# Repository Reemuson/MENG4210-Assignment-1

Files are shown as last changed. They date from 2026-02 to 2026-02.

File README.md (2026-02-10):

<p align="center" width="100%">
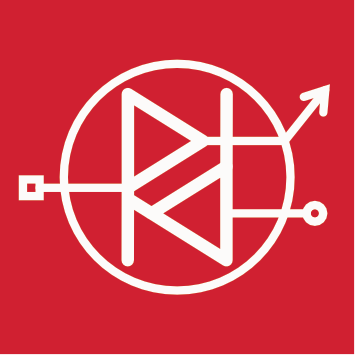
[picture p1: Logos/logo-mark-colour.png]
  
</p>

<h1 align="center">INPUT PROTECTION</h1>

<p align="center" width="100%">
  <a href="https://github.com/Reemuson/MENG4210-Assignment-1/actions/workflows/ci.yaml">
    
  </a>
</p>

<p align="center" width="100%">
    
</p>

***

<p align="center">
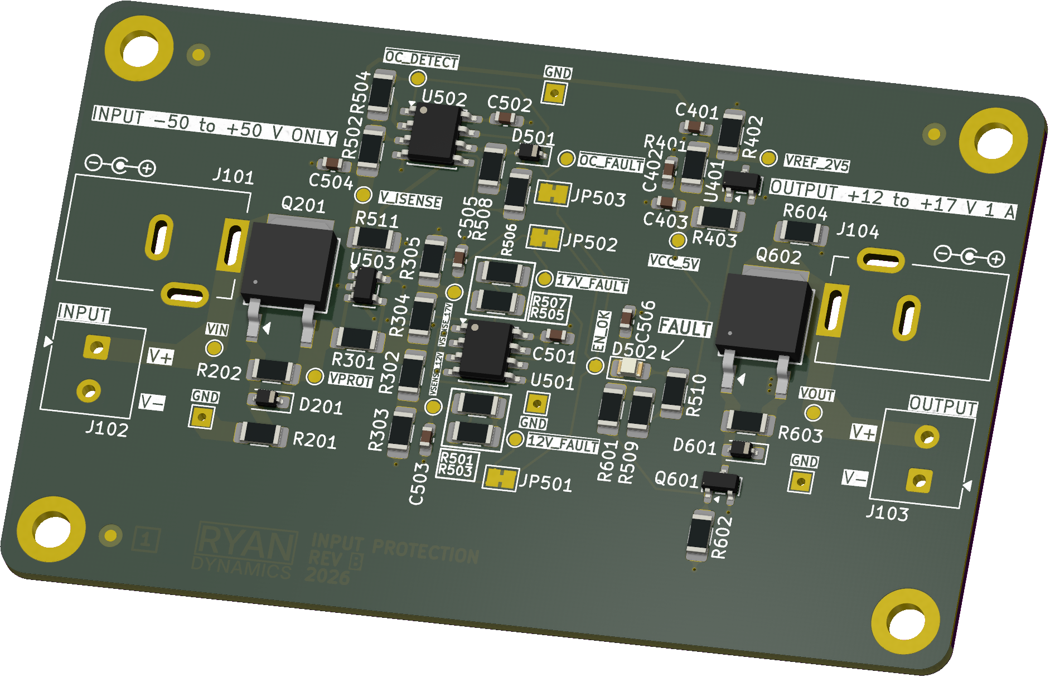
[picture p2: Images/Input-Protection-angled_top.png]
3D Top Angled
  
&nbsp; &nbsp; &nbsp; &nbsp;
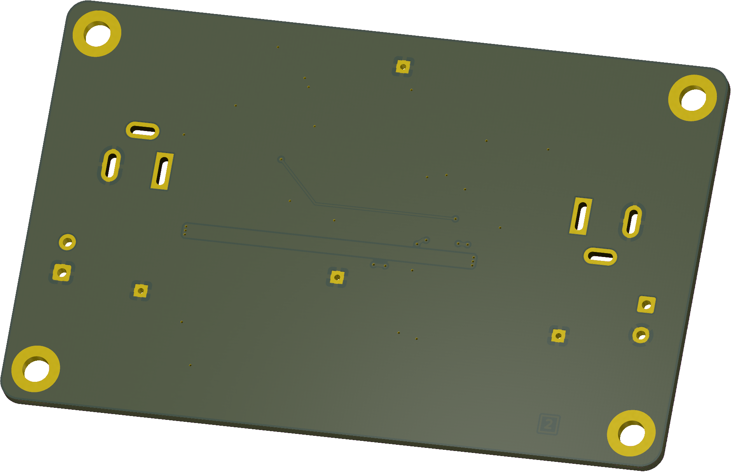
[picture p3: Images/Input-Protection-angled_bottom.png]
3D Bottom Angled
  
</p>

***

## SPECIFICATIONS

| Parameter | Value | 
| --- | --- |
| Dimensions | 80.0 × 50.0 mm |

***

## DIRECTORY STRUCTURE

    .
    ├─ Computations       # Misc calculations
    ├─ HTML               # HTML files for generated webpage
    ├─ Images             # Pictures and renders
    │
    ├─ kibot_resources    # External resources for KiBot
    │  ├─ colors          # Color theme for KiCad
    │  ├─ fonts           # Fonts used in the project
    │  ├─ scripts         # External scripts used with KiBot
    │  └─ templates       # Templates for KiBot generated reports
    │
    ├─ kibot_yaml         # KiBot YAML config files
    ├─ KiRI               # KiRI (PCB diff viewer) files
    │
    ├─ lib                # KiCad footprint and symbol libraries
    │  ├─ 3d_models       # Component 3D models
    │  ├─ lib_fp          # Footprint libraries
    │  └─ lib_sym         # Symbol libraries
    │
    ├─ Logos              # Logos
    │
    ├─ Manufacturing      # Assembly and fabrication documents
    │  ├─ Assembly        # Assembly documents (BoM, pos, notes)
    │  │
    │  └─ Fabrication     # Fabrication documents (ZIP, notes)
    │     ├─ Drill Tables # CSV drill tables
    │     └─ Gerbers      # Gerbers
    │
    ├─ Report             # Reports for ERC/DRC
    ├─ Schematic          # PDF of schematic
    ├─ Templates          # Title block templates
    ├─ Testing
    │  └─ Testpoints      # Testpoints tables      
    │
    └─ Variants           # Outputs for assembly variants

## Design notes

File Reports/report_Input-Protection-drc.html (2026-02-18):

Logo

(https://github.com/INTI-CMNB/KiBot/) | DRC report for Input-Protection
| PCB: Input-Protection Revision: 1.1.0 Date: 2026-02-18T01:36:54+0000 KiCad Version: 9.0.7 | Errors: 0 Warnings: 42 Total: 42

Violations

Type | Description | Details
lib_footprint_mismatch | Footprint 'R_1206_3216Metric_Pad1.30x1.75mm_HandSolder' does not match copy in library 'Resistor_SMD'. | @(155.065645 mm, 85.65 mm): Footprint R503
lib_footprint_mismatch | Footprint 'C_0603_1608Metric_Pad1.08x0.95mm_HandSolder' does not match copy in library 'Capacitor_SMD'. | @(160.528145 mm, 76.55 mm): Footprint C501
lib_footprint_mismatch | Footprint 'R_1206_3216Metric_Pad1.30x1.75mm_HandSolder' does not match copy in library 'Resistor_SMD'. | @(171.815646 mm, 57.599999 mm): Footprint R402
lib_footprint_mismatch | Footprint 'R_1206_3216Metric_Pad1.30x1.75mm_HandSolder' does not match copy in library 'Resistor_SMD'. | @(155.065645 mm, 64.65 mm): Footprint R506
lib_footprint_mismatch | Footprint 'R_1206_3216Metric_Pad1.30x1.75mm_HandSolder' does not match copy in library 'Resistor_SMD'. | @(149.065645 mm, 71.15 mm): Footprint R305
lib_footprint_mismatch | Footprint 'SOIC-8_3.9x4.9mm_P1.27mm' does not match copy in library 'Package_SO'. | @(155.065645 mm, 78.65 mm): Footprint U501
lib_footprint_mismatch | Footprint 'R_1206_3216Metric_Pad1.30x1.75mm_HandSolder' does not match copy in library 'Resistor_SMD'. | @(166.065645 mm, 82.200001 mm): Footprint R601
lib_footprint_mismatch | Footprint 'R_1206_3216Metric_Pad1.30x1.75mm_HandSolder' does not match copy in library 'Resistor_SMD'. | @(143.865646 mm, 69.9 mm): Footprint R511
lib_footprint_mismatch | Footprint 'R_1206_3216Metric_Pad1.30x1.75mm_HandSolder' does not match copy in library 'Resistor_SMD'. | @(152.565645 mm, 62.700001 mm): Footprint R508
lib_footprint_mismatch | Footprint 'C_0603_1608Metric_Pad1.08x0.95mm_HandSolder' does not match copy in library 'Capacitor_SMD'. | @(166.065645 mm, 74.537499 mm): Footprint C506
lib_footprint_mismatch | Footprint 'C_0603_1608Metric_Pad1.08x0.95mm_HandSolder' does not match copy in library 'Capacitor_SMD'. | @(153.028146 mm, 58.4 mm): Footprint C502
lib_footprint_mismatch | Footprint 'R_1206_3216Metric_Pad1.30x1.75mm_HandSolder' does not match copy in library 'Resistor_SMD'. | @(179.115646 mm, 65.4 mm): Footprint R604
lib_footprint_mismatch | Footprint 'C_0603_1608Metric_Pad1.08x0.95mm_HandSolder' does not match copy in library 'Capacitor_SMD'. | @(167.315646 mm, 61.4 mm): Footprint C402
lib_footprint_mismatch | Footprint 'C_0603_1608Metric_Pad1.08x0.95mm_HandSolder' does not match copy in library 'Capacitor_SMD'. | @(139.453144 mm, 63.9 mm): Footprint C504
lib_footprint_mismatch | Footprint 'R_1206_3216Metric_Pad1.30x1.75mm_HandSolder' does not match copy in library 'Resistor_SMD'. | @(177.565645 mm, 82.15 mm): Footprint R603
lib_footprint_mismatch | Footprint 'R_1206_3216Metric_Pad1.30x1.75mm_HandSolder' does not match copy in library 'Resistor_SMD'. | @(149.065645 mm, 81.15 mm): Footprint R302
lib_footprint_mismatch | Footprint 'R_1206_3216Metric_Pad1.30x1.75mm_HandSolder' does not match copy in library 'Resistor_SMD'. | @(155.065645 mm, 74.15 mm): Footprint R505
lib_footprint_mismatch | Footprint 'TerminalBlock_Phoenix_MKDS-1-2-3.81_1x02_P3.81mm_Horizontal' does not match copy in library 'TerminalBlock_Phoenix'. | @(122.565645 mm, 81.65 mm): Footprint J102
lib_footprint_mismatch | Footprint 'R_1206_3216Metric_Pad1.30x1.75mm_HandSolder' does not match copy in library 'Resistor_SMD'. | @(142.315645 mm, 57.4 mm): Footprint R504
lib_footprint_mismatch | Footprint 'C_0603_1608Metric_Pad1.08x0.95mm_HandSolder' does not match copy in library 'Capacitor_SMD'. | @(168.815646 mm, 57.4 mm): Footprint C401
lib_footprint_mismatch | Footprint 'R_1206_3216Metric_Pad1.30x1.75mm_HandSolder' does not match copy in library 'Resistor_SMD'. | @(149.065645 mm, 76.15 mm): Footprint R304
lib_footprint_mismatch | Footprint 'R_1206_3216Metric_Pad1.30x1.75mm_HandSolder' does not match copy in library 'Resistor_SMD'. | @(144.065645 mm, 78.65 mm): Footprint R301
lib_footprint_mismatch | Footprint 'R_1206_3216Metric_Pad1.30x1.75mm_HandSolder' does not match copy in library 'Resistor_SMD'. | @(137.565645 mm, 82.15 mm): Footprint R202
lib_footprint_mismatch | Footprint 'TerminalBlock_Phoenix_MKDS-1-2-3.81_1x02_P3.81mm_Horizontal' does not match copy in library 'TerminalBlock_Phoenix'. | @(192.565645 mm, 85.46 mm): Footprint J103
lib_footprint_mismatch | Footprint 'R_1206_3216Metric_Pad1.30x1.75mm_HandSolder' does not match copy in library 'Resistor_SMD'. | @(155.065645 mm, 71.65 mm): Footprint R507
lib_footprint_mismatch | Footprint 'C_0603_1608Metric_Pad1.08x0.95mm_HandSolder' does not match copy in library 'Capacitor_SMD'. | @(167.678148 mm, 64.15 mm): Footprint C403
lib_footprint_mismatch | Footprint 'LED_0805_2012Metric_Pad1.15x1.40mm_HandSolder' does not match copy in library 'LED_SMD'. | @(167.065645 mm, 78.65 mm): Footprint D502
lib_footprint_mismatch | Footprint 'R_1206_3216Metric_Pad1.30x1.75mm_HandSolder' does not match copy in library 'Resistor_SMD'. | @(172.015646 mm, 64.9625 mm): Footprint R403
lib_footprint_mismatch | Footprint 'R_1206_3216Metric_Pad1.30x1.75mm_HandSolder' does not match copy in library 'Resistor_SMD'. | @(155.065645 mm, 83.15 mm): Footprint R501
lib_footprint_mismatch | Footprint 'SOT-23' does not match copy in library 'Package_TO_SOT_SMD'. | @(176.315645 mm, 87.65 mm): Footprint Q601
lib_footprint_mismatch | Footprint 'R_1206_3216Metric_Pad1.30x1.75mm_HandSolder' does not match copy in library 'Resistor_SMD'. | @(168.565645 mm, 82.200001 mm): Footprint R509
lib_footprint_mismatch | Footprint 'SOIC-8_3.9x4.9mm_P1.27mm' does not match copy in library 'Package_SO'. | @(147.540645 mm, 60.515 mm): Footprint U502
lib_footprint_mismatch | Footprint 'SOT-23' does not match copy in library 'Package_TO_SOT_SMD'. | @(173.515646 mm, 61.7125 mm): Footprint U401
lib_footprint_mismatch | Footprint 'SOT-23-5' does not match copy in library 'Package_TO_SOT_SMD'. | @(144.065645 mm, 74.15 mm): Footprint U503
lib_footprint_mismatch | Footprint 'C_0603_1608Metric_Pad1.08x0.95mm_HandSolder' does not match copy in library 'Capacitor_SMD'. | @(151.315645 mm, 86.512501 mm): Footprint C503
lib_footprint_mismatch | Footprint 'R_1206_3216Metric_Pad1.30x1.75mm_HandSolder' does not match copy in library 'Resistor_SMD'. | @(171.065645 mm, 80.250002 mm): Footprint R510
lib_footprint_mismatch | Footprint 'R_1206_3216Metric_Pad1.30x1.75mm_HandSolder' does not match copy in library 'Resistor_SMD'. | @(137.515644 mm, 87.65 mm): Footprint R201
lib_footprint_mismatch | Footprint 'R_1206_3216Metric_Pad1.30x1.75mm_HandSolder' does not match copy in library 'Resistor_SMD'. | @(175.315645 mm, 92.200001 mm): Footprint R602
lib_footprint_mismatch | Footprint 'C_0603_1608Metric_Pad1.08x0.95mm_HandSolder' does not match copy in library 'Capacitor_SMD'. | @(151.315645 mm, 70.9 mm): Footprint C505
lib_footprint_mismatch | Footprint 'R_1206_3216Metric_Pad1.30x1.75mm_HandSolder' does not match copy in library 'Resistor_SMD'. | @(169.315645 mm, 60.700001 mm): Footprint R401
lib_footprint_mismatch | Footprint 'R_1206_3216Metric_Pad1.30x1.75mm_HandSolder' does not match copy in library 'Resistor_SMD'. | @(142.315645 mm, 62.300001 mm): Footprint R502
lib_footprint_mismatch | Footprint 'R_1206_3216Metric_Pad1.30x1.75mm_HandSolder' does not match copy in library 'Resistor_SMD'. | @(149.065645 mm, 86.15 mm): Footprint R303

Generated by KiBot (https://github.com/INTI-CMNB/KiBot/) v1.8.6

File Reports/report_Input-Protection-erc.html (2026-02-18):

Logo

(https://github.com/INTI-CMNB/KiBot/) | ERC report for Input-Protection
| Schematic: Input-Protection Revision: 1.1.0 Date: 2026-02-18T01:36:53+0000 KiCad Version: 9.0.7 | Errors: 0 Warnings: 33 Total: 33

Sheet / (Input-Protection.kicad_sch)

Type | Description | Details
footprint_link_issues | The current configuration does not include the footprint library 'RD-Testpoints'. | @(1.3843 mm, 0.7366 mm): Symbol TP102 [TestPoint]
footprint_link_issues | The current configuration does not include the footprint library 'RD-Testpoints'. | @(1.27 mm, 0.9398 mm): Symbol TP101 [TestPoint]
footprint_link_issues | The current configuration does not include the footprint library 'RD-Testpoints'. | @(1.6637 mm, 0.7366 mm): Symbol TP103 [TestPoint]
footprint_link_issues | The current configuration does not include the footprint library 'RD-Testpoints'. | @(1.778 mm, 0.9398 mm): Symbol TP104 [TestPoint]
footprint_link_issues | The current configuration does not include the footprint library 'RD-Testpoints'. | @(1.3843 mm, 0.9398 mm): Symbol TP401 [TestPoint]
footprint_link_issues | The current configuration does not include the footprint library 'RD-Testpoints'. | @(1.8288 mm, 0.8001 mm): Symbol TP402 [TestPoint]
footprint_link_issues | The current configuration does not include the footprint library 'RD-Testpoints'. | @(1.651 mm, 0.5969 mm): Symbol TP201 [TestPoint]
footprint_link_issues | The current configuration does not include the footprint library 'RD-Testpoints'. | @(1.2954 mm, 0.9652 mm): Symbol TP301 [TestPoint]
footprint_link_issues | The current configuration does not include the footprint library 'RD-Testpoints'. | @(1.4351 mm, 0.7493 mm): Symbol TP302 [TestPoint]
footprint_link_issues | The current configuration does not include the footprint library 'RD-Testpoints'. | @(1.7272 mm, 0.7493 mm): Symbol TP303 [TestPoint]
footprint_link_issues | The current configuration does not include the footprint library 'RD-Symbols-Silkscreen'. | @(1.397 mm, 0.7747 mm): Symbol ID901 [BOARD_STACKUP_MARKER]
lib_symbol_issues | The current configuration does not include the symbol library 'Ryan-Dynamics' | @(1.397 mm, 0.7747 mm): Symbol ID901 [BOARD_STACKUP_MARKER]
lib_symbol_mismatch | Symbol 'BC846' doesn't match copy in library 'Transistor_BJT' | @(1.4986 mm, 1.0541 mm): Symbol Q601 [BC846]
footprint_link_issues | The current configuration does not include the footprint library 'RD-Testpoints'. | @(1.0922 mm, 1.6891 mm): Symbol TP507 [TestPoint]
footprint_link_issues | The current configuration does not include the footprint library 'RD-Testpoints'. | @(1.7907 mm, 1.0033 mm): Symbol TP501 [TestPoint]
footprint_link_issues | The current configuration does not include the footprint library 'RD-Testpoints'. | @(1.7907 mm, 1.6002 mm): Symbol TP502 [TestPoint]
footprint_link_issues | The current configuration does not include the footprint library 'RD-Testpoints'. | @(2.4638 mm, 1.0033 mm): Symbol TP503 [TestPoint]
footprint_link_issues | The current configuration does not include the footprint library 'RD-Testpoints'. | @(2.4892 mm, 1.6002 mm): Symbol TP504 [TestPoint]
endpoint_off_grid | Symbol pin or wire end off connection grid | @(2.6416 mm, 1.3081 mm): Vertical Wire, length 0.1842 mm
endpoint_off_grid | Symbol pin or wire end off connection grid | @(2.6416 mm, 1.49225 mm): Symbol JP501 Pin 2 [B, Passive, Line]
endpoint_off_grid | Symbol pin or wire end off connection grid | @(2.6416 mm, 1.56845 mm): Vertical Wire, length 0.0571 mm
endpoint_off_grid | Symbol pin or wire end off connection grid | @(2.7305 mm, 1.49225 mm): Symbol JP502 Pin 2 [B, Passive, Line]
endpoint_off_grid | Symbol pin or wire end off connection grid | @(2.7305 mm, 1.3081 mm): Vertical Wire, length 0.1842 mm
endpoint_off_grid | Symbol pin or wire end off connection grid | @(2.7305 mm, 1.6256 mm): Vertical Wire, length 0.0571 mm
endpoint_off_grid | Symbol pin or wire end off connection grid | @(2.8194 mm, 1.3081 mm): Vertical Wire, length 0.1842 mm
endpoint_off_grid | Symbol pin or wire end off connection grid | @(2.8194 mm, 1.49225 mm): Symbol JP503 Pin 2 [B, Passive, Line]
footprint_link_issues | The current configuration does not include the footprint library 'RD-Testpoints'. | @(3.0353 mm, 1.0033 mm): Symbol TP505 [TestPoint]
endpoint_off_grid | Symbol pin or wire end off connection grid | @(2.8194 mm, 1.6256 mm): Vertical Wire, length 0.0571 mm
endpoint_off_grid | Symbol pin or wire end off connection grid | @(2.8956 mm, 1.51765 mm): Symbol R509 Pin 2 [Passive, Line]
endpoint_off_grid | Symbol pin or wire end off connection grid | @(2.8956 mm, 1.51765 mm): Vertical Wire, length 0.1080 mm
endpoint_off_grid | Symbol pin or wire end off connection grid | @(2.8956 mm, 1.59385 mm): Vertical Wire, length 0.0318 mm
footprint_link_issues | The current configuration does not include the footprint library 'RD-Testpoints'. | @(3.1115 mm, 1.6256 mm): Symbol TP506 [TestPoint]

Sheet /ARCHITECTURE/3. SENSING/ (Sensing.kicad_sch)

Type | Description | Details
multiple_net_names | Both ISENSE_P and VPROT are attached to the same items; ISENSE_P will be used in the netlist | @(1.0414 mm, 0.7239 mm): Hierarchical Label 'ISENSE_P' @(0.9271 mm, 0.5969 mm): Hierarchical Label 'VPROT'

Generated by KiBot (https://github.com/INTI-CMNB/KiBot/) v1.8.6

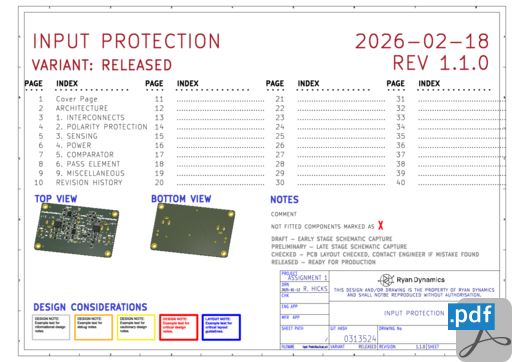
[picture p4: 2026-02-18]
HTML/images/cat_pdf_schematic_Input-Protection-schematic.png

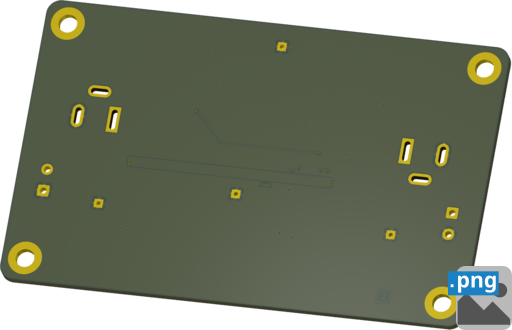
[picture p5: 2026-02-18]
HTML/images/cat_png_3d_viewer_angled_bottom_Input-Protection-angled_bottom.png

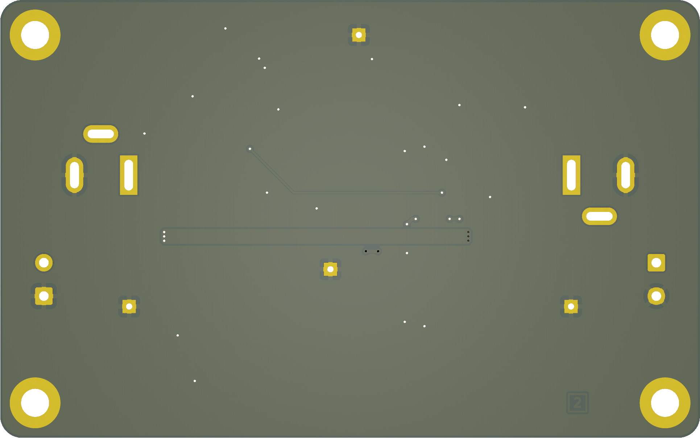
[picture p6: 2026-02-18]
Images/Input-Protection-bottom.png

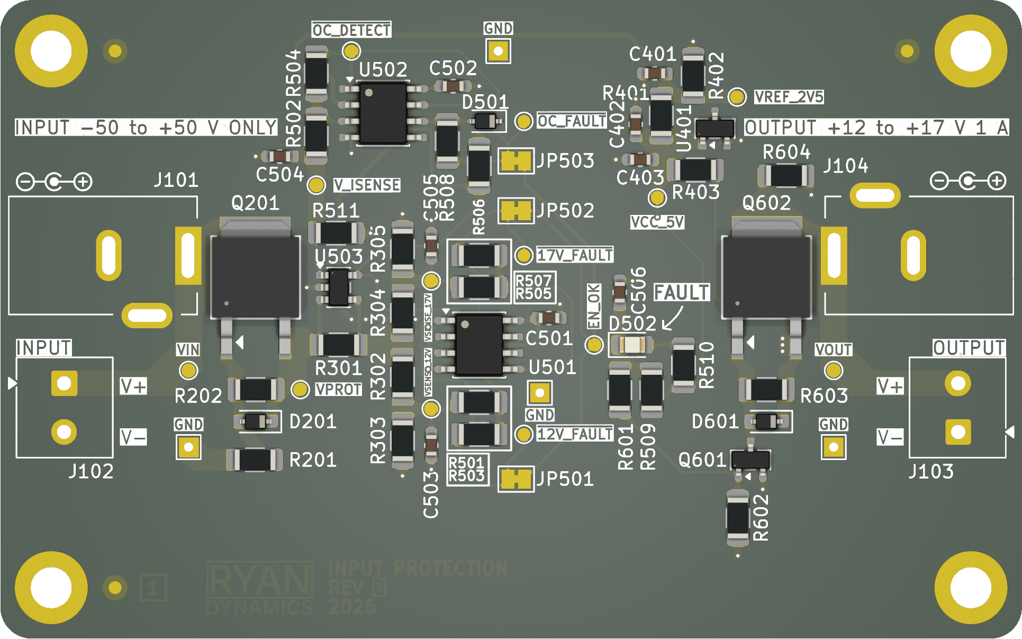
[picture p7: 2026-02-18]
Images/Input-Protection-top.png

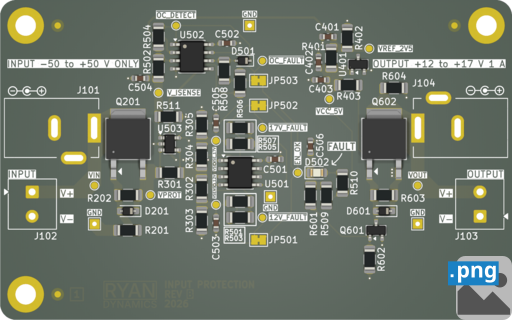
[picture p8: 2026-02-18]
HTML/images/cat_png_3d_viewer_top_Input-Protection-top.png

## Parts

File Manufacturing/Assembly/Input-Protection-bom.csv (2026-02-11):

Row | Quantity Per PCB | References | Value | Datasheet | Footprint | Description | Manufacturer | MPN | Supplier | Supplier Part Number | Notes
1 | 4 | C401 C503 C504 C505 | 10n | https://mm.digikey.com/Volume0/opasdata/d220001/medias/docus/931/C_Series_GeneralAppl_B11.pdf | C_0603_1608Metric_Pad1.08x0.95mm_HandSolder | CAP CER 0.01UF 50V X7R 0603 | TPK | C1608X7R1H103KT
2 | 3 | C403 C501 C502 | 100n | https://mm.digikey.com/Volume0/opasdata/d220001/medias/docus/931/C_Series_GeneralAppl_B11.pdf | C_0603_1608Metric_Pad1.08x0.95mm_HandSolder | CAP CER 0.1UF 16V X7R 0603 | TPK | C1608X7R1C104KT
3 | 2 | C402 C506 | 1u | https://mm.digikey.com/Volume0/opasdata/d220001/medias/docus/931/C_Series_GeneralAppl_B11.pdf | C_0603_1608Metric_Pad1.08x0.95mm_HandSolder | CAP CER 1UF 50V X7R 0603 | TPK | C1608X5R0J105KT
4 | 1 | D501 | 1N4148WS | https://diotec.com/request/datasheet/1n4148ws.pdf | D_SOD-323 | DIODE STANDARD 75V 150MA SOD323F | Diotec Semiconductor | 1N4148WS |  |  | Fast switching diode, low leakage, used for diode-AND logic gating of control signals
5 | 2 | D201 D601 | D3Z10BF-7 | https://www.diodes.com/assets/Datasheets/D3ZxVxBF.pdf | D_SOD-323_HandSoldering | DIODE ZENER 10V 400MW SOD323F | Diodes Incorporated | D3Z10BF-7 |  |  | VZ = 10 V, suitable for input over-voltage clamping
6 | 1 | D502 | LED | https://optoelectronics.liteon.com/upload/download/DS-22-99-0150/LTST-C170KRKT.pdf | LED_0805_2012Metric_Pad1.15x1.40mm_HandSolder | LED RED CLEAR SMD | Lite-On Inc. | LTST-C170KRKT |  |  | Any low power red 0805 LED
7 | 2 | J102 J103 | EBWA-02-B | https://app.adam-tech.com/products/download/data_sheet/204240/ebwa-xx-b-data-sheet.pdf | TerminalBlock_Phoenix_MKDS-1-2-3.81_1x02_P3.81mm_Horizontal | EURO BLOCK 2P | Adam Tech | EBWA-02-B
8 | 2 | J101 J104 | KLDX-0202-B | https://www.kycon.com/Catalog_PDF/KLDX_0202.pdf | BarrelJack_Kycon_KLDX-0202-xC_Horizontal | CONN PWR JACK 2.5X5.5MM SOLDER | Kycon Inc | KLDX-0202-B
9 | 1 | Q601 | BC846 | https://assets.nexperia.com/documents/data-sheet/BC846X-Q_SER.pdf | SOT-23 | TRANS NPN 65V 0.1A TO-236AB | Nexperia USA Inc. | BC846 |  |  | VCEO > 65 V for 50 V rail, IC small, used as gate pull-down switch
10 | 2 | Q201 Q602 | MCU18P10Y-TP | https://www.mccsemi.com/pdf/Products/MCU18P10Y(DPAK).pdf | DPAK_MCC | MOSFET P-CH 100V 18A DPAK | MCC (Micro Commercial Components) | MCU18P10Y-TP |  |  | VDS > 100 V, ID > 2 A, P-channel device suitable for high-side switching
11 | 1 | R301 | 100m | https://www.ohmite.com/assets/images/res-kdv.pdf | R_1206_3216Metric_Pad1.30x1.75mm_HandSolder | RES 0.1 OHM 1% 1/2W 1206 | Ohmite | KDV12FR100ET |  |  | Current sense shunt, sets OCP trip (~1 A). Ideally should be <100m
12 | 3 | R501 R502 R505 | 1k | https://www.analogtechnologies.com/document/New_Resistor_Kits.pdf | R_1206_3216Metric_Pad1.30x1.75mm_HandSolder | RES 1K OHM 1% 1/4W 1206 | Analog Technologies
13 | 2 | R403 R510 | 3.32k | https://www.analogtechnologies.com/document/New_Resistor_Kits.pdf | R_1206_3216Metric_Pad1.30x1.75mm_HandSolder | RES 3.32K OHM 1% 1/4W 1206 | Analog Technologies
14 | 5 | R303 R305 R508 R509 R601 | 10k | https://www.analogtechnologies.com/document/New_Resistor_Kits.pdf | R_1206_3216Metric_Pad1.30x1.75mm_HandSolder | RES 10K OHM 1% 1/4W 1206 | Analog Technologies
15 | 1 | R511 | 22.1k | https://www.analogtechnologies.com/document/New_Resistor_Kits.pdf | R_1206_3216Metric_Pad1.30x1.75mm_HandSolder | RES 22.1K OHM 1% 1/4W 1206 | Analog Technologies
16 | 1 | R302 | 39.2k | https://www.analogtechnologies.com/document/New_Resistor_Kits.pdf | R_1206_3216Metric_Pad1.30x1.75mm_HandSolder | RES 39.2K OHM 1% 1/4W 1206 | Analog Technologies
17 | 1 | R304 | 56.2k | https://www.analogtechnologies.com/document/New_Resistor_Kits.pdf | R_1206_3216Metric_Pad1.30x1.75mm_HandSolder | RES 56.2K OHM 1% 1/4W 1206 | Analog Technologies
18 | 7 | R201 R202 R401 R402 R506 R602 R603 | 100k | https://www.analogtechnologies.com/document/New_Resistor_Kits.pdf | R_1206_3216Metric_Pad1.30x1.75mm_HandSolder | RES 100K OHM 1% 1/4W 1206 | Analog Technologies
19 | 4 | R503 R504 R507 R604 | 1M | https://www.analogtechnologies.com/document/New_Resistor_Kits.pdf | R_1206_3216Metric_Pad1.30x1.75mm_HandSolder | RES 1M OHM 1% 1/4W 1206 | Analog Technologies
20 | 1 | U503 | INA169NA/3K | http://www.ti.com/lit/ds/symlink/ina169.pdf | SOT-23-5 | IC CURRENT MONITOR 0.5% SOT23-5 | Texas Instruments | INA169NA/3K |  |  | Transconductance of 1mA/V
21 | 2 | U501 U502 | LM393 | http://www.ti.com/lit/ds/symlink/lm393.pdf | SOIC-8_3.9x4.9mm_P1.27mm | IC COMPARATOR 2 GEN PUR 8SOIC | Texas Instruments | LM393ADT |  |  | Open-collector output required, >5V tolerant inputs.
22 | 1 | U401 | LM4040N-5.0 | http://www.ti.com/lit/ds/symlink/lm4040-n.pdf | SOT-23 | IC VREF SHUNT 0.5% SOT23-3 | Texas Instruments | LM4040CIM3-5.0/NOPB |  |  | VREF = 5.0 V, low temperature coefficient, suitable for precision threshold VREF

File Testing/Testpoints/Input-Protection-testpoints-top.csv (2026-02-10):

Ref. | Net | X [mm] | Y [mm]
TP101 | GND | 14.75 | 15.00
TP102 | VIN | 14.75 | 21.00
TP103 | VOUT | 65.25 | 21.00
TP104 | GND | 65.25 | 15.00
TP201 | VPROT | 23.50 | 19.50
TP301 | GND | 42.25 | 19.25
TP302 | VSENSE_12V | 33.75 | 18.00
TP303 | VSENSE_17V | 33.75 | 28.00
TP401 | VREF_2V5 | 57.70 | 42.40
TP402 | VCC_5V | 51.45 | 34.50
TP501 | ~{12V_FAULT} | 41.00 | 16.00
TP502 | ~{OC_DETECT} | 27.50 | 46.00
TP503 | ~{17V_FAULT} | 41.00 | 30.00
TP504 | ~{OC_FAULT} | 41.00 | 40.50
TP505 | V_ISENSE | 24.75 | 35.50
TP506 | EN_OK | 46.50 | 23.00
TP507 | GND | 39.00 | 46.00

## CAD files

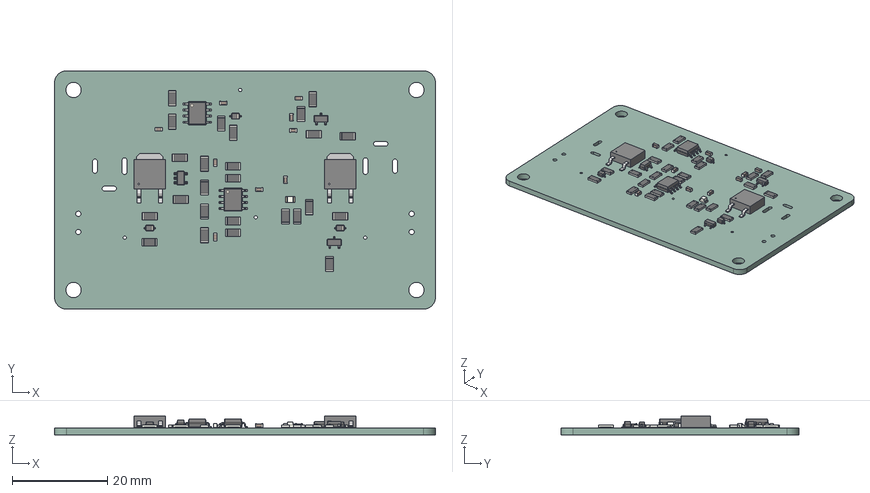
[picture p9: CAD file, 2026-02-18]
3D/Input-Protection.step
80.0 x 50.0 x 3.96 mm
D_SOD-323 x 3
R_1206_3216Metric x 25
C_0603_1608Metric x 9
DPAK_MCC x 2
SOIC-8_3.9x4.9mm_P1.27mm x 2
LED_0805_2012Metric
SOT-23 x 2
SOT-23-5
kibot_h5hh2qnl_PCB

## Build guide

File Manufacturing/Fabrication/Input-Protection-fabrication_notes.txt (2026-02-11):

FABRICATION NOTES (UNLESS OTHERWISE SPECIFIED)

1)	FABRICATE PER IPC-6012A CLASS 2.

2)	OUTLINE DEFINED IN SEPARATE GERBER FILE WITH
	"Edge_Cuts.GBR" SUFFIX.

3)	SEE SEPARATE DRILL FILES WITH ".DRL" SUFFIX 
	FOR HOLE LOCATIONS.

4)	SURFACE FINISH: ENIG

5)	SOLDERMASK ON BOTH SIDES OF THE BOARD SHALL 
	BE LPI, COLOR GREEN.

6)	SILK SCREEN LEGEND TO BE APPLIED PER LAYER 
	STACKUP USING WHITE NON-CONDUCTIVE EPOXY INK.

7)	VENDOR SHOULD FOLLOW ROHS COMPLIANT PROCESS 
	AND Pb FREE FOR MANUFACTURING

8)	PCB MATERIAL REQUIREMENTS:

	A.	FLAMMABILITY RATING MUST MEET OR EXCEED 
		UL94V-0 REQUIREMENTS.
	B.	Tg 170 C OR EQUIVALENT.
	C.	EQUIVALENT MATERIAL SHALL BE RoHS COMPLIANT, 
		HALOGEN FREE AND APPROVED BY RYAN DYNAMICS.

9)	DESIGN GEOMETRY MINIMUM FEATURE SIZES:

	BOARD SIZE			80.000 × 50.000 mm
	BOARD THICKNESS		1.590 mm
	TRACE WIDTH			0.200 mm
	TRACE TO TRACE		-0.000 mm
	MIN. HOLE (PTH)		0.250 mm
	MIN. HOLE (NPTH)	N/A mm
	ANNULAR RING		0.150 mm
	COPPER TO HOLE		0.254 mm
	COPPER TO EDGE		0.250 mm
	HOLE TO HOLE		0.254 mm

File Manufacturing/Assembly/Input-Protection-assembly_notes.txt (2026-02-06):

ASSEMBLY NOTES (UNLESS OTHERWISE SPECIFIED)

1)	DO NOT POPULATE PARTS ARE MARKED WITH A RED CROSS.

2)	DO NOT POPULATE PARTS ARE NOT PRESENT IN THE BOM.

3)	IF CONFLICTING INFORMATION IS FOUND BETWEEN THE ASSEMBLY
	FILE AND BOM, BOM SHOULD BE USED AS THE MAIN SOURCE.

4)	CONFORMAL COATING IS NOT REQUIRED.

5)	DOT IDENTIFIES PIN #1 LOCATION AND DEVICE ORIENTATION
	WHEN VIEWED FROM THE TOP.

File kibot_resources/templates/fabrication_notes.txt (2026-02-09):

FABRICATION NOTES (UNLESS OTHERWISE SPECIFIED)

1)	FABRICATE PER IPC-6012A CLASS 2.

2)	OUTLINE DEFINED IN SEPARATE GERBER FILE WITH
	"Edge_Cuts.GBR" SUFFIX.

3)	SEE SEPARATE DRILL FILES WITH ".DRL" SUFFIX 
	FOR HOLE LOCATIONS.

4)	SURFACE FINISH: ${pcb_finish_cap}

5)	SOLDERMASK ON BOTH SIDES OF THE BOARD SHALL 
	BE LPI, COLOR ${solder_mask_color_text_cap}.

6)	SILK SCREEN LEGEND TO BE APPLIED PER LAYER 
	STACKUP USING ${silk_screen_color_text_cap} NON-CONDUCTIVE EPOXY INK.

7)	VENDOR SHOULD FOLLOW ROHS COMPLIANT PROCESS 
	AND Pb FREE FOR MANUFACTURING

8)	PCB MATERIAL REQUIREMENTS:

	A.	FLAMMABILITY RATING MUST MEET OR EXCEED 
		UL94V-0 REQUIREMENTS.
	B.	Tg 170 C OR EQUIVALENT.
	C.	EQUIVALENT MATERIAL SHALL BE RoHS COMPLIANT, 
		HALOGEN FREE AND APPROVED BY ${COMPANY_cap}.

9)	DESIGN GEOMETRY MINIMUM FEATURE SIZES:

	BOARD SIZE			${bb_w_mm} × ${bb_h_mm} mm
	BOARD THICKNESS		${thickness_mm} mm
	TRACE WIDTH			${track_mm} mm
	TRACE TO TRACE		${clearance_mm} mm
	MIN. HOLE (PTH)		${drill_pth_real_mm} mm
	MIN. HOLE (NPTH)	${drill_npth_real_mm} mm
	ANNULAR RING		${oar_mm} mm
	COPPER TO HOLE		${c2h_mm} mm
	COPPER TO EDGE		${c2e_mm} mm
	HOLE TO HOLE		${h2h_mm} mm
#?stackup and impedance_controlled

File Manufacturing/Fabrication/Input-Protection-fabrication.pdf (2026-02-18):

# TOP FABRICATION (SCALE 1:1)

# INPUT PROTECTION FABRICATION DOCUMENT

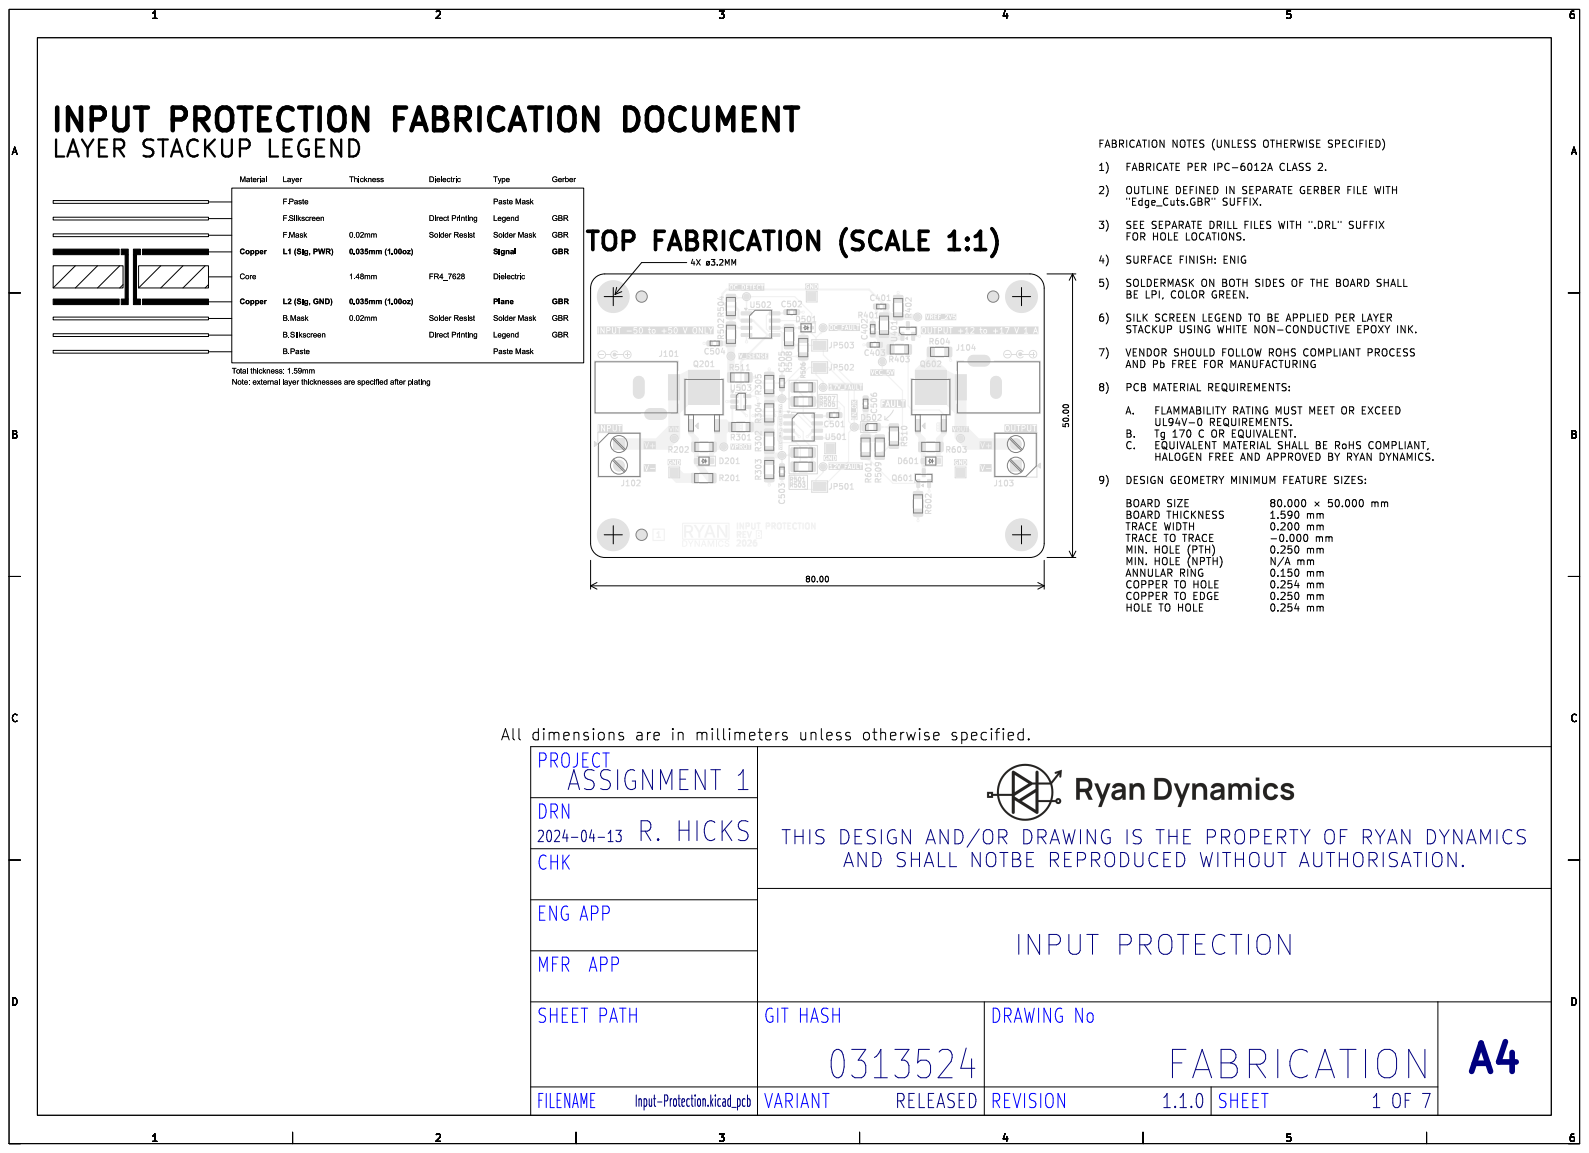
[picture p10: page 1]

FABRICATION NOTES (UNLESS OTHERWISE SPECIFIED)

1) FABRICATE PER IPC-6012A CLASS 2.

2) OUTLINE DEFINED IN SEPARATE GERBER FILE WITH
"Edge_Cuts.GBR" SUFFIX.

3) SEE SEPARATE DRILL FILES WITH ".DRL" SUFFIX
FOR HOLE LOCATIONS.

5) SOLDERMASK ON BOTH SIDES OF THE BOARD SHALL
BE LPI, COLOR GREEN.

6) SILK SCREEN LEGEND TO BE APPLIED PER LAYER
STACKUP USING WHITE NON-CONDUCTIVE EPOXY INK.

7) VENDOR SHOULD FOLLOW ROHS COMPLIANT PROCESS
AND Pb FREE FOR MANUFACTURING

A. FLAMMABILITY RATING MUST MEET OR EXCEED
UL94V-0 REQUIREMENTS.
B. Tg 170 C OR EQUIVALENT.
C. EQUIVALENT MATERIAL SHALL BE RoHS COMPLIANT,
HALOGEN FREE AND APPROVED BY RYAN DYNAMICS.

9) DESIGN GEOMETRY MINIMUM FEATURE SIZES:

BOARD SIZE 80.000 × 50.000 mm
BOARD THICKNESS 1.590 mm
TRACE WIDTH 0.200 mm
TRACE TO TRACE -0.000 mm
MIN. HOLE (PTH) 0.250 mm
MIN. HOLE (NPTH) N/A mm
ANNULAR RING 0.150 mm
COPPER TO HOLE 0.254 mm
COPPER TO EDGE 0.250 mm
HOLE TO HOLE 0.254 mm

All dimensions are in millimeters unless otherwise specified.
PROJECT
ASSIGNMENT 1
DRN
THIS DESIGN AND/OR DRAWING IS THE PROPERTY OF RYAN DYNAMICSAND SHALL NOTBE REPRODUCED WITHOUT AUTHORISATION.
CHK

BOTTOM | FABRICATION | (SCALE | 1:1)
INPUT | PROTECTION | FABRICATION DOCUMENT

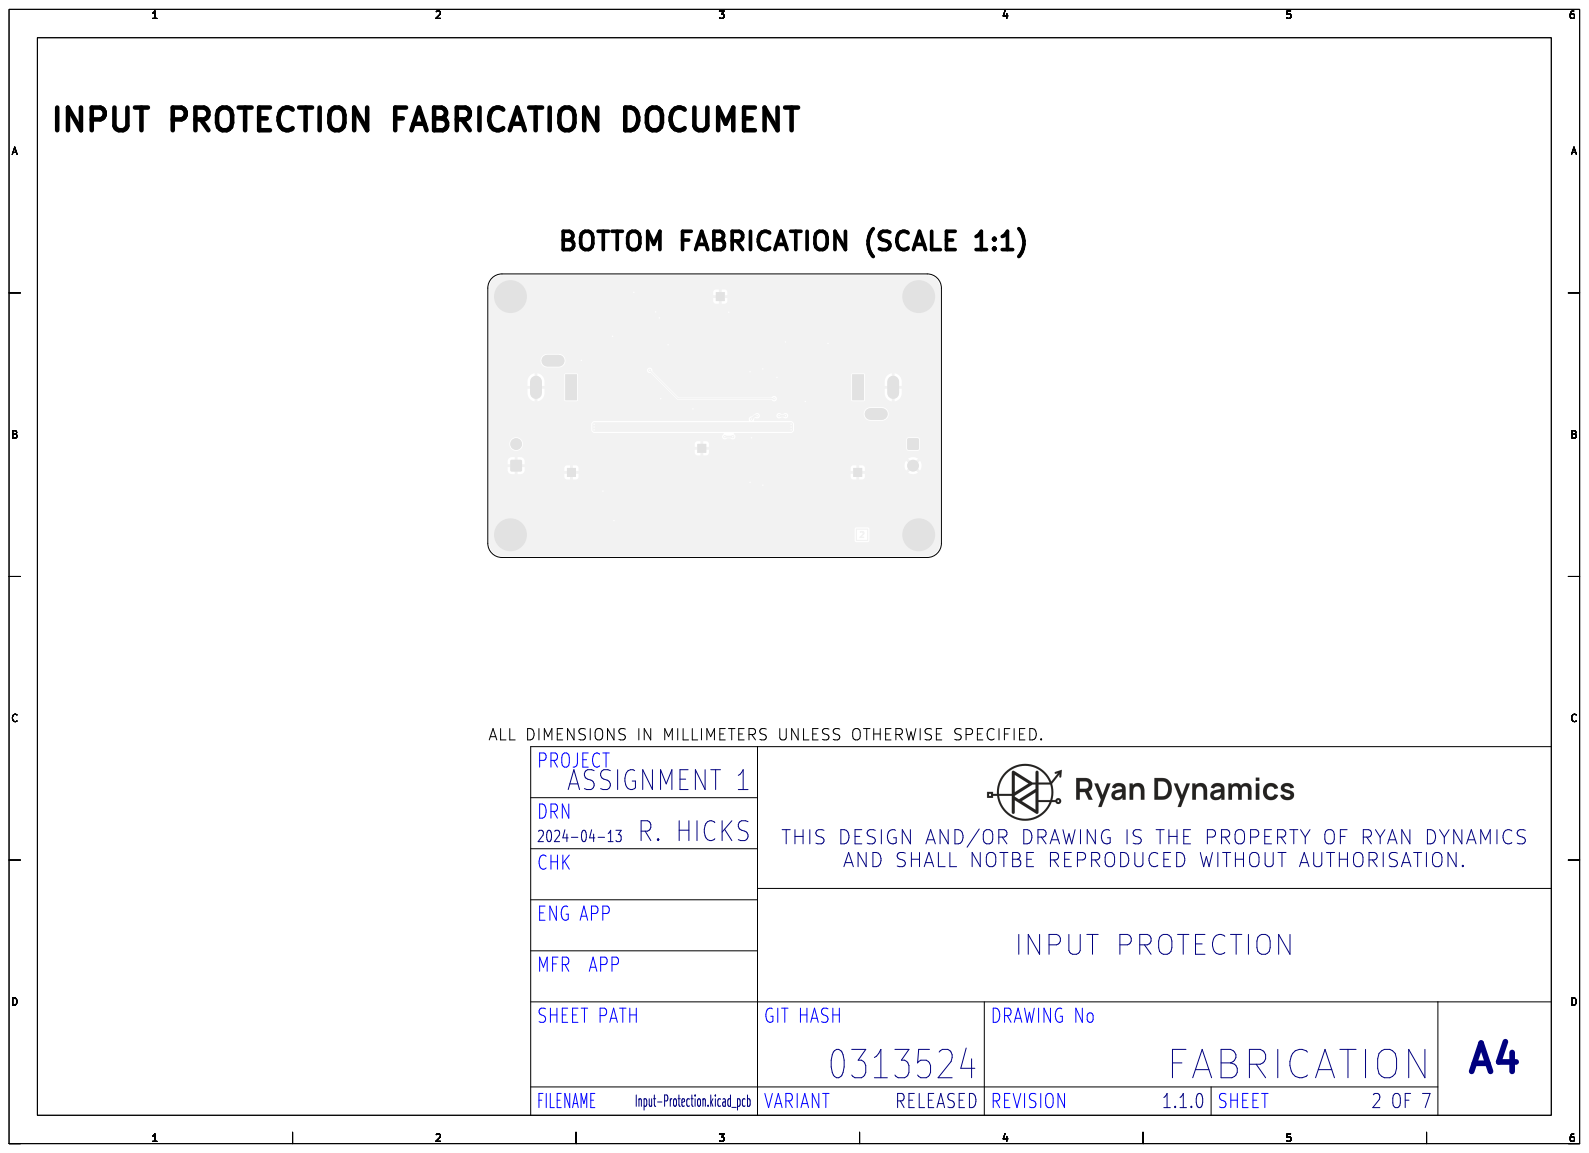
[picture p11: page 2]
DRAWING No; ASSIGNMENT 1; FABRICATION; PROJECT; INPUT; PROTECTION; ENG APP; 2024-04-13 CHK; GIT; HASH; SHEET; PATH; MFR; APP; DRN; R. HICKS; THIS DESIGN AND/OR; DRAWING IS THE PROPERTY OF RYAN DYNAMICSAND SHALL NOTBE REPRODUCED WITHOUT AUTHORISATION.; ALL; DIMENSIONS; MILLIMETERS; UNLESS OTHERWISE; SPECIFIED.

DRILL | DRAWING L1 - L2 (SCALE | 1:1)
INPUT | PROTECTION | FABRICATION DOCUMENT

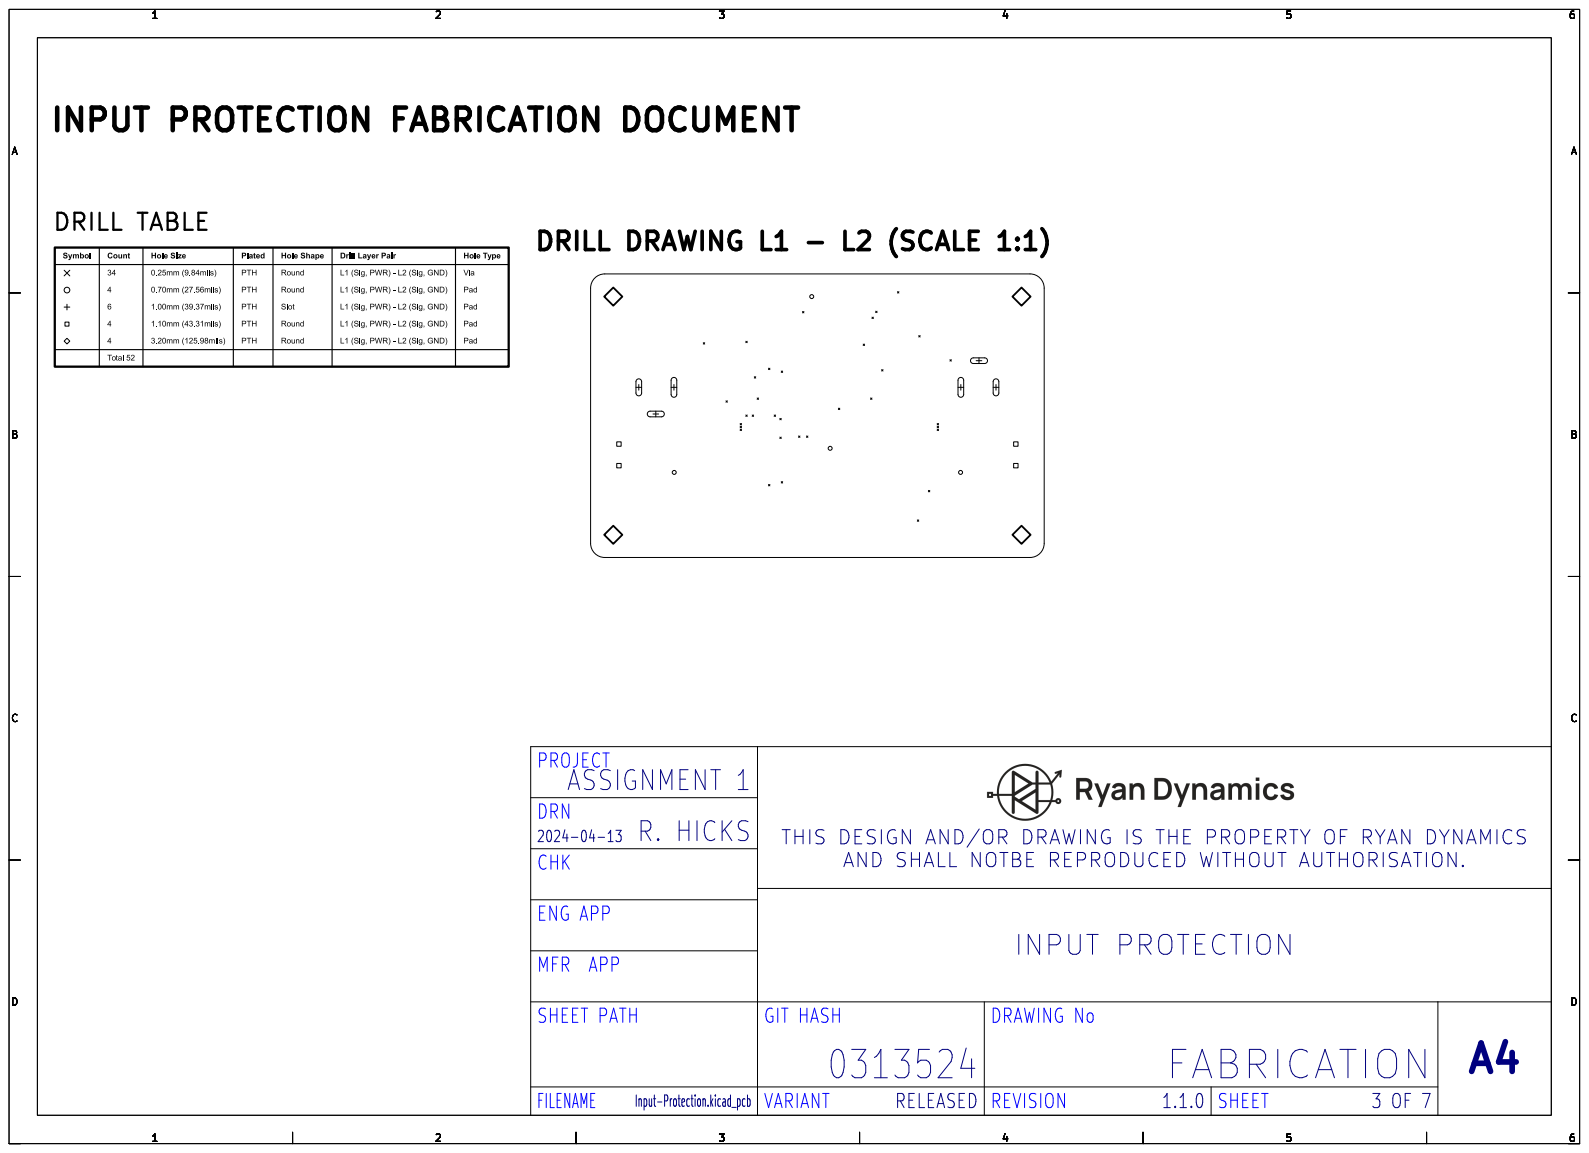
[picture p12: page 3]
DRAWING No; ASSIGNMENT 1; FABRICATION; PROJECT; INPUT; PROTECTION; ENG APP; 2024-04-13 CHK; GIT; HASH; SHEET; PATH; MFR; APP; DRN; R. HICKS; THIS DESIGN AND/OR; DRAWING IS THE PROPERTY OF RYAN DYNAMICSAND SHALL NOTBE REPRODUCED WITHOUT AUTHORISATION.; DRILL TABLE

# TOP TEST POINTS (SCALE 1:1)

# INPUT PROTECTION FABRICATION DOCUMENT

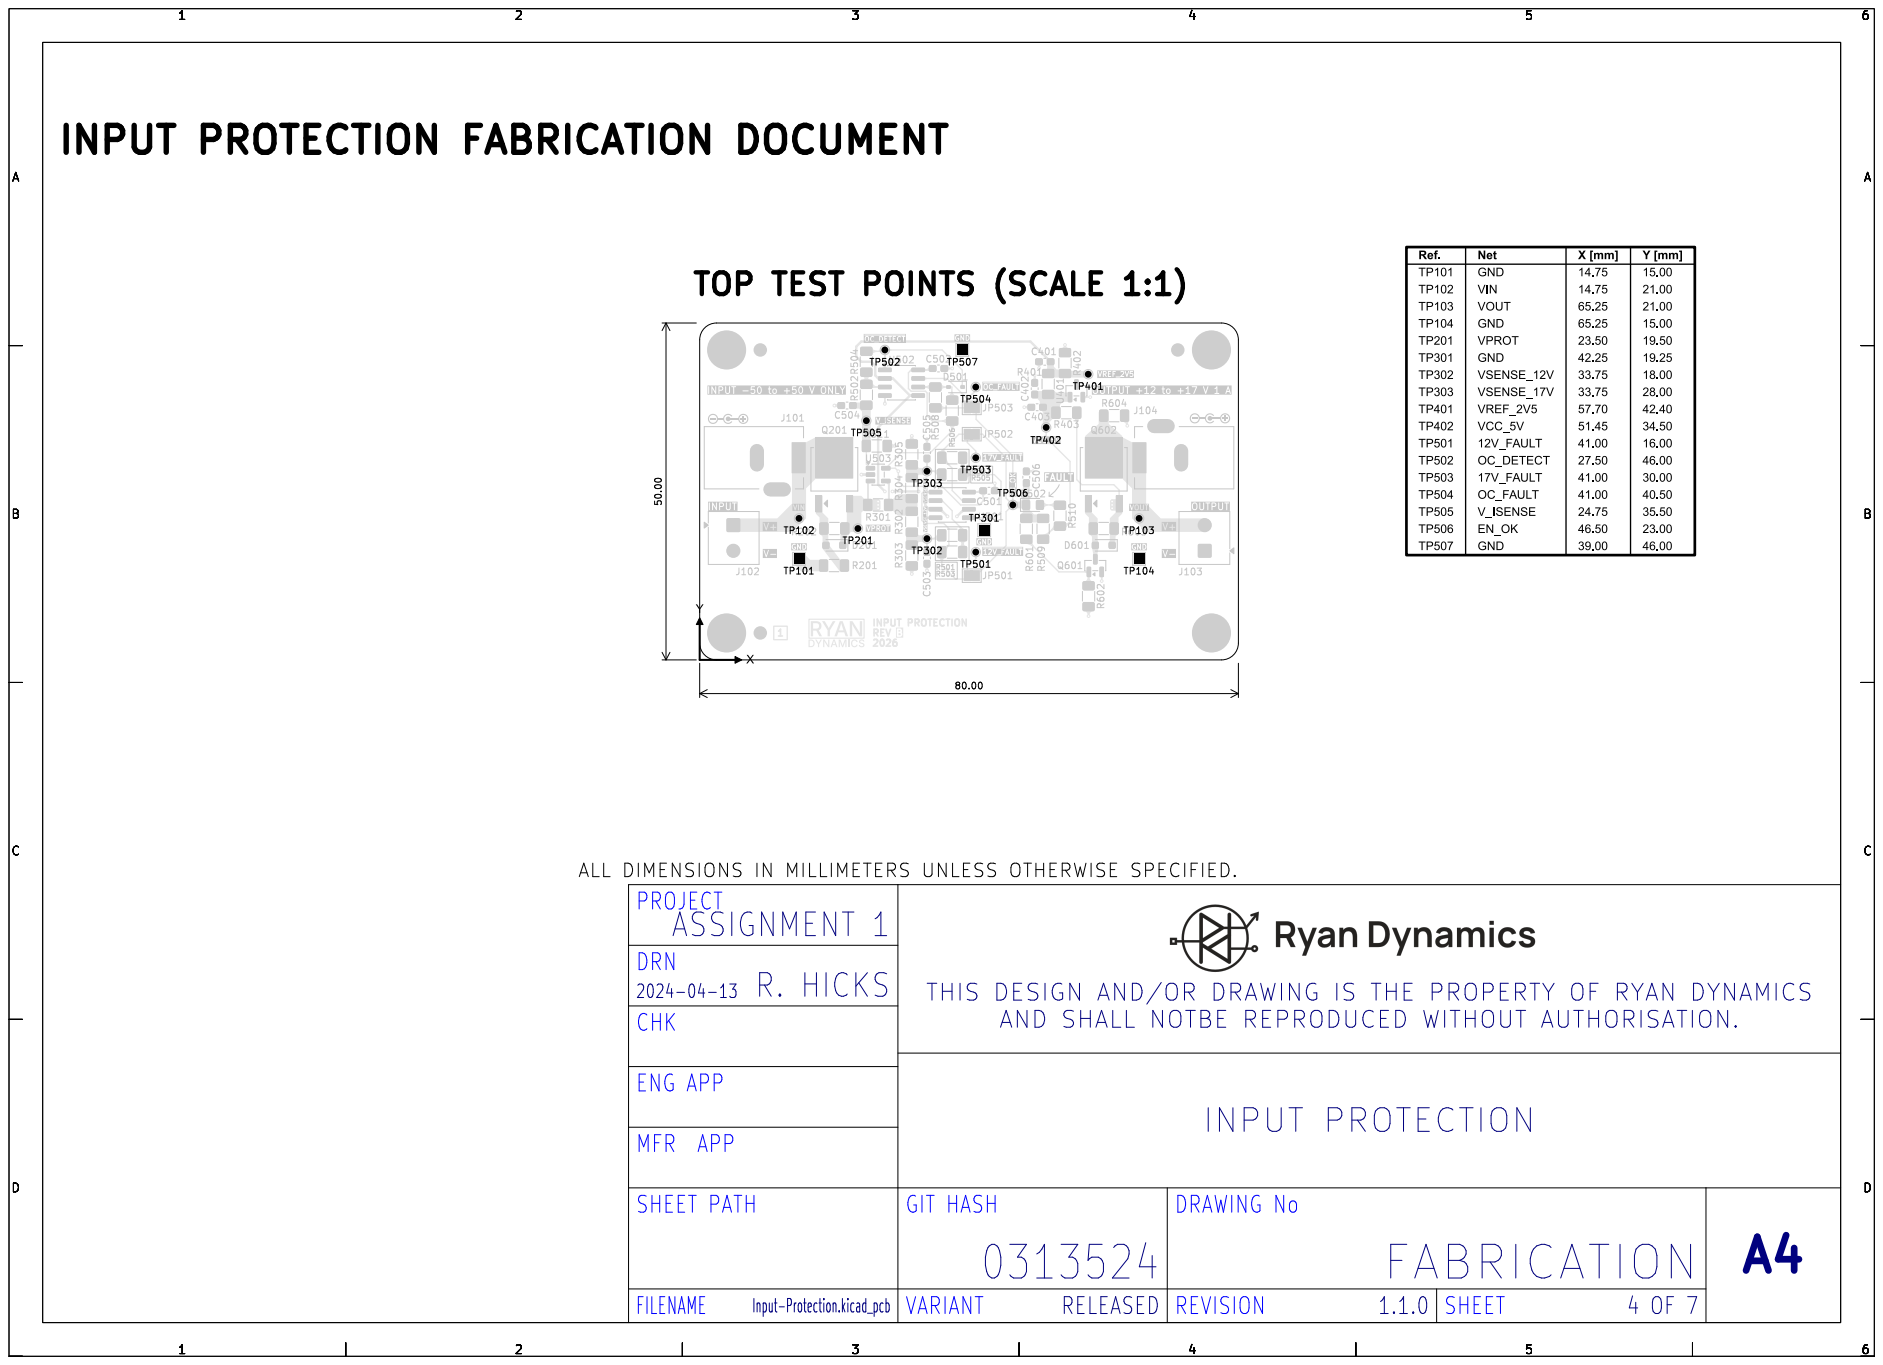
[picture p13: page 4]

PROJECT
ASSIGNMENT 1
DRN
THIS DESIGN AND/OR DRAWING IS THE PROPERTY OF RYAN DYNAMICSAND SHALL NOTBE REPRODUCED WITHOUT AUTHORISATION.
CHK

BOTTOM | TEST POINTS (SCALE | 1:1)
INPUT | PROTECTION | FABRICATION DOCUMENT

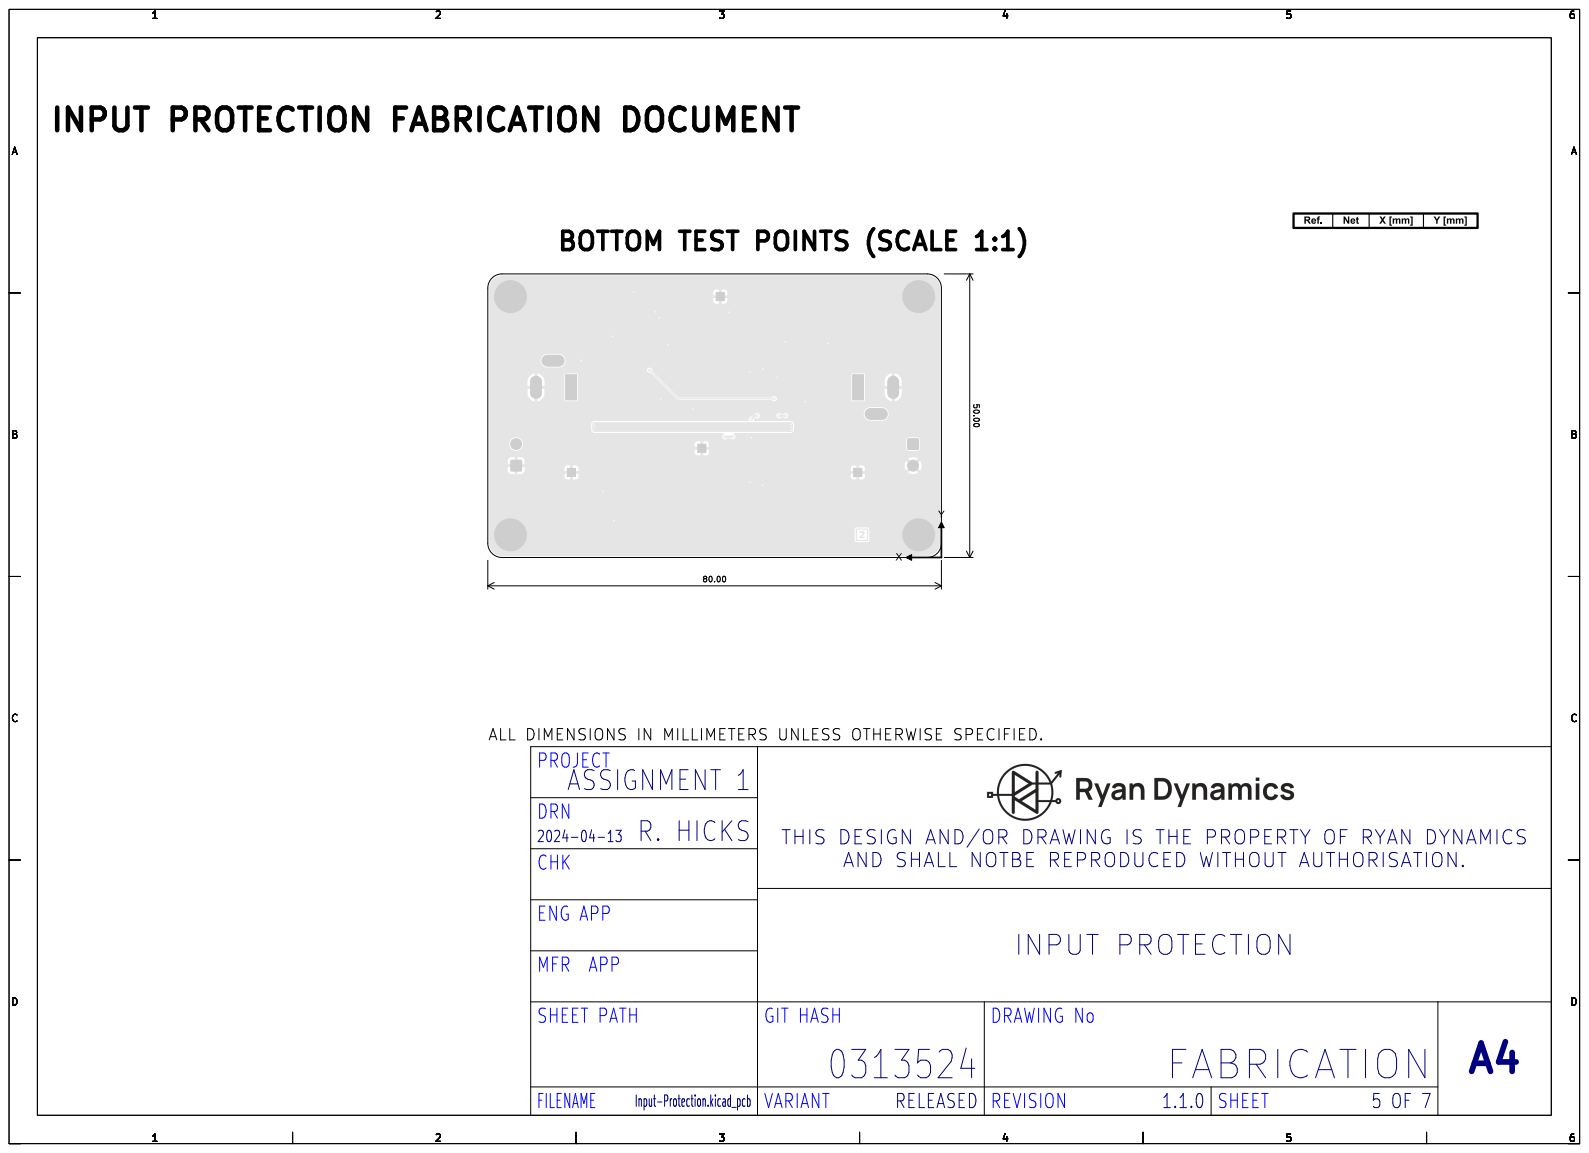
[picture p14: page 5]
DRAWING No; ASSIGNMENT 1; FABRICATION; PROJECT; INPUT; PROTECTION; ENG APP; 2024-04-13 CHK; GIT; HASH; SHEET; PATH; MFR; APP; DRN; R. HICKS; THIS DESIGN AND/OR; DRAWING IS THE PROPERTY OF RYAN DYNAMICSAND SHALL NOTBE REPRODUCED WITHOUT AUTHORISATION.; ALL; DIMENSIONS; MILLIMETERS; UNLESS OTHERWISE; SPECIFIED.

L1 (Sig, | PWR) (SCALE 1:1)
INPUT | PROTECTION | FABRICATION DOCUMENT

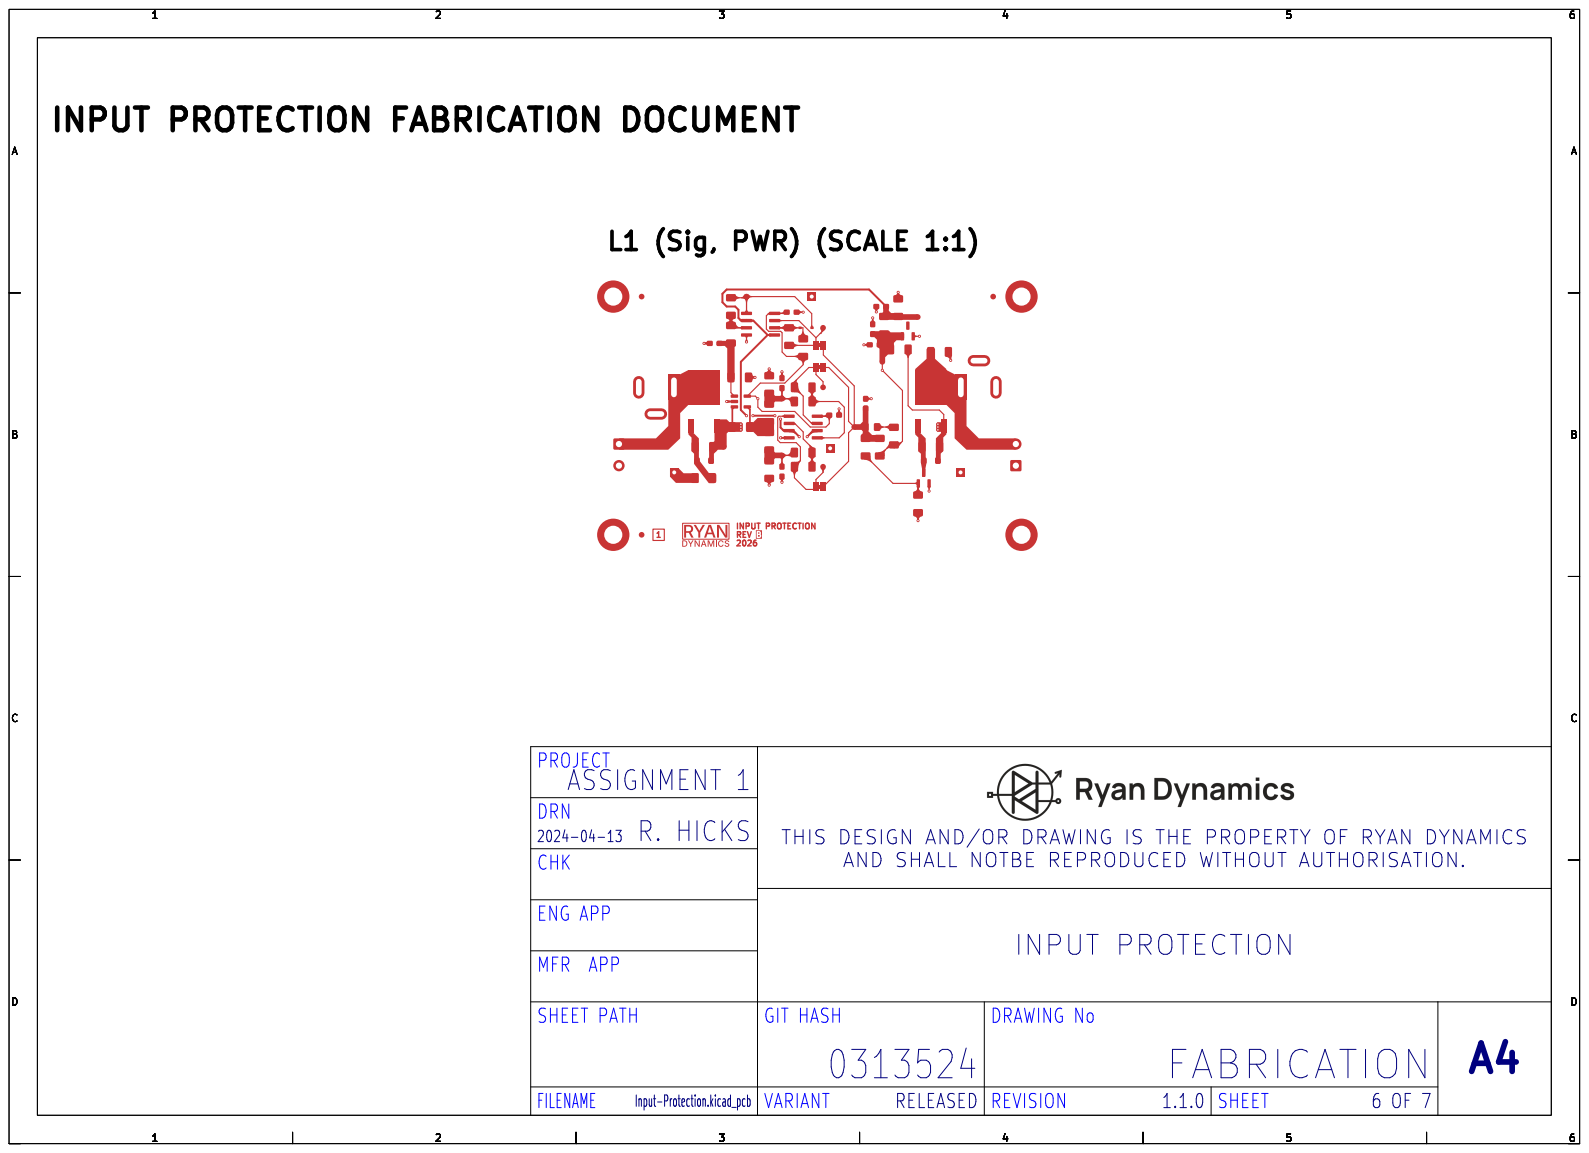
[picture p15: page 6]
DRAWING No; ASSIGNMENT 1; FABRICATION; PROJECT; INPUT; PROTECTION; ENG APP; 2024-04-13 CHK; GIT; HASH; SHEET; PATH; MFR; APP; DRN; R. HICKS; THIS DESIGN AND/OR; DRAWING IS THE PROPERTY OF RYAN DYNAMICSAND SHALL NOTBE REPRODUCED WITHOUT AUTHORISATION.; REV; INPUT PROTECTION

# L2 (Sig, GND) (SCALE 1:1)

INPUT | PROTECTION | FABRICATION DOCUMENT

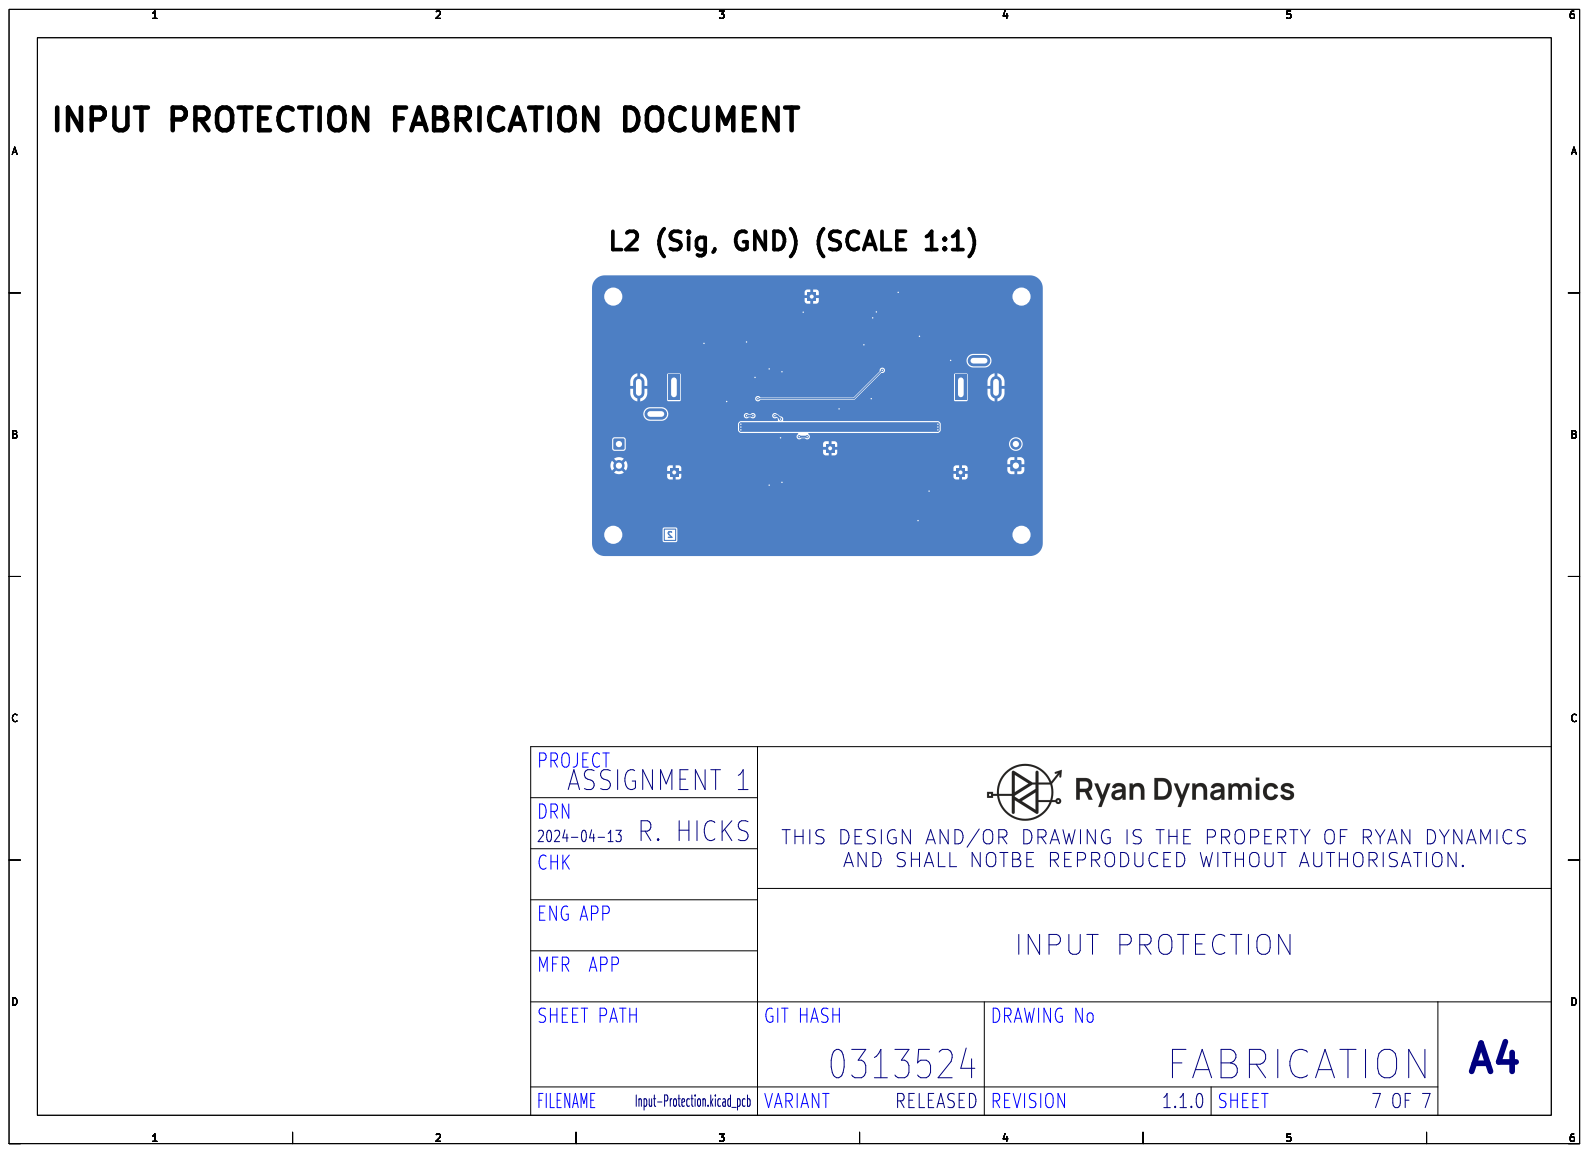
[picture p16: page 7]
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

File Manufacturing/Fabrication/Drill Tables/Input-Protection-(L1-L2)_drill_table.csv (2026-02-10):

Count | Hole Size | Plated | Hole Shape | Drill Layer Pair | Hole Type
34 | 0.25mm (9.84mils) | PTH | Round | L1 (Sig, PWR) - L2 (Sig, GND) | Via
4 | 0.70mm (27.56mils) | PTH | Round | L1 (Sig, PWR) - L2 (Sig, GND) | Pad
6 | 1.00mm (39.37mils) | PTH | Slot | L1 (Sig, PWR) - L2 (Sig, GND) | Pad
4 | 1.10mm (43.31mils) | PTH | Round | L1 (Sig, PWR) - L2 (Sig, GND) | Pad
4 | 3.20mm (125.98mils) | PTH | Round | L1 (Sig, PWR) - L2 (Sig, GND) | Pad
Total 52

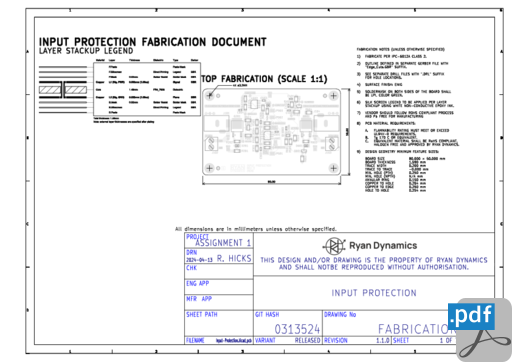
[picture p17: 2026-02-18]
HTML/images/cat_pdf_fabrication_Input-Protection-fabrication.png

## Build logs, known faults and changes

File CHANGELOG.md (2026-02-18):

# Changelog

## [Unreleased]

## [1.1.0] - 2026-02-18

### Fixed

-   Tidied up some routing issues

### Added

-   N/A

### Changed

-   Changed fiducials to be circular
-   Changed info block

### Removed

-   N/A

## [1.0.0] - 2026-02-11

### Fixed

-   N/A

### Added

-   Schematic capture and layout of a -50 to +50 V input +12 to +17 V output 1A protection PCBA

### Changed

-   N/A

### Removed

-   N/A

[Unreleased]: https://github.com/Reemuson/MENG4210-Assignment-1/compare/1.1.0...HEAD

[1.1.0]: https://github.com/Reemuson/MENG4210-Assignment-1/compare/1.0.0...1.1.0

[1.0.0]: https://github.com/Reemuson/MENG4210-Assignment-1/compare/a736dc43ef8961d2705dc433b7d367cf4c8fd0a9...1.0.0

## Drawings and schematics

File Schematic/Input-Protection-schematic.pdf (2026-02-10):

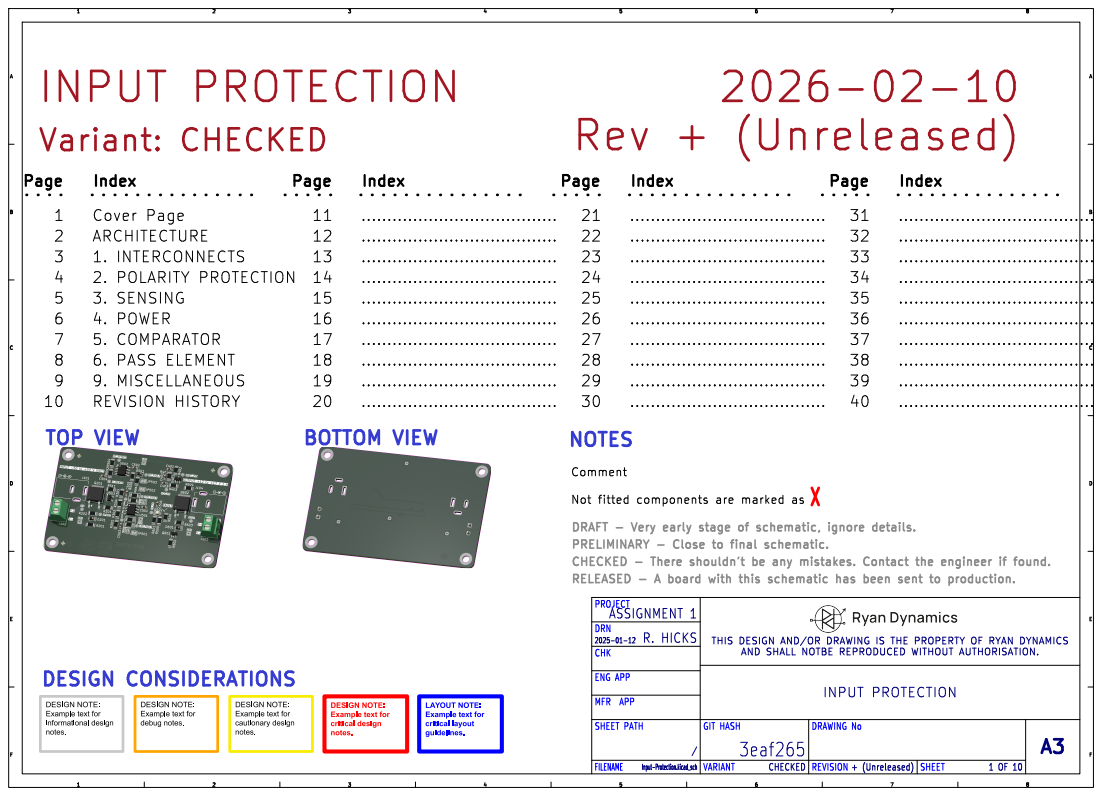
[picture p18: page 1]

CHECKED - There shouldn't be any mistakes. Contact the engineer if found.

THIS DESIGN AND/OR DRAWING IS THE PROPERTY OF RYAN DYNAMICS

AND SHALL NOTBE REPRODUCED WITHOUT AUTHORISATION.

File: Project Architecture.kicad_sch LAYOUT NOTE:
Example text for
critical layout
guidelines.

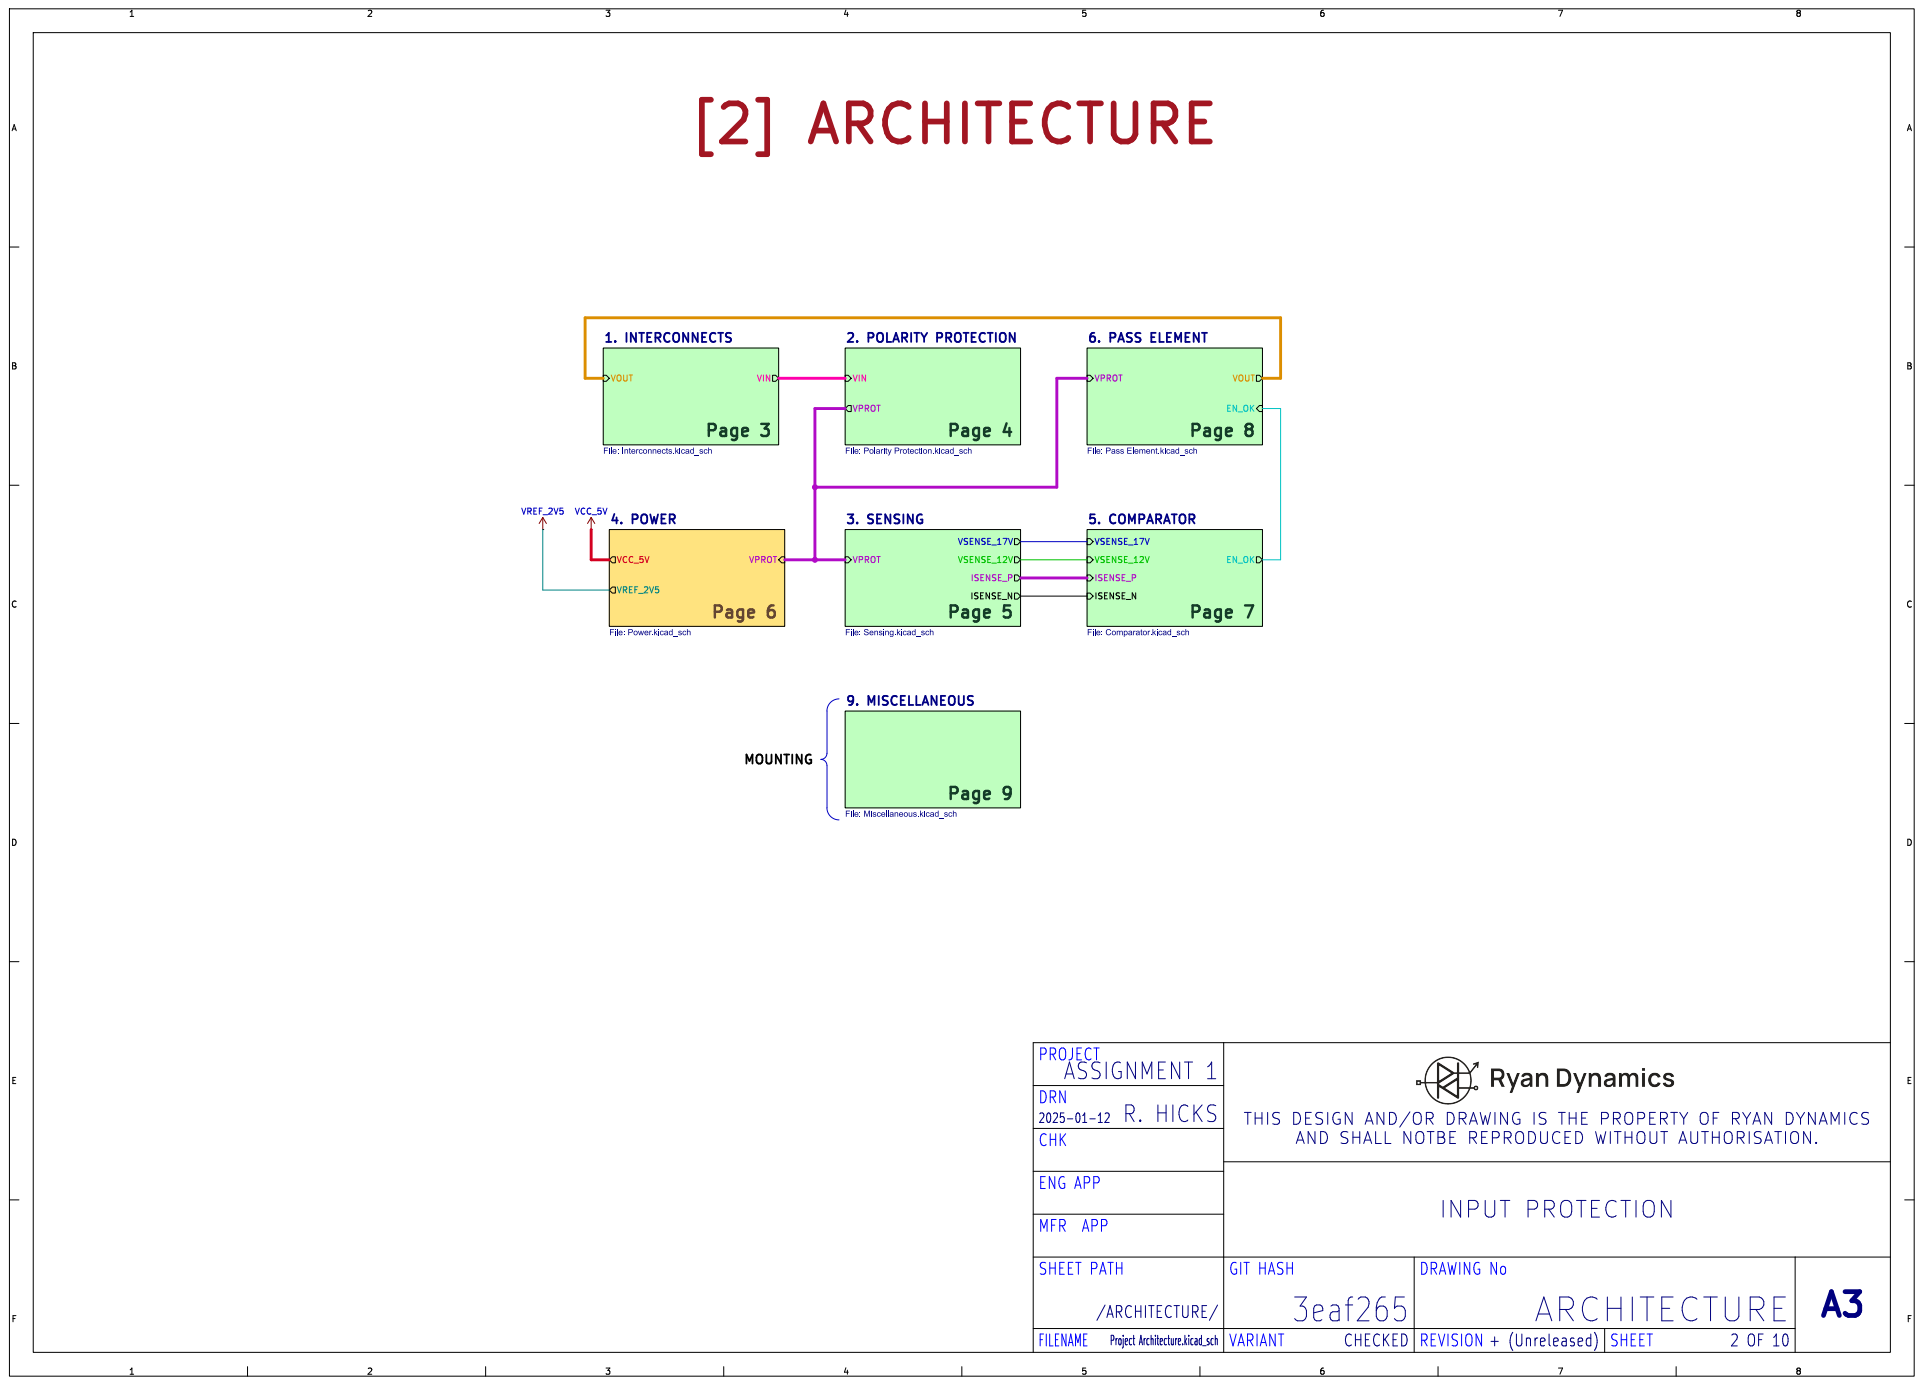
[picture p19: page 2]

THIS DESIGN AND/OR DRAWING IS THE PROPERTY OF RYAN DYNAMICS

AND SHALL NOTBE REPRODUCED WITHOUT AUTHORISATION.

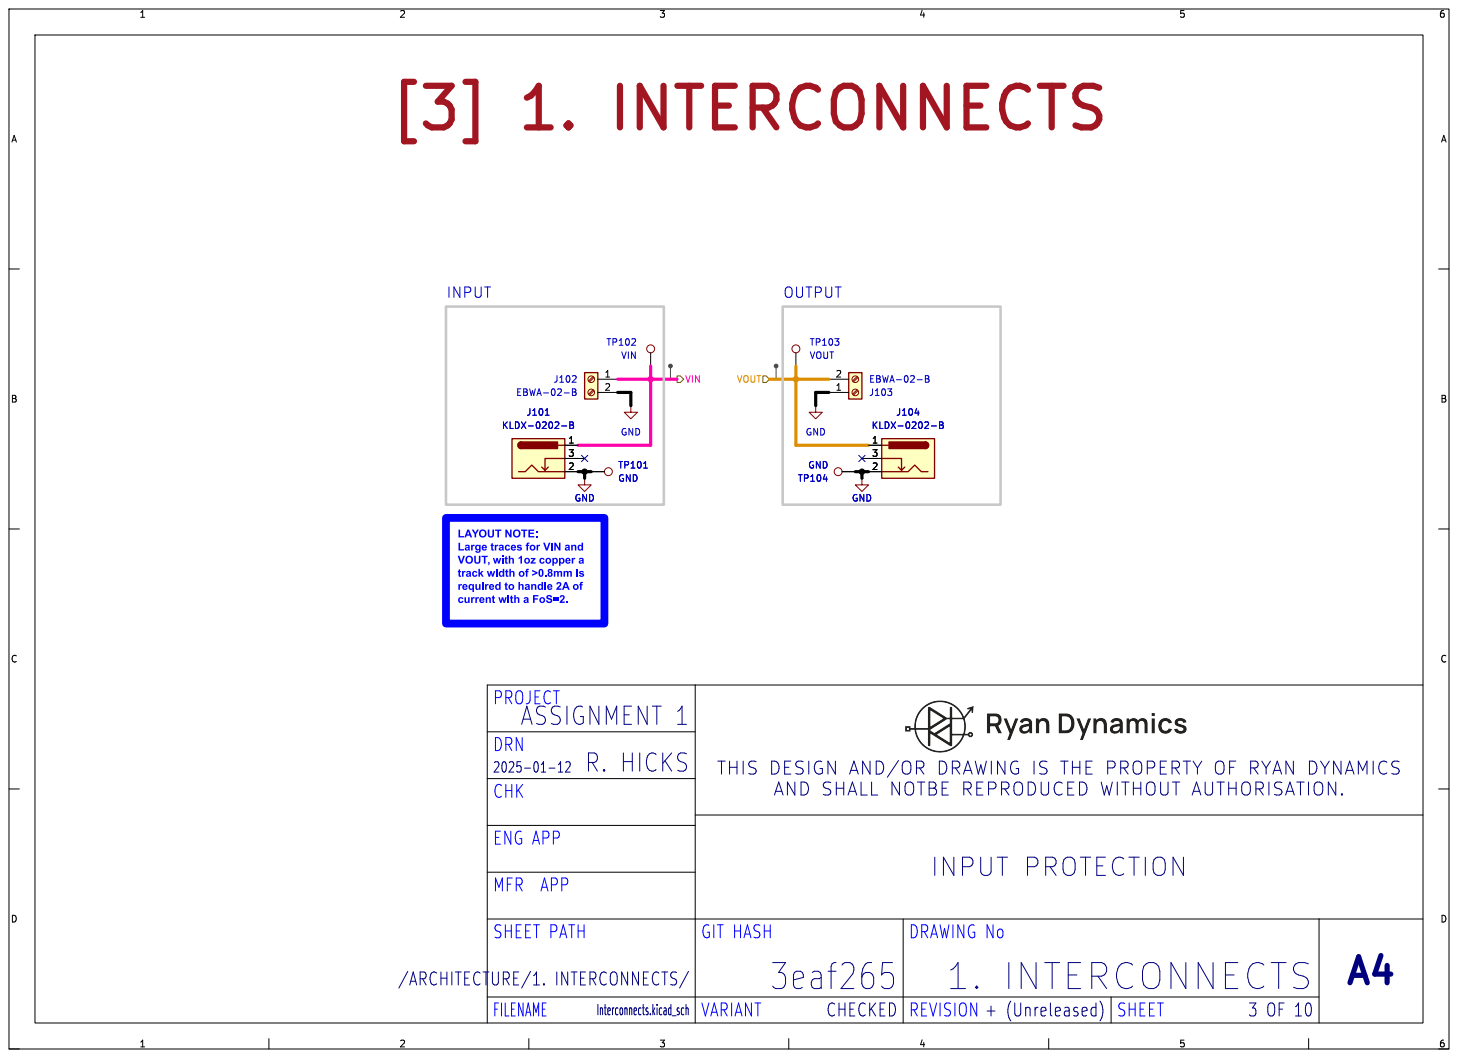
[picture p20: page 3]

LAYOUT NOTE: Large traces for VIN and VOUT, with 1oz copper a

track width of >0.8mm is
required to handle 2A of current with a FoS=2.

THIS DESIGN AND/OR DRAWING IS THE PROPERTY OF RYAN DYNAMICS

AND SHALL NOTBE REPRODUCED WITHOUT AUTHORISATION.

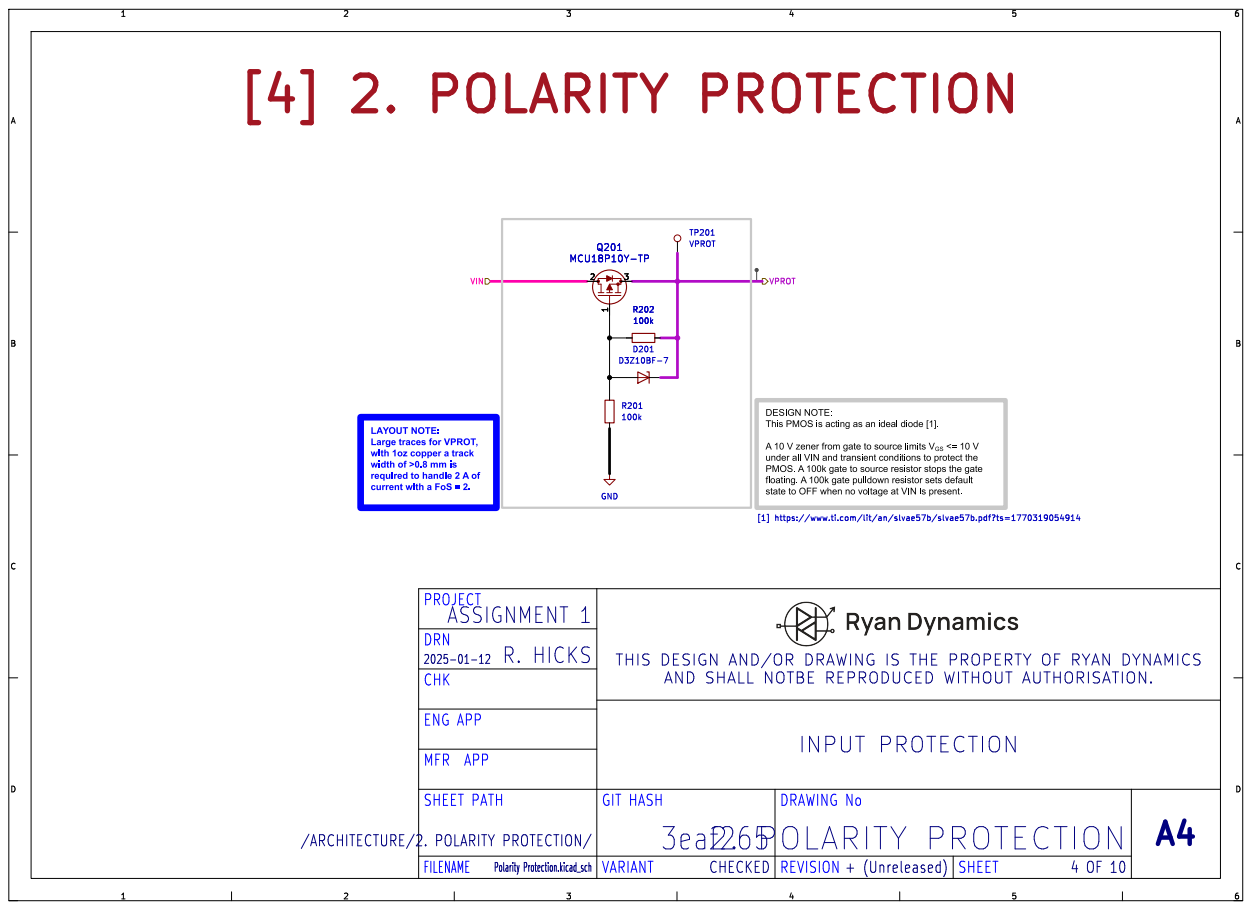
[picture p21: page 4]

[1] https://www.ti.com/lit/an/slvae57b/slvae57b.pdf?ts=1770319054914 R202

DESIGN NOTE: This PMOS is acting as an ideal diode [1]. A 10 V zener from gate to source limits V_{GS} <= 10 V

under all VIN and transient conditions to protect the PMOS. A 100k gate to source resistor stops the gate

floating. A 100k gate pulldown resistor sets default state to OFF when no voltage at VIN is present.

THIS DESIGN AND/OR DRAWING IS THE PROPERTY OF RYAN DYNAMICS

AND SHALL NOTBE REPRODUCED WITHOUT AUTHORISATION.

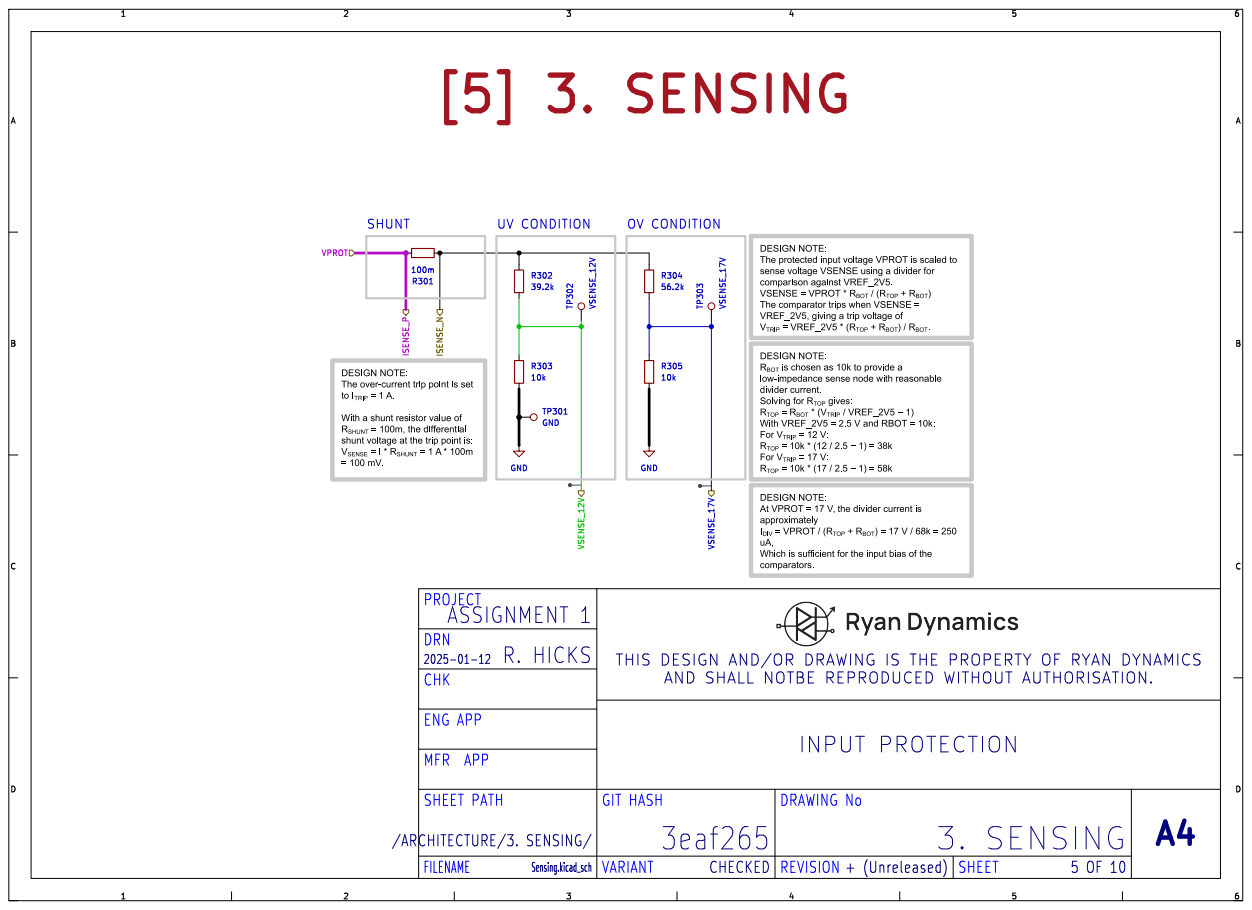
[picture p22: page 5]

DESIGN NOTE: The protected input voltage VPROT is scaled to

sense voltage VSENSE using a divider for comparison against VREF_2V5. VSENSE = VPROT * R_{BOT} / (R_{TOP} + R_{BOT}) The comparator trips when VSENSE = VREF_2V5, giving a trip voltage of V_{TRIP} = VREF_2V5 * (R_{TOP} + R_{BOT}) / R_{BOT}. DESIGN NOTE: R_{BOT} is chosen as 10k to provide a

low-impedance sense node with reasonable

to I_{TRIP} = 1 A. With a shunt resistor value of R_{SHUNT} = 100m, the differential shunt voltage at the trip point is: V_{SENSE} = I * R_{SHUNT} = 1 A * 100m

divider current. Solving for R_{TOP} gives:

R_{TOP} = R_{BOT} * (V_{TRIP} / VREF_2V5 þÿ" 1) With VREF_2V5 = 2.5 V and RBOT = 10k: For V_{TRIP} = 12 V: R_{TOP} = 10k * (12 / 2.5 þÿ" 1) = 38k For V_{TRIP} = 17 V: R_{TOP} = 10k * (17 / 2.5 þÿ" 1) = 58k DESIGN NOTE: At VPROT = 17 V, the divider current is approximately

I_{DIV} = VPROT / (R_{TOP} + R_{BOT}) = 17 V / 68k = 250
uA, Which is sufficient for the input bias of the

THIS DESIGN AND/OR DRAWING IS THE PROPERTY OF RYAN DYNAMICS

AND SHALL NOTBE REPRODUCED WITHOUT AUTHORISATION.

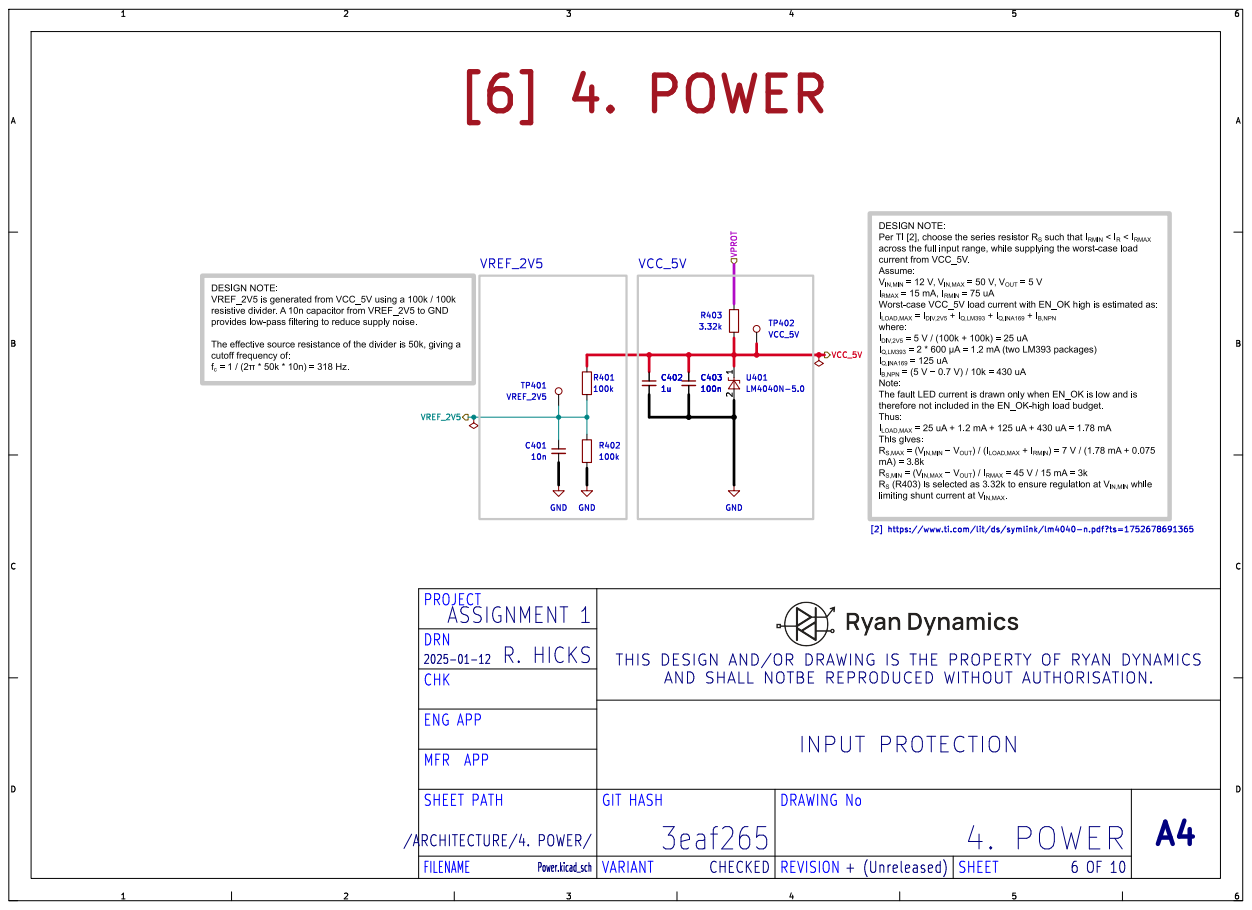
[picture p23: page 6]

DESIGN NOTE: Per TI [2], choose the series resistor R_{S} such that I_{RMIN} < I_{R} < I_{RMAX} across the full input range, while supplying the worst-case load

current from VCC_5V. Assume: V_{IN,MIN} = 12 V, V_{IN,MAX} = 50 V, V_{OUT} = 5 V

limiting shunt current at V_{IN,MAX}. DESIGN NOTE: VREF_2V5 is generated from VCC_5V using a 100k / 100k

I_{RMAX} = 15 mA, I_{RMIN} = 75 uA Worst-case VCC_5V load current with EN_OK high is estimated as:

resistive divider. A 10n capacitor from VREF_2V5 to GND
provides low-pass filtering to reduce supply noise. The effective source resistance of the divider is 50k, giving a

I_{LOAD,MAX} = I_{DIV,2V5} + I_{Q,LM393} + I_{Q,INA169} + I_{B,NPN} where:

I_{DIV,2V5} = 5 V / (100k + 100k) = 25 uA
I_{Q,LM393} = 2 * 600 þÿµA= 1.2 mA (two LM393 packages)
I_{Q,INA169} = 125 uA
I_{B,NPN} = (5 V þÿ" 0.7 V) / 10k = 430 uA Note: The fault LED current is drawn only when EN_OK is low and is

therefore not included in the EN_OK-high load budget. Thus:

I_{LOAD,MAX} = 25 uA + 1.2 mA + 125 uA + 430 uA = 1.78 mA
This gives:
R_{S,MAX} = (V_{IN,MIN} þÿ" V_{OUT}) / (I_{LOAD,MAX} + I_{RMIN}) = 7 V / (1.78 mA + 0.075 mA) = 3.8k R_{S,MIN} = (V_{IN,MAX} þÿ" V_{OUT}) / I_{RMAX} = 45 V / 15 mA = 3k R_{S} (R403) is selected as 3.32k to ensure regulation at V_{IN,MIN} while

[2] https://www.ti.com/lit/ds/symlink/lm4040-n.pdf?ts=1752678691365

THIS DESIGN AND/OR DRAWING IS THE PROPERTY OF RYAN DYNAMICS

AND SHALL NOTBE REPRODUCED WITHOUT AUTHORISATION.

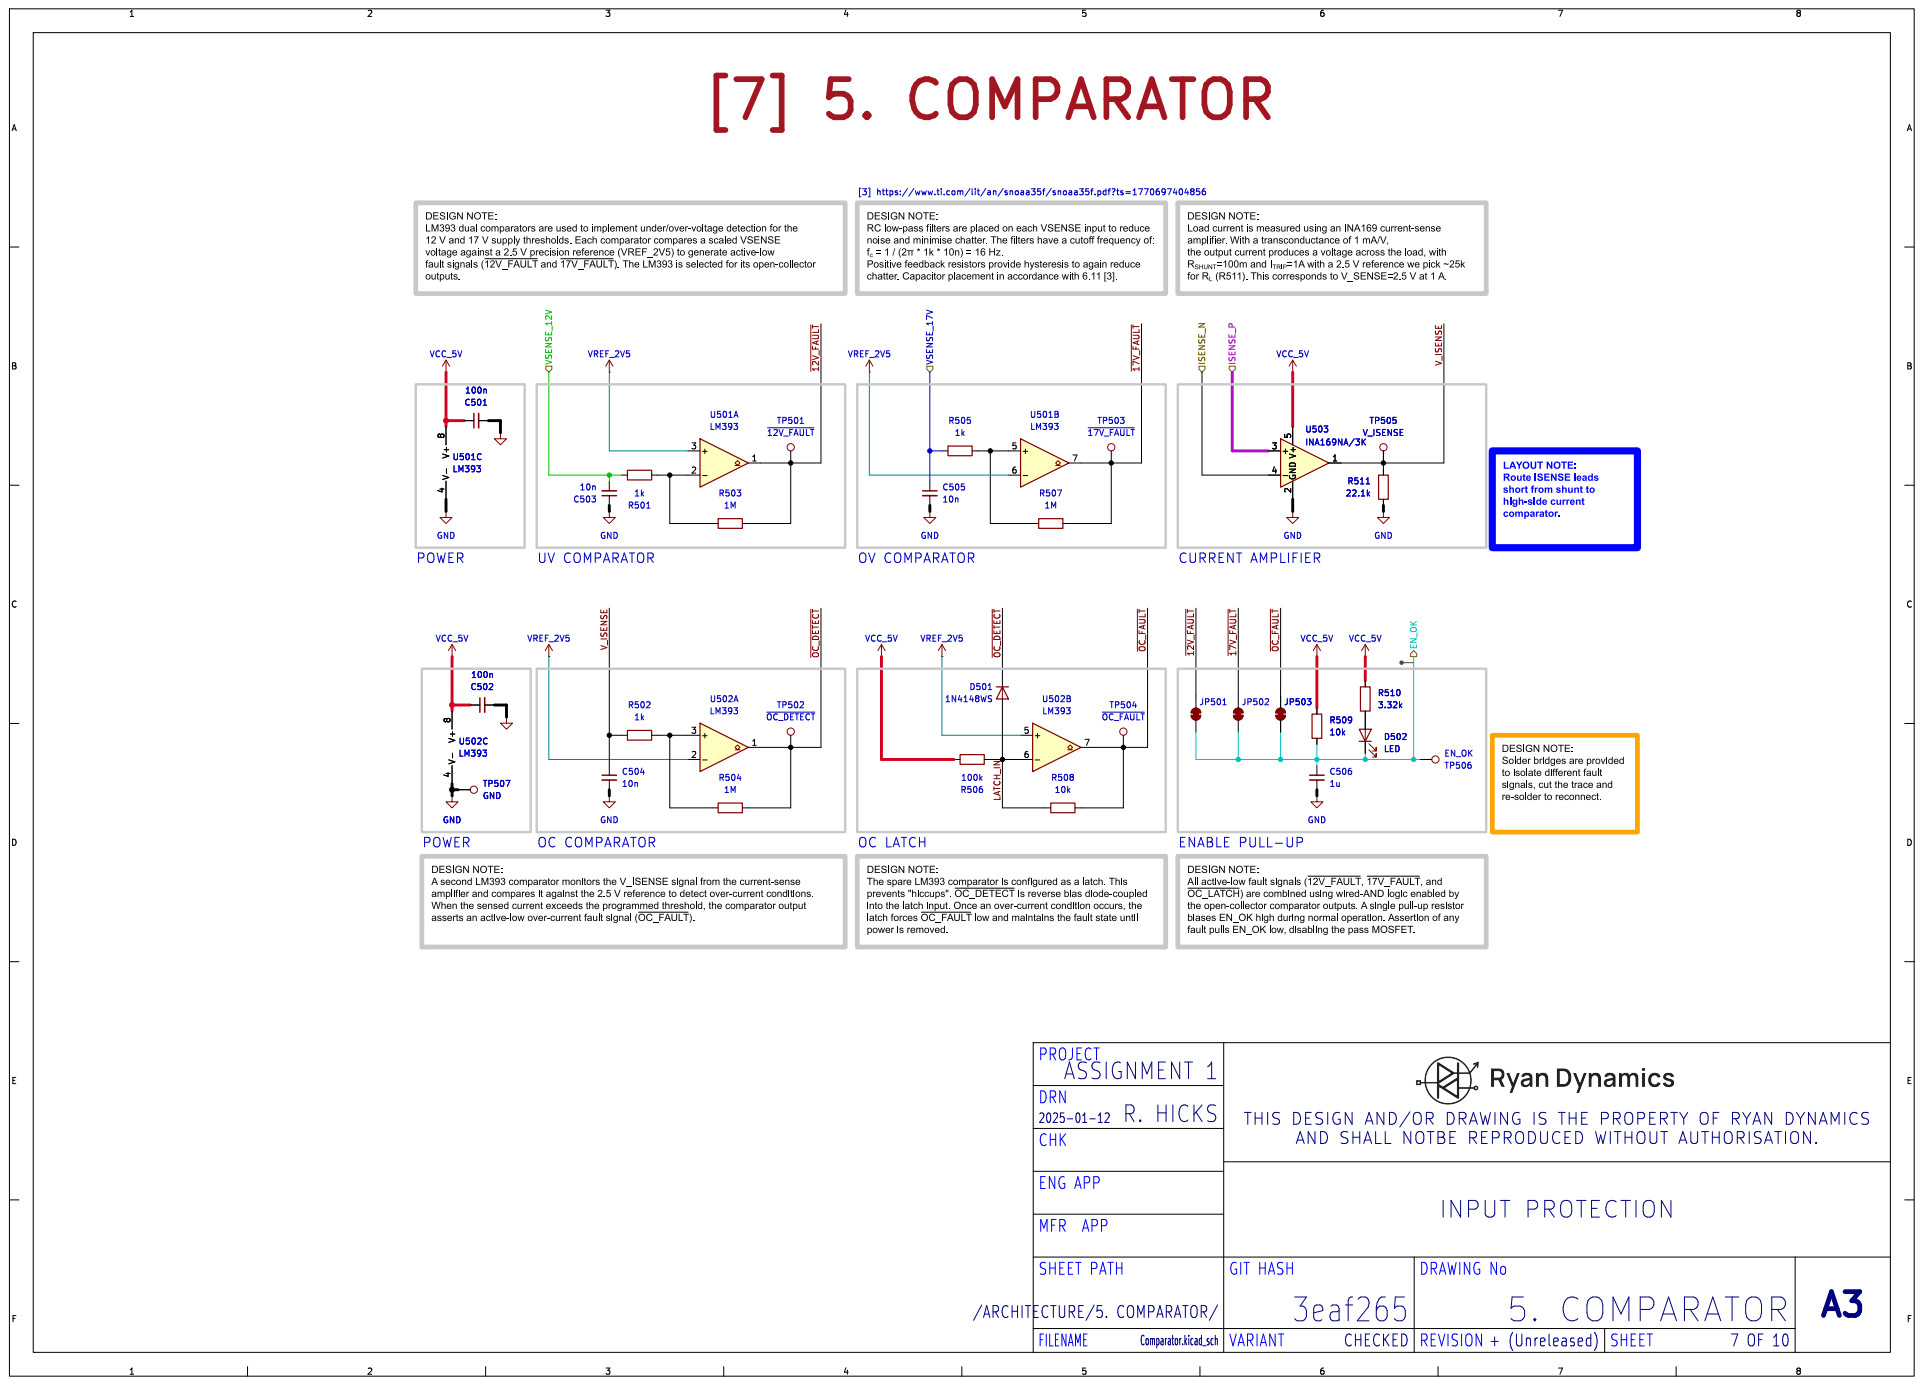
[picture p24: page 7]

fault pulls EN_OK low, disabling the pass MOSFET. [7] 5. COMPARATOR

[3] https://www.ti.com/lit/an/snoaa35f/snoaa35f.pdf?ts=1770697404856

chatter. Capacitor placement in accordance with 6.11 [3]. DESIGN NOTE: LM393 dual comparators are used to implement under/over-voltage detection for the

DESIGN NOTE: RC low-pass filters are placed on each VSENSE input to reduce
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

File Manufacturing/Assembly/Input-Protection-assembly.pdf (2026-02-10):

INPUT | PROTECTION | Assembly | DOCUMENT
Top View | Bottom | View

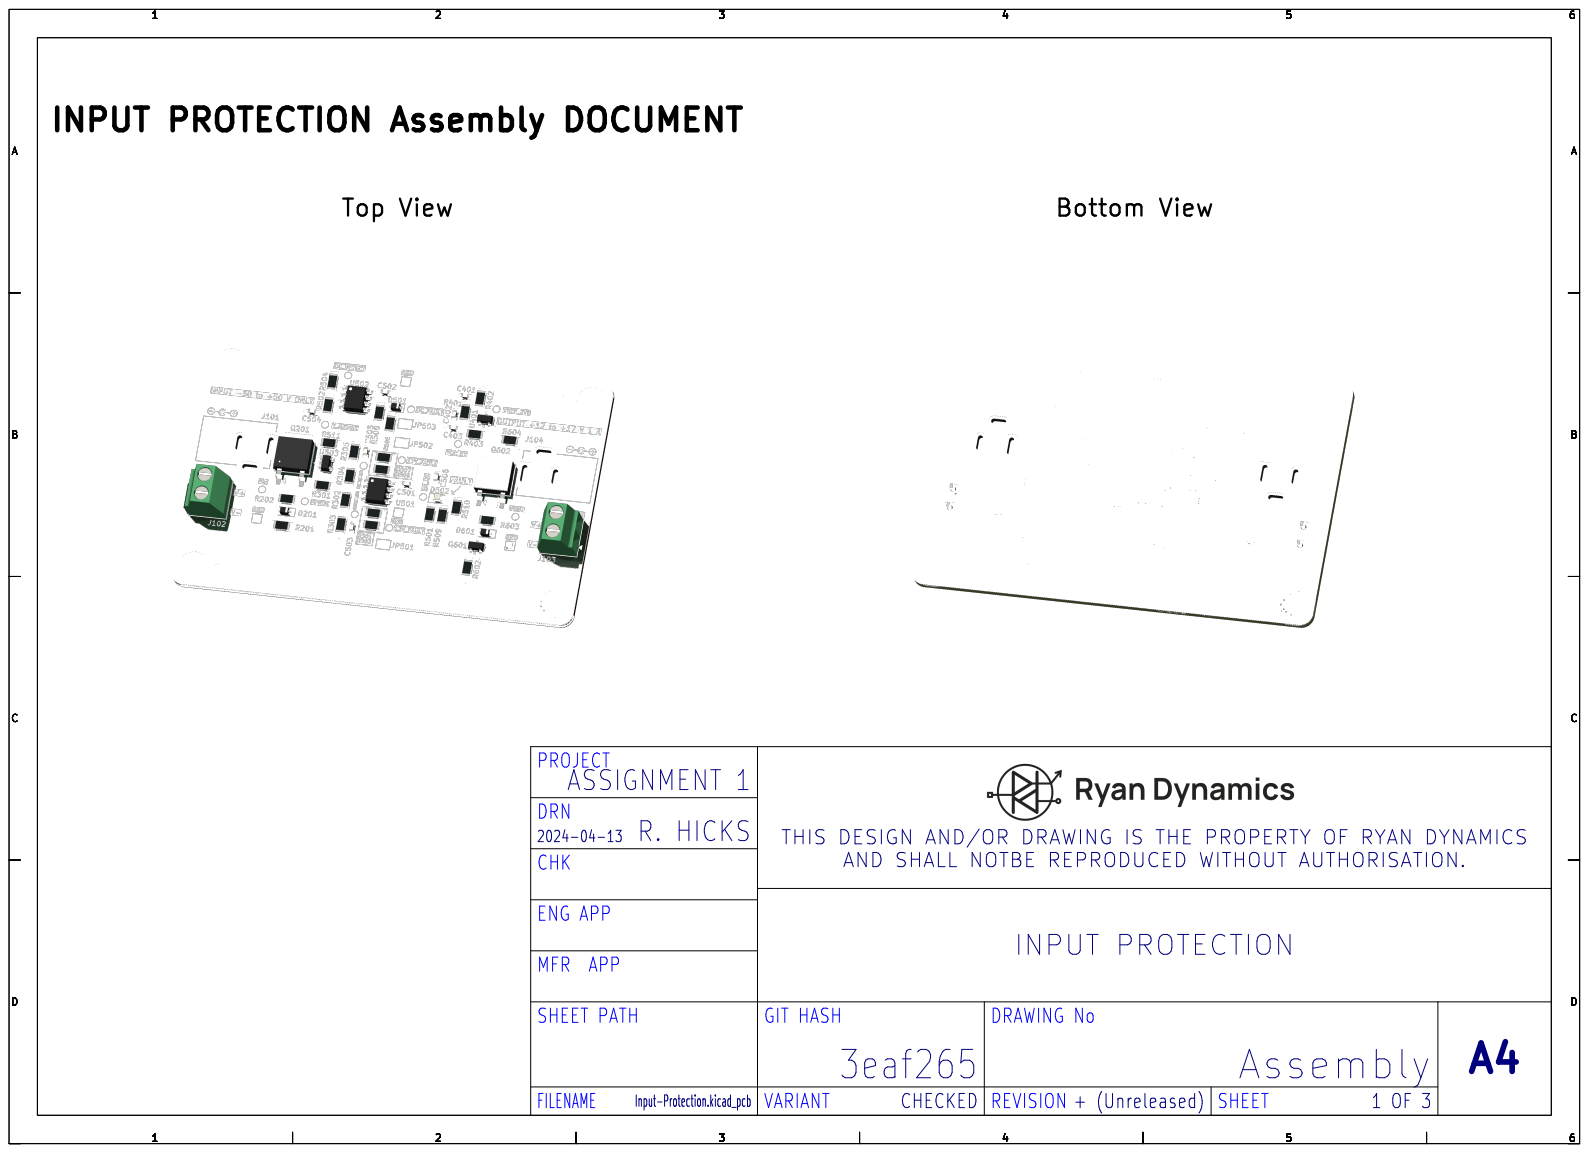
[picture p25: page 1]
DRAWING No; ASSIGNMENT 1; SHEET; Assembly; PROJECT; Input-Protection.kicad_pcb; INPUT; PROTECTION; FILENAME; ENG APP; CHECKED; + (Unreleased); 2024-04-13 CHK; GIT; HASH; VARIANT; PATH; MFR; APP; DRN; REVISION; R. HICKS; 3eaf265; THIS DESIGN AND/OR; DRAWING IS THE PROPERTY OF RYAN DYNAMICSAND SHALL NOTBE REPRODUCED WITHOUT AUTHORISATION.

# Top Assembly (Scale 1:1)

# INPUT PROTECTION Assembly DOCUMENT

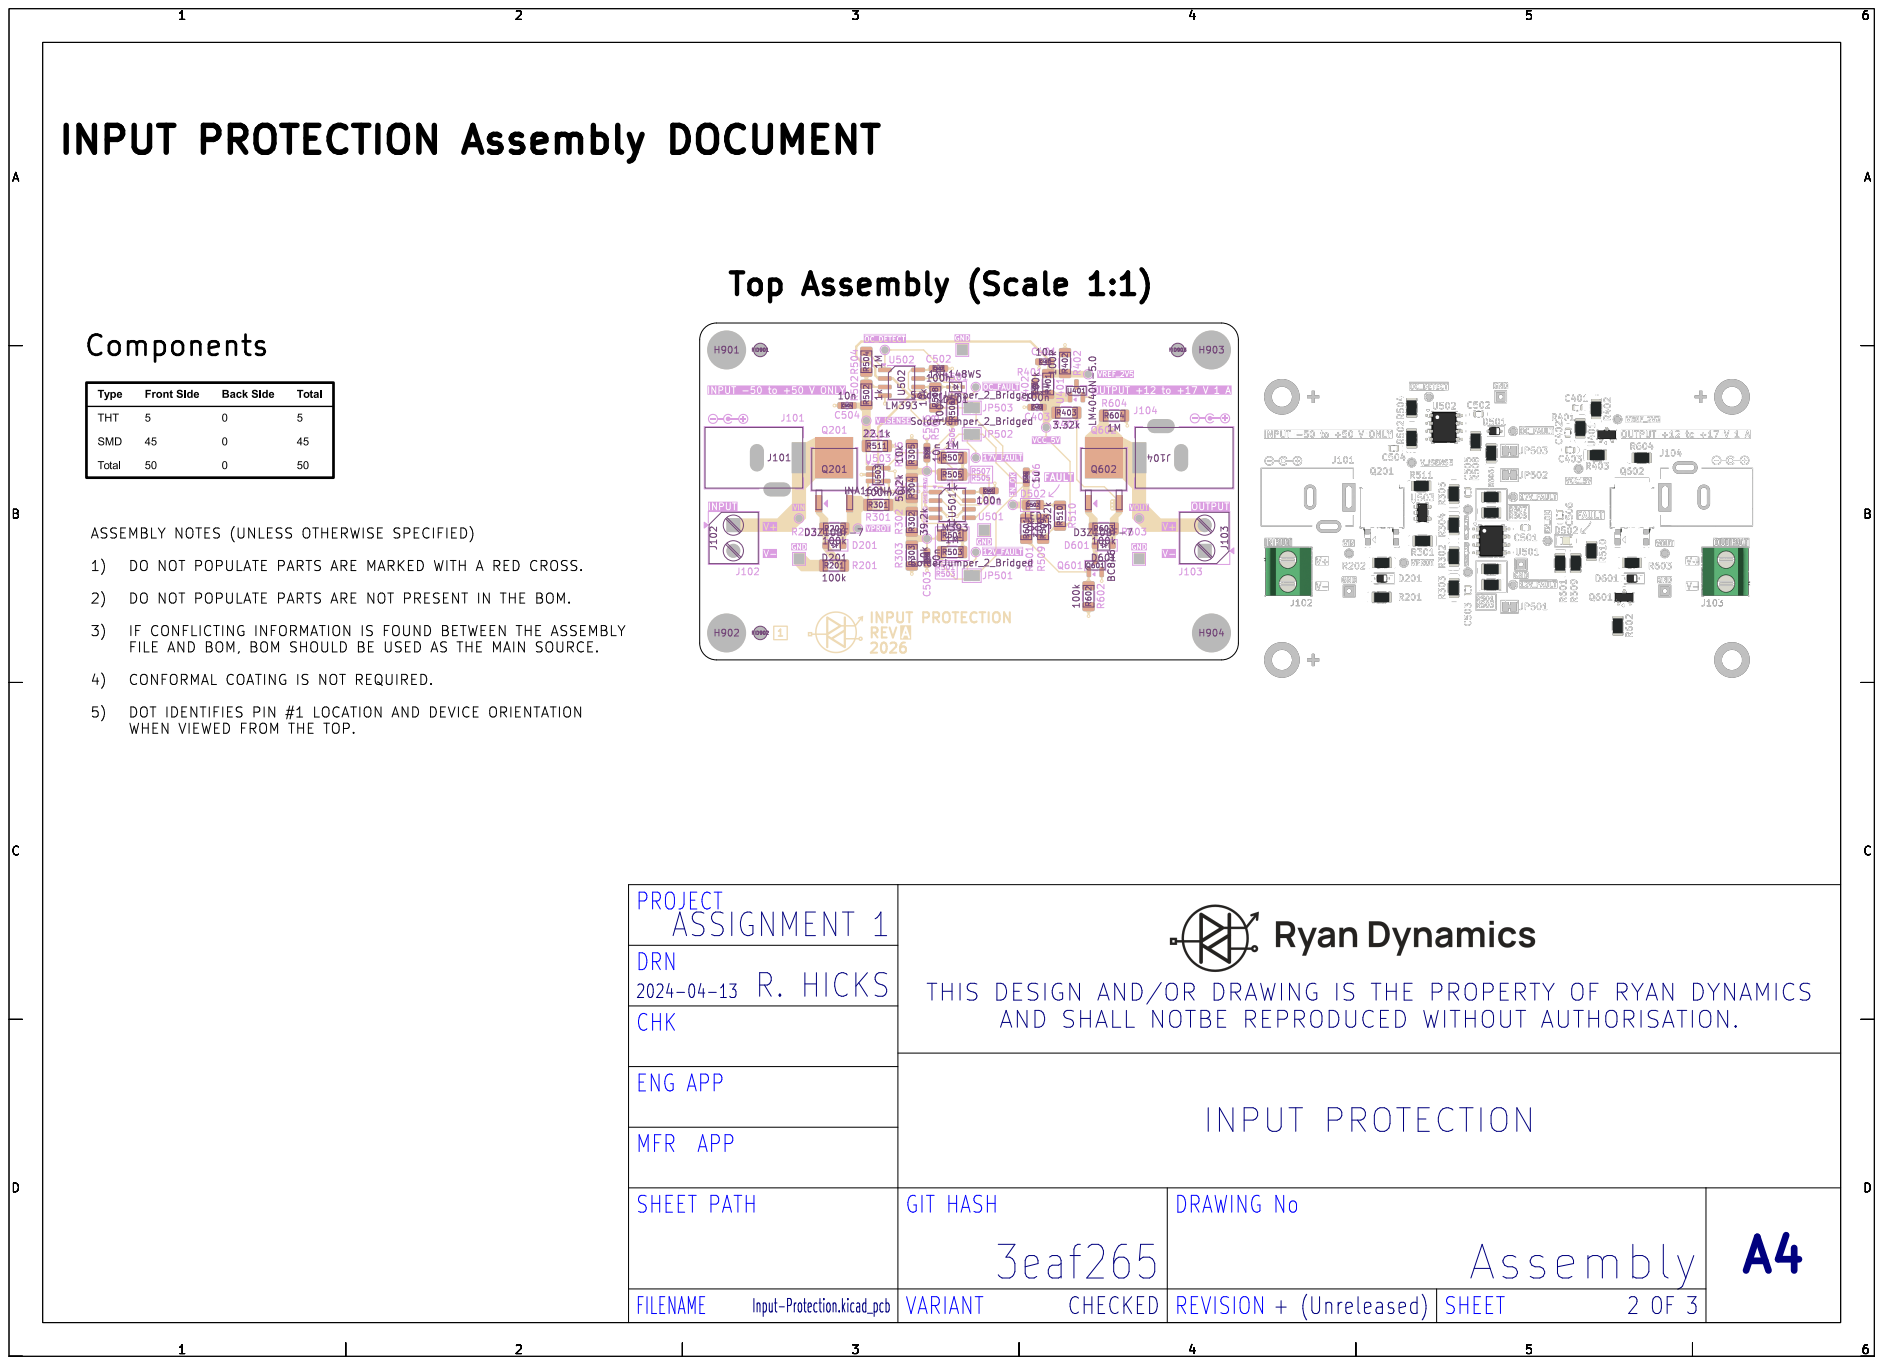
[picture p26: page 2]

ASSEMBLY NOTES (UNLESS OTHERWISE SPECIFIED)

1) DO NOT POPULATE PARTS ARE MARKED WITH A RED CROSS.

2) DO NOT POPULATE PARTS ARE NOT PRESENT IN THE BOM.

3) IF CONFLICTING INFORMATION IS FOUND BETWEEN THE ASSEMBLY
FILE AND BOM, BOM SHOULD BE USED AS THE MAIN SOURCE.

4) CONFORMAL COATING IS NOT REQUIRED.

5) DOT IDENTIFIES PIN #1 LOCATION AND DEVICE ORIENTATION
WHEN VIEWED FROM THE TOP.

PROJECT
ASSIGNMENT 1
DRN
THIS DESIGN AND/OR DRAWING IS THE PROPERTY OF RYAN DYNAMICSAND SHALL NOTBE REPRODUCED WITHOUT AUTHORISATION.
CHK

Bottom | Assembly (Scale 1:1)
INPUT | PROTECTION | Assembly | DOCUMENT

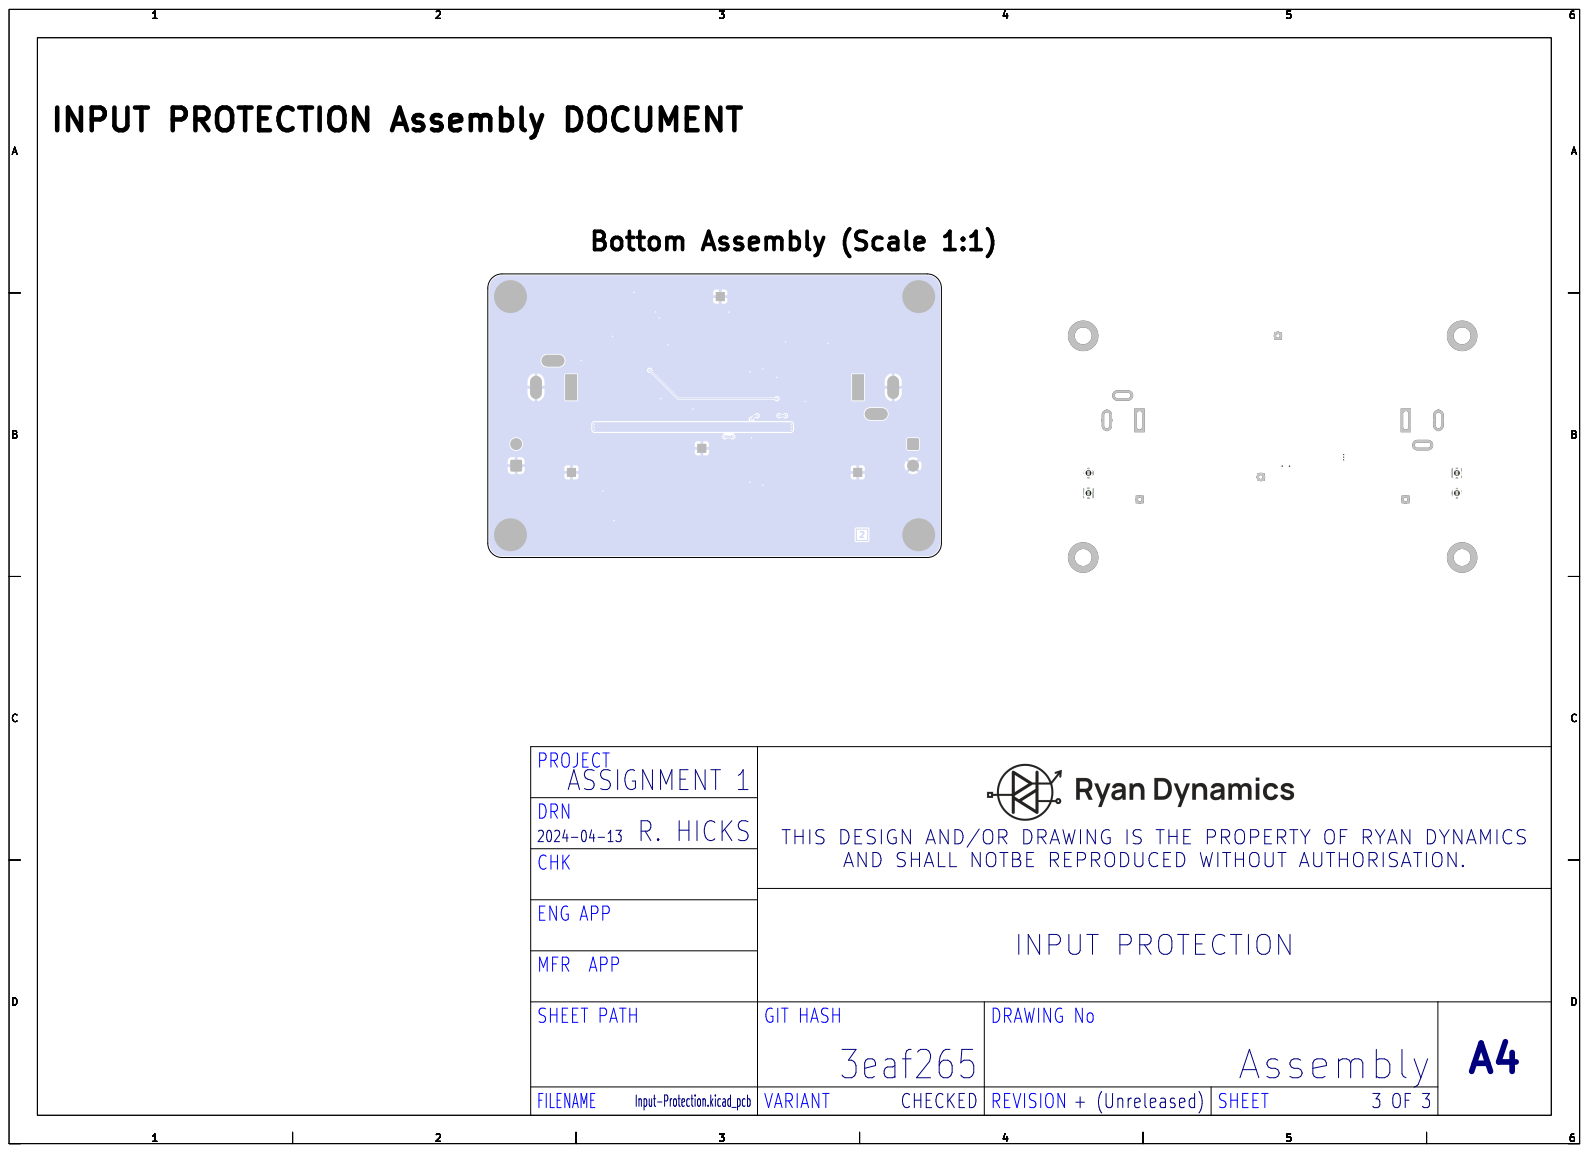
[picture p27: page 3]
DRAWING No; ASSIGNMENT 1; Assembly; PROJECT; INPUT; PROTECTION; ENG APP; 2024-04-13 CHK; GIT; HASH; SHEET; PATH; MFR; APP; DRN; R. HICKS; 3eaf265; THIS DESIGN AND/OR; DRAWING IS THE PROPERTY OF RYAN DYNAMICSAND SHALL NOTBE REPRODUCED WITHOUT AUTHORISATION.

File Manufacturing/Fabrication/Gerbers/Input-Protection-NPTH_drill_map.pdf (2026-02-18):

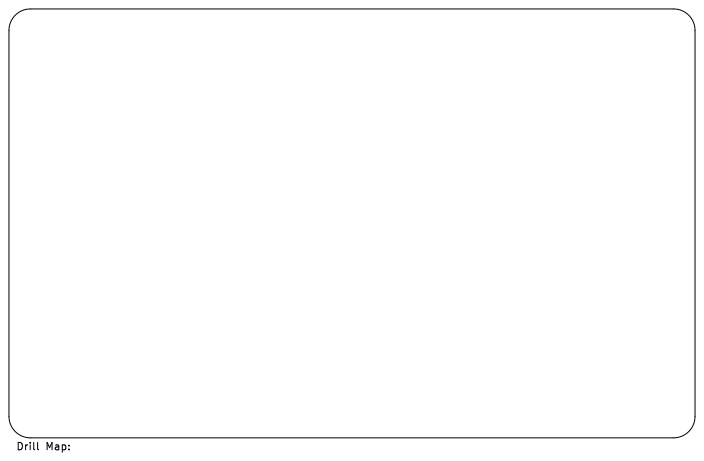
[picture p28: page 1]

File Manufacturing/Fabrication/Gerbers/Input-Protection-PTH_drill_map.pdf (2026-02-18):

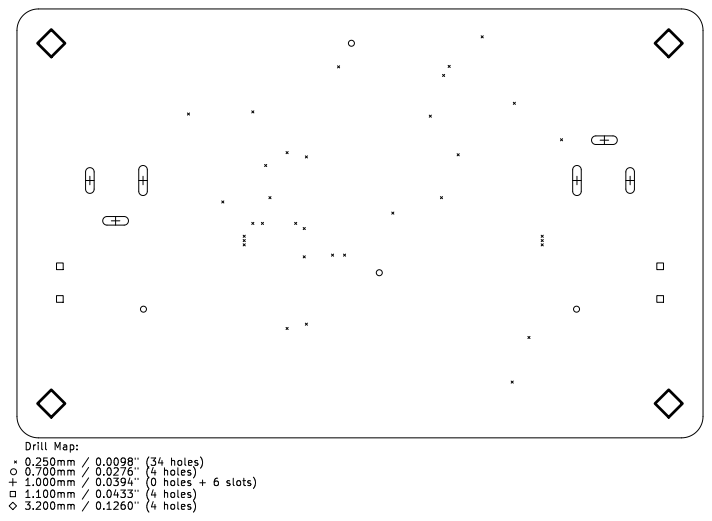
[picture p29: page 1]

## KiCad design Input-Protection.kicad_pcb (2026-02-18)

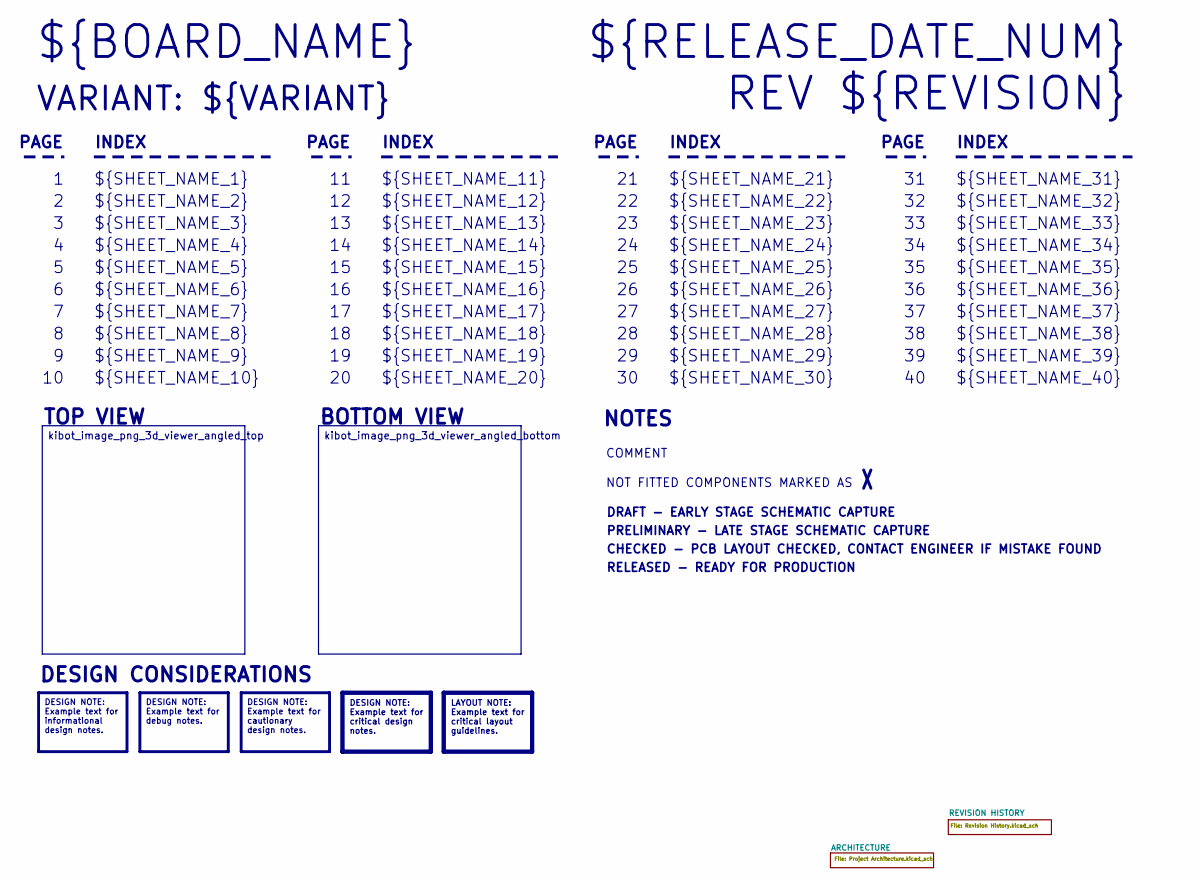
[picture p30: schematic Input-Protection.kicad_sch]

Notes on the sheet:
VARIANT: ${VARIANT}
${SHEET_NAME_24}
INDEX
PAGE
${SHEET_NAME_22}
DRAFT - EARLY STAGE SCHEMATIC CAPTURE
${SHEET_NAME_12}
${SHEET_NAME_8}
${SHEET_NAME_2}
${SHEET_NAME_5}
${SHEET_NAME_20}
${SHEET_NAME_23}
${RELEASE_DATE_NUM}
${SHEET_NAME_35}
${SHEET_NAME_11}
CHECKED - PCB LAYOUT CHECKED, CONTACT ENGINEER IF MISTAKE FOUND
${SHEET_NAME_6}
${SHEET_NAME_37}
NOT FITTED COMPONENTS MARKED AS
${SHEET_NAME_26}
${SHEET_NAME_36}
REV ${REVISION}
${SHEET_NAME_15}
BOTTOM VIEW
${SHEET_NAME_14}
${SHEET_NAME_21}
${SHEET_NAME_17}
${SHEET_NAME_18}
${SHEET_NAME_7}
${SHEET_NAME_31}
${BOARD_NAME}
NOTES
${SHEET_NAME_40}
${SHEET_NAME_39}
${SHEET_NAME_32}
${SHEET_NAME_1}
${SHEET_NAME_9}
${SHEET_NAME_38}
${SHEET_NAME_29}
RELEASED - READY FOR PRODUCTION

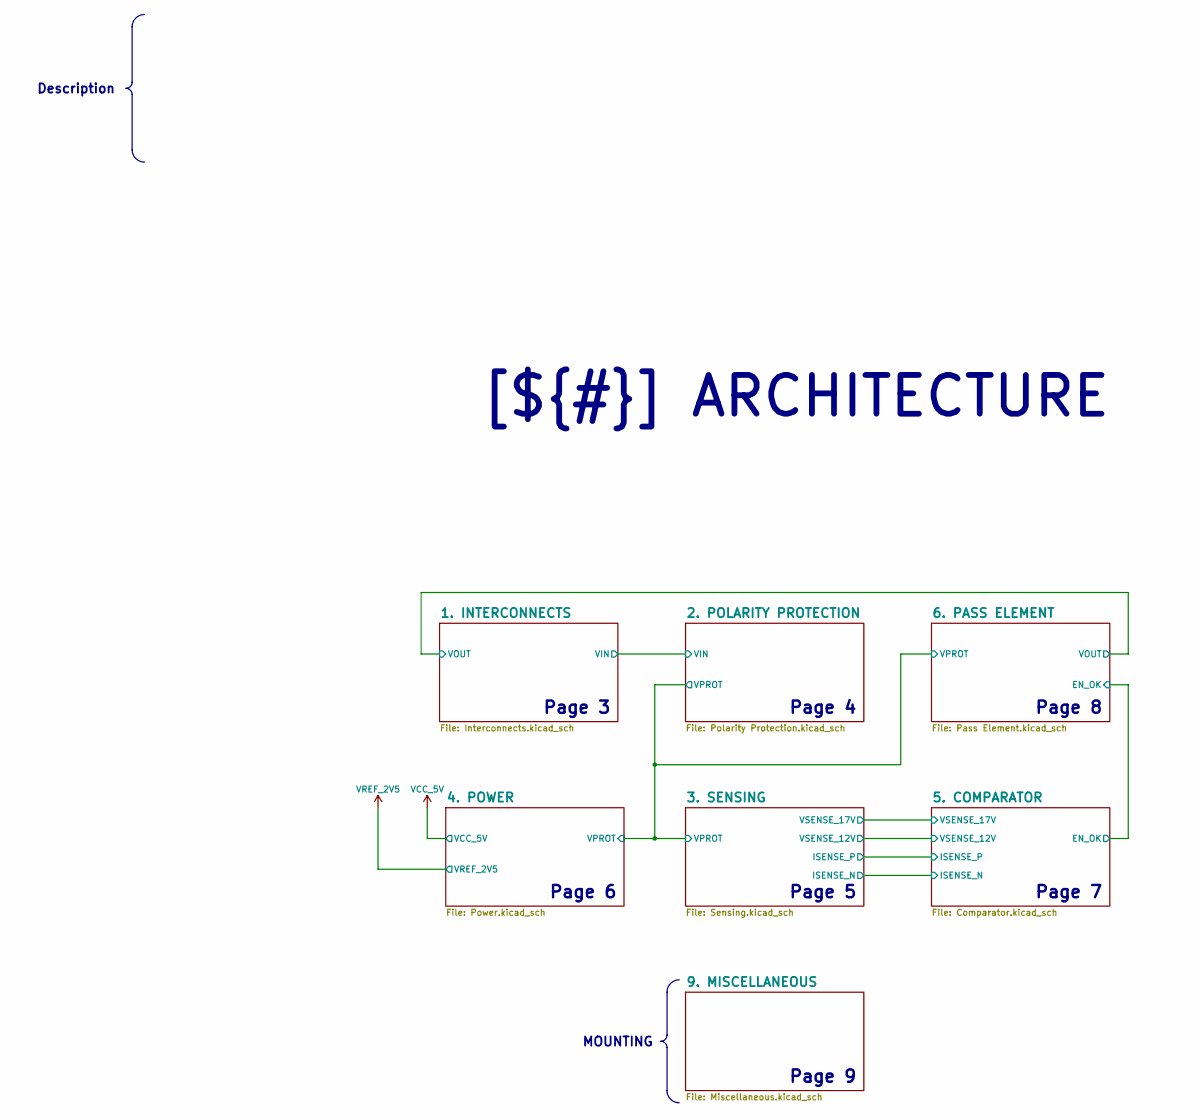
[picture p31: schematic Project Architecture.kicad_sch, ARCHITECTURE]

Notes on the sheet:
Page 7
Page 9
Page 3
Page 5
Page 8
Page 6
Page 4
Description
MOUNTING
[${#}] ${TITLE}

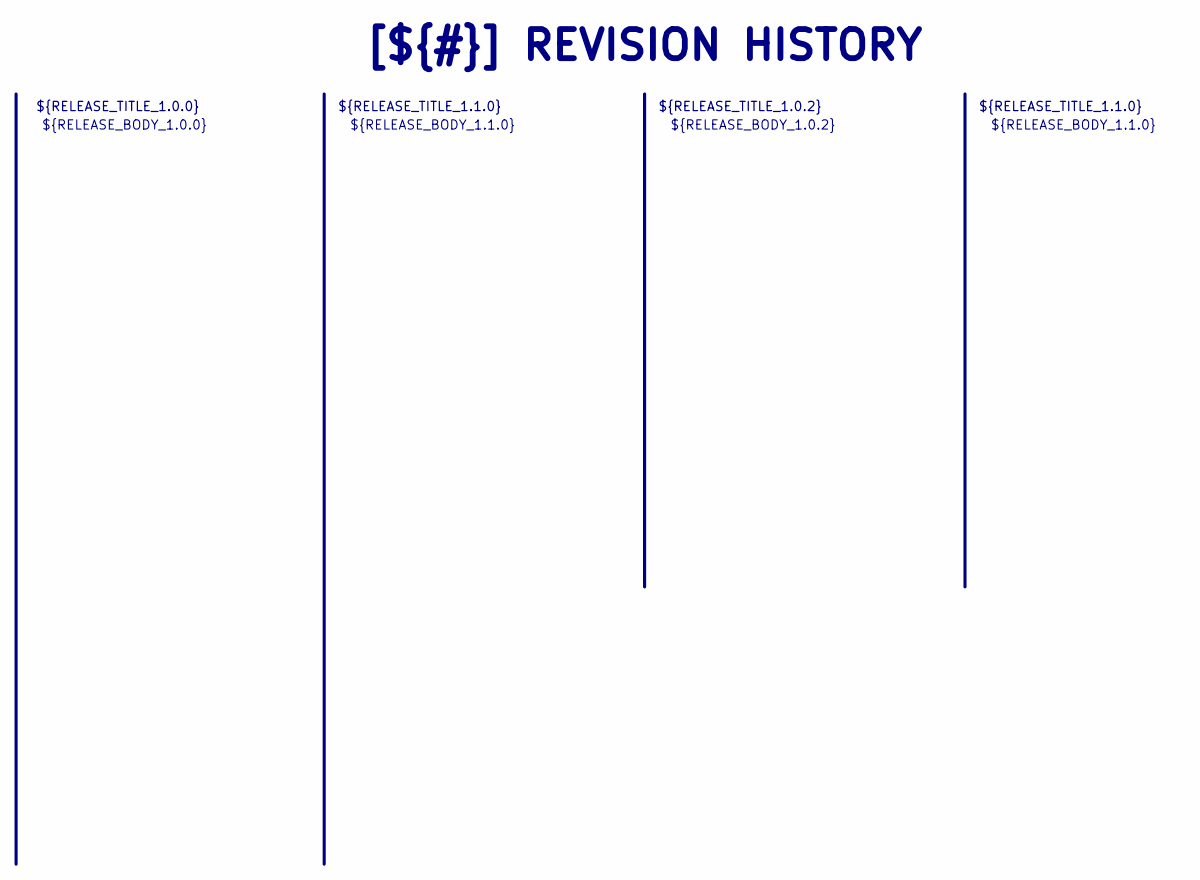
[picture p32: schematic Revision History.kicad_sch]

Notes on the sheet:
${RELEASE_BODY_1.1.0}
[${#}] ${TITLE}
${RELEASE_BODY_1.0.0}
${RELEASE_TITLE_1.0.2}
${RELEASE_BODY_1.0.2}
${RELEASE_TITLE_1.0.0}
${RELEASE_TITLE_1.1.0}

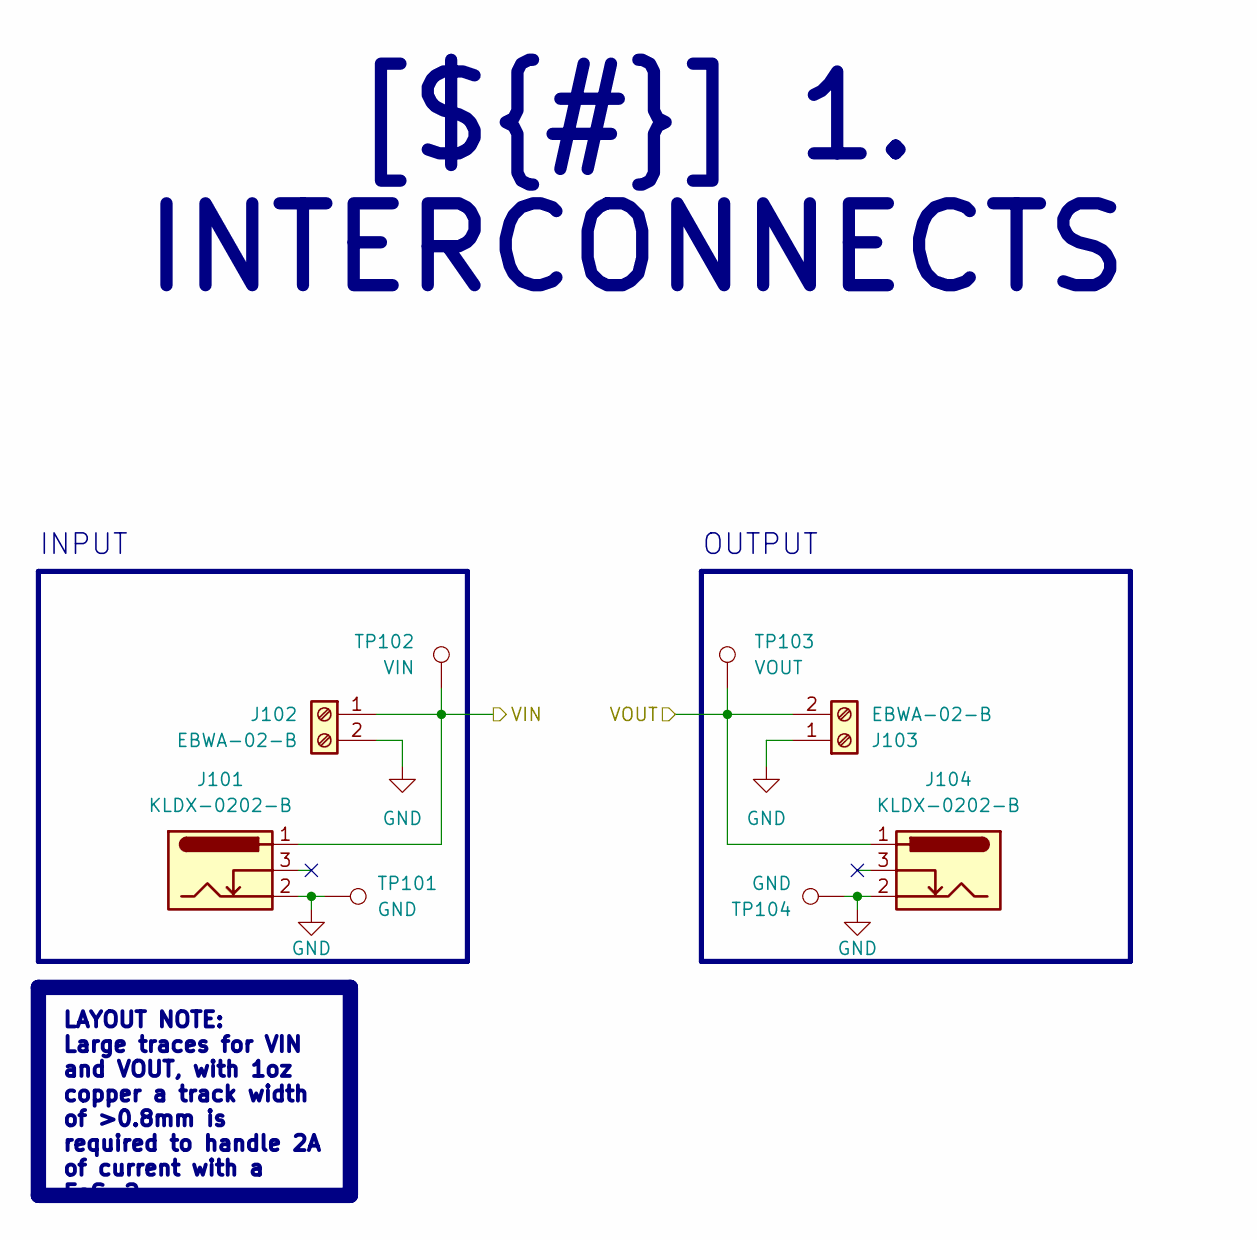
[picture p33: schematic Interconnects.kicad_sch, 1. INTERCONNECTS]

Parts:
J101, J104: KLDX-0202-B; BarrelJack_Kycon_KLDX-0202-xC_Horizontal; MPN KLDX-0202-B
J102, J103: EBWA-02-B; TerminalBlock_Phoenix_MKDS-1-2-3.81_1x02_P3.81mm_Horizontal; MPN EBWA-02-B
TP101, TP104: GND; TestPoint_THTPad_1.5x1.5mm_Drill0.7mm
TP102: VIN; TestPoint_Pad_D1.0mm
TP103: VOUT; TestPoint_Pad_D1.0mm

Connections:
/ARCHITECTURE/1. INTERCONNECTS/VIN: J101.1, J102.1, TP102.1; also elsewhere on the board
/ARCHITECTURE/1. INTERCONNECTS/VOUT: J103.2, J104.1, TP103.1; also elsewhere on the board
GND: J101.2, J102.2, J103.1, J104.2, TP101.1, TP104.1; also elsewhere on the board

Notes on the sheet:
INPUT
OUTPUT
LAYOUT NOTE: Large traces for VIN and VOUT, with 1oz copper a track width of >0.8mm is required to handle 2A of current with a FoS=2.
[${#}] ${TITLE}

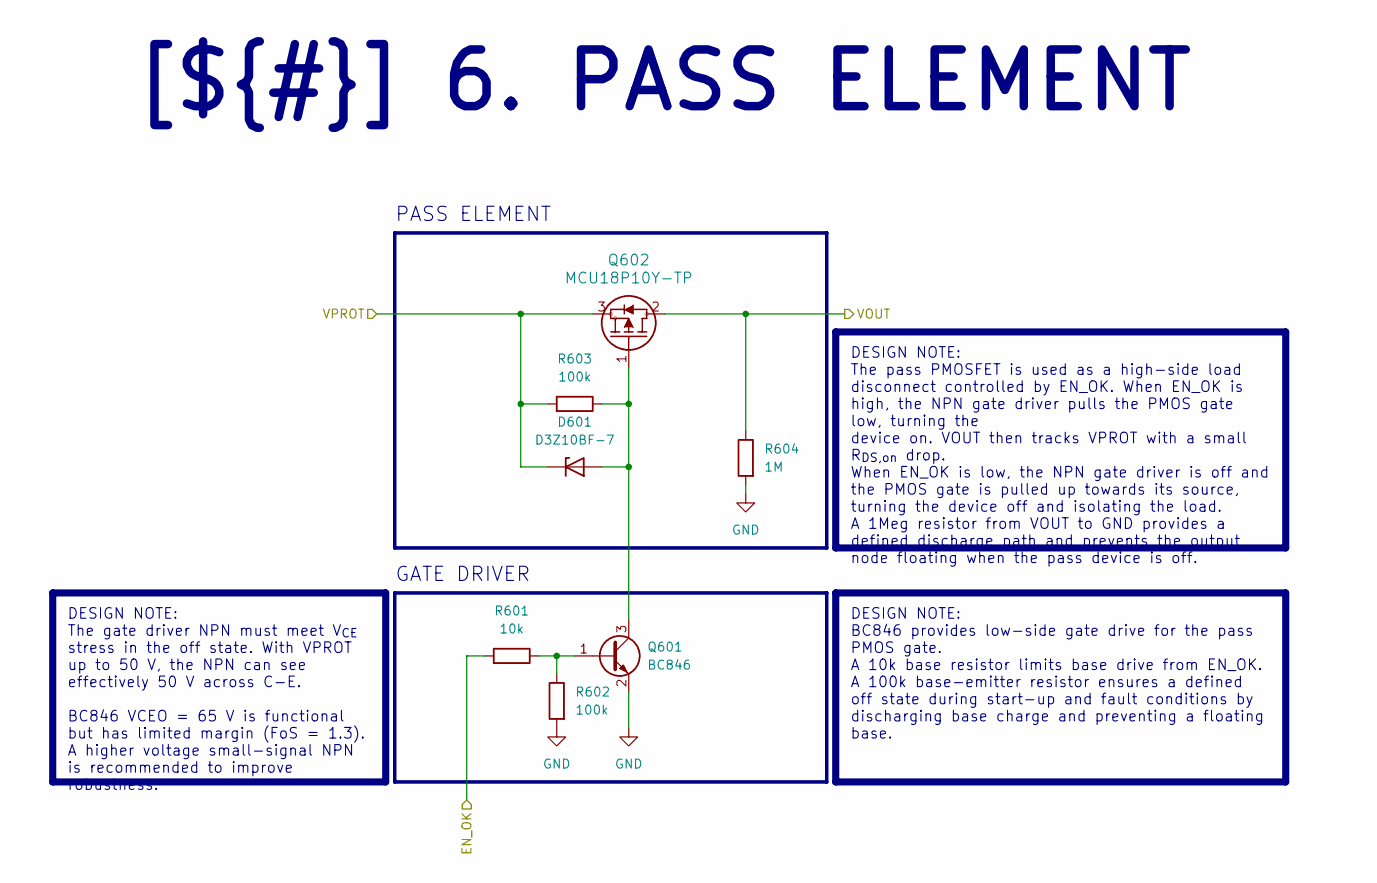
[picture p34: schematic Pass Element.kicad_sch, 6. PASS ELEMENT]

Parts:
D601: D3Z10BF-7; D_SOD-323_HandSoldering; MPN D3Z10BF-7
Q601: BC846; SOT-23; MPN BC846
Q602: MCU18P10Y-TP; DPAK_MCC; MPN MCU18P10Y-TP
R601: 10k; R_1206_3216Metric_Pad1.30x1.75mm_HandSolder
R602, R603: 100k; R_1206_3216Metric_Pad1.30x1.75mm_HandSolder
R604: 1M; R_1206_3216Metric_Pad1.30x1.75mm_HandSolder

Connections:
/ARCHITECTURE/1. INTERCONNECTS/VOUT: Q602.2, R604.1; also elsewhere on the board
/ARCHITECTURE/2. POLARITY PROTECTION/VPROT: D601.1 (K), Q602.3, R603.2; also elsewhere on the board
/ARCHITECTURE/5. COMPARATOR/EN_OK: R601.2; also elsewhere on the board
GND: Q601.2 (E), R602.2, R604.2; also elsewhere on the board
unnamed: D601.2 (A), Q601.3 (C), Q602.1, R603.1
unnamed: Q601.1 (B), R601.1, R602.1

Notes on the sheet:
PASS ELEMENT
GATE DRIVER
DESIGN NOTE: The pass PMOSFET is used as a high-side load disconnect controlled by EN_OK. When EN_OK is high, the NPN gate driver pulls the PMOS gate low, turning the device on. VOUT then tracks VPROT with a small R_{DS,on} drop. When EN_OK is low, the NPN gate driver is off and the PMOS gate is pu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
DESIGN NOTE: The gate driver NPN must meet V_{CE} stress in the off state. With VPROT up to 50 V, the NPN can see effectively 50 V across C-E. BC846 VCEO = 65 V is functional but has limited margin (FoS = 1.3). A higher voltage small-signal NPN is recommended to improve robustness.
DESIGN NOTE: BC846 provides low-side gate drive for the pass PMOS gate. A 10k base resistor limits base drive from EN_OK. A 100k base-emitter resistor ensures a defined off state during start-up and fault conditions by discharging base charge and preventing a floating base.
[${#}] ${TITLE}

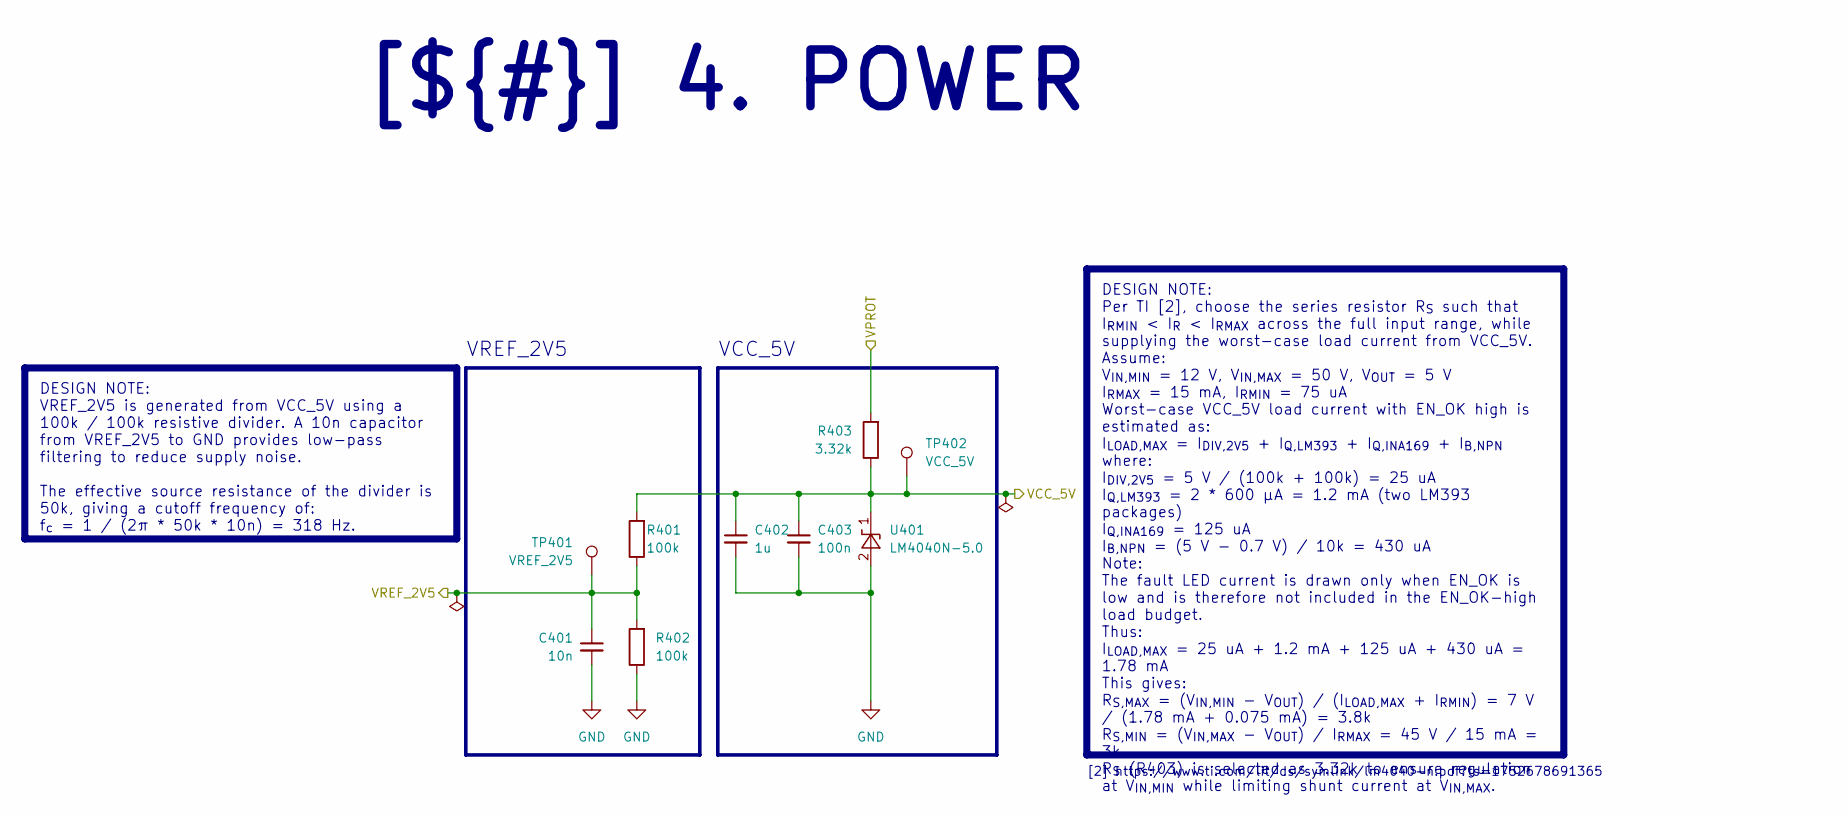
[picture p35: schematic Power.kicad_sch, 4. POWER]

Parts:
C401: 10n; C_0603_1608Metric_Pad1.08x0.95mm_HandSolder; Voltage_Rating 50V; Tolerance 10%; MPN C1608X7R1H103KT
C402: 1u; C_0603_1608Metric_Pad1.08x0.95mm_HandSolder; Voltage_Rating 6.3V; Tolerance 10%; MPN C1608X5R0J105KT
C403: 100n; C_0603_1608Metric_Pad1.08x0.95mm_HandSolder; Voltage_Rating 16V; Tolerance 10%; MPN C1608X7R1C104KT
R401, R402: 100k; R_1206_3216Metric_Pad1.30x1.75mm_HandSolder
R403: 3.32k; R_1206_3216Metric_Pad1.30x1.75mm_HandSolder
TP401: VREF_2V5; TestPoint_Pad_D1.0mm
TP402: VCC_5V; TestPoint_Pad_D1.0mm
U401: LM4040N-5.0; SOT-23; MPN LM4040CIM3-5.0/NOPB

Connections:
/ARCHITECTURE/2. POLARITY PROTECTION/VPROT: R403.2; also elsewhere on the board
GND: C401.2, C402.2, C403.2, R402.1, U401.2 (A); also elsewhere on the board
VCC_5V: C402.1, C403.1, R401.2, R403.1, TP402.1, U401.1 (K); also elsewhere on the board
VREF_2V5: C401.1, R401.1, R402.2, TP401.1; also elsewhere on the board

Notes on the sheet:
VREF_2V5
VCC_5V
[2] https://www.ti.com/lit/ds/symlink/lm4040-n.pdf?ts=1752678691365
DESIGN NOTE: VREF_2V5 is generated from VCC_5V using a 100k / 100k resistive divider. A 10n capacitor from VREF_2V5 to GND provides low-pass filtering to reduce supply noise. The effective source resistance of the divider is 50k, giving a cutoff frequency of: f_{c} = 1 / (2π * 50k * 10n) = 318 Hz.
DESIGN NOTE: Per TI [2], choose the series resistor R_{S} such that I_{RMIN} < I_{R} < I_{RMAX} across the full input range, while supplying the worst-case load current from VCC_5V. Assume: V_{IN,MIN} = 12 V, V_{IN,MAX} = 50 V, V_{OUT} = 5 V I_{RMAX} = 15 mA, I_{RMIN} = 75 uA Worst-case VCC_5V load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
[${#}] ${TITLE}

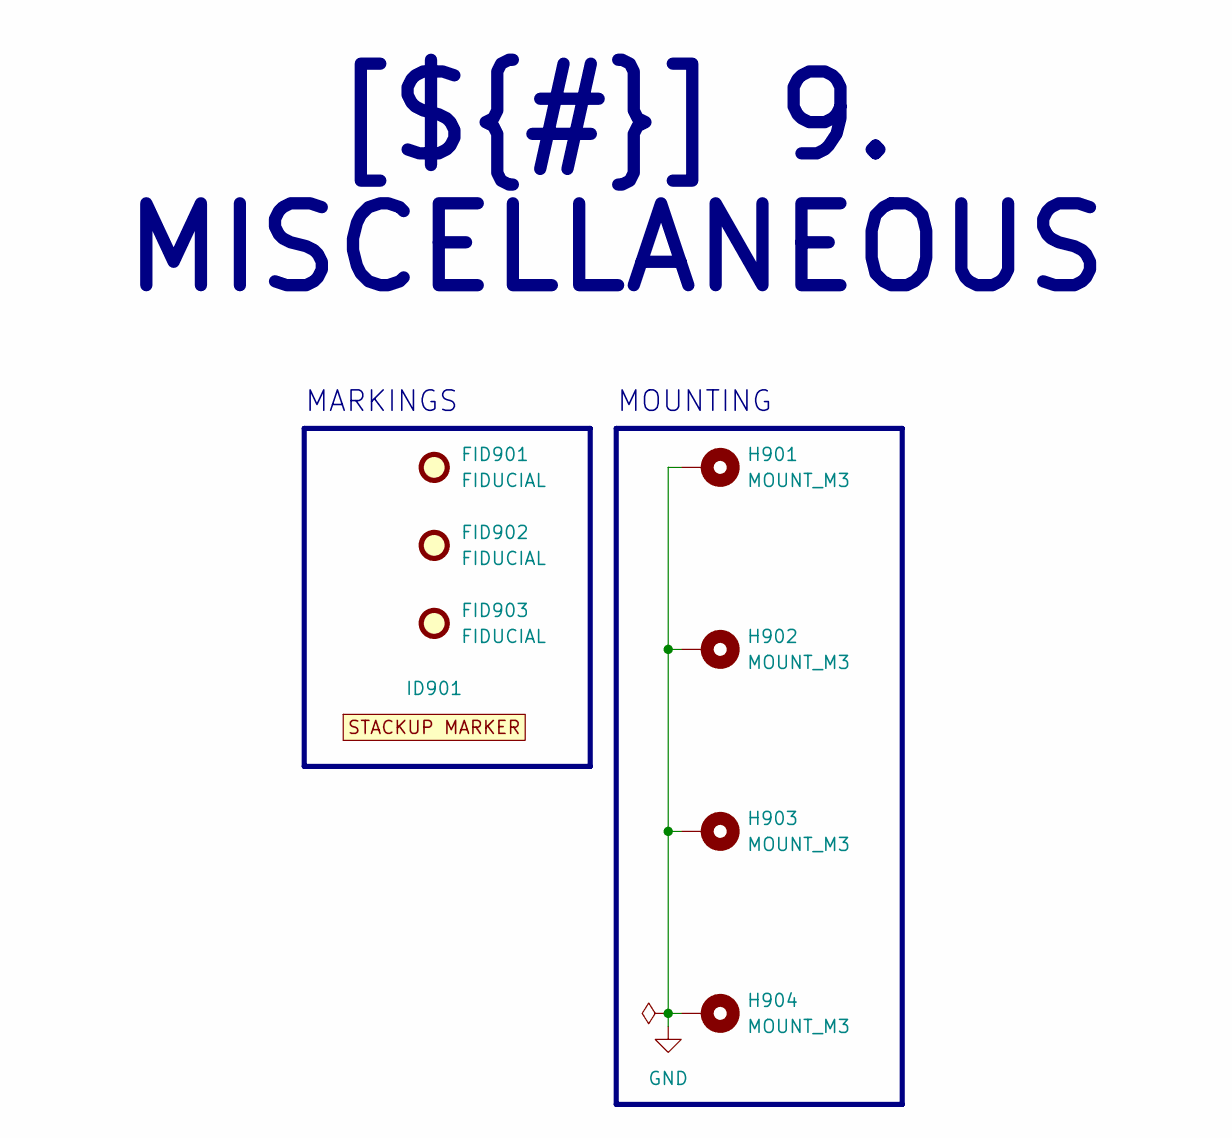
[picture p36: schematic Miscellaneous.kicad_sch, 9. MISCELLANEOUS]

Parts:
FID901, FID902, FID903: FIDUCIAL; Fiducial_1mm_Mask2mm
H901, H902, H903, H904: MOUNT_M3; MountingHole_3.2mm_M3_ISO7380_Pad
ID901: BOARD_STACKUP_MARKER; STACKUP_ID_2L_SML

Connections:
GND: H901.1, H902.1, H903.1, H904.1; also elsewhere on the board

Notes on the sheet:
MOUNTING
MARKINGS
[${#}] ${TITLE}

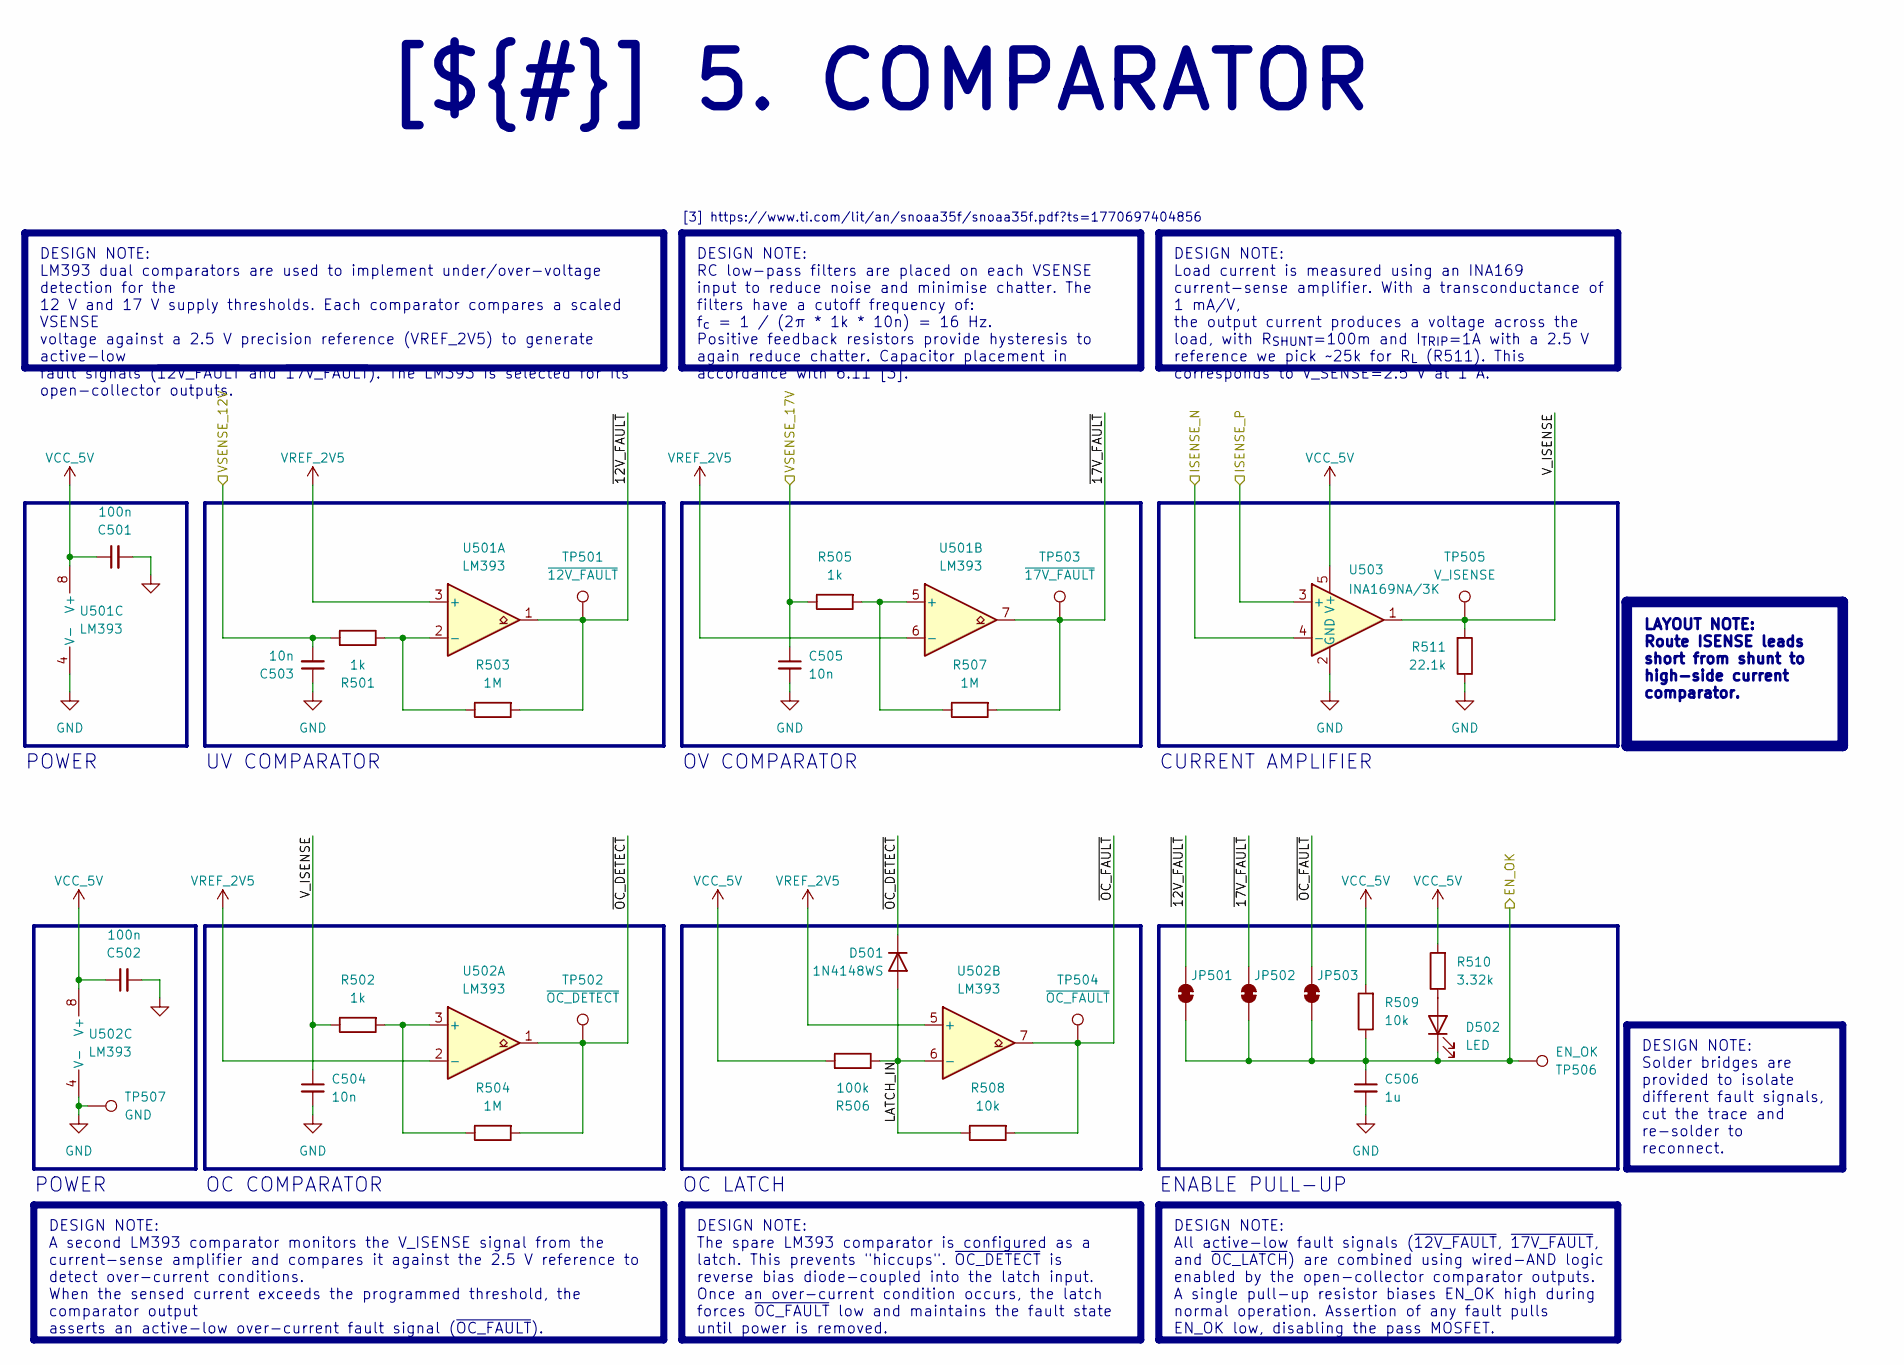
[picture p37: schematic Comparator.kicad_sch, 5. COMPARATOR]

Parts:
C501, C502: 100n; C_0603_1608Metric_Pad1.08x0.95mm_HandSolder; Voltage_Rating 16V; Tolerance 10%; MPN C1608X7R1C104KT
C503, C504, C505: 10n; C_0603_1608Metric_Pad1.08x0.95mm_HandSolder; Voltage_Rating 50V; Tolerance 10%; MPN C1608X7R1H103KT
C506: 1u; C_0603_1608Metric_Pad1.08x0.95mm_HandSolder; Voltage_Rating 6.3V; Tolerance 10%; MPN C1608X5R0J105KT
D501: 1N4148WS; D_SOD-323; MPN 1N4148WS
D502: LED; LED_0805_2012Metric_Pad1.15x1.40mm_HandSolder; MPN LTST-C170KRKT
JP501, JP502, JP503: SolderJumper_2_Bridged; SolderJumper-2_P1.3mm_Bridged_Pad1.0x1.5mm
R501, R502, R505: 1k; R_1206_3216Metric_Pad1.30x1.75mm_HandSolder
R503, R504, R507: 1M; R_1206_3216Metric_Pad1.30x1.75mm_HandSolder
R506: 100k; R_1206_3216Metric_Pad1.30x1.75mm_HandSolder
R508, R509: 10k; R_1206_3216Metric_Pad1.30x1.75mm_HandSolder
R510: 3.32k; R_1206_3216Metric_Pad1.30x1.75mm_HandSolder
R511: 22.1k; R_1206_3216Metric_Pad1.30x1.75mm_HandSolder
TP501: ~{12V_FAULT}; TestPoint_Pad_D1.0mm
TP502: ~{OC_DETECT}; TestPoint_Pad_D1.0mm
TP503: ~{17V_FAULT}; TestPoint_Pad_D1.0mm
TP504: ~{OC_FAULT}; TestPoint_Pad_D1.0mm
TP505: V_ISENSE; TestPoint_Pad_D1.0mm
TP506: EN_OK; TestPoint_Pad_D1.0mm
TP507: GND; TestPoint_THTPad_1.5x1.5mm_Drill0.7mm
U501, U502: LM393; SOIC-8_3.9x4.9mm_P1.27mm; MPN LM393ADT
U503: INA169NA/3K; SOT-23-5; MPN INA169NA/3K

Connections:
/ARCHITECTURE/2. POLARITY PROTECTION/VPROT: U503.3 (+); also elsewhere on the board
/ARCHITECTURE/3. SENSING/ISENSE_N: U503.4 (-); also elsewhere on the board
/ARCHITECTURE/3. SENSING/VSENSE_12V: C503.2, R501.2; also elsewhere on the board
/ARCHITECTURE/3. SENSING/VSENSE_17V: C505.1, R505.1; also elsewhere on the board
/ARCHITECTURE/5. COMPARATOR/EN_OK: C506.1, D502.1 (K), JP501.1 (A), JP502.1 (A), JP503.1 (A), R509.1, TP506.1; also elsewhere on the board
/ARCHITECTURE/5. COMPARATOR/LATCH_IN: D501.2 (A), R506.1, R508.1, U502.6 (-)
/ARCHITECTURE/5. COMPARATOR/V_ISENSE: C504.1, R502.1, R511.2, TP505.1, U503.1
/ARCHITECTURE/5. COMPARATOR/~12V_FAULT: JP501.2 (B), R503.2, TP501.1, U501.1
/ARCHITECTURE/5. COMPARATOR/~17V_FAULT: JP502.2 (B), R507.2, TP503.1, U501.7
/ARCHITECTURE/5. COMPARATOR/~OC_DETECT: D501.1 (K), R504.2, TP502.1, U502.1
/ARCHITECTURE/5. COMPARATOR/~OC_FAULT: JP503.2 (B), R508.2, TP504.1, U502.7
GND: C501.2, C502.2, C503.1, C504.2, C505.2, C506.2, R511.1, TP507.1, U501.4 (V-), U502.4 (V-), U503.2 (GND); also elsewhere on the board
unnamed: D502.2 (A), R510.1
unnamed: R501.1, R503.1, U501.2 (-)
unnamed: R505.2, R507.1, U501.5 (+)
unnamed: R502.2, R504.1, U502.3 (+)
VCC_5V: C501.1, C502.1, R506.2, R509.2, R510.2, U501.8 (V+), U502.8 (V+), U503.5 (V+); also elsewhere on the board
VREF_2V5: U501.3 (+), U501.6 (-), U502.2 (-), U502.5 (+); also elsewhere on the board

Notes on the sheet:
OV COMPARATOR
OC COMPARATOR
UV COMPARATOR
ENABLE PULL-UP
[3] https://www.ti.com/lit/an/snoaa35f/snoaa35f.pdf?ts=1770697404856
POWER
OC LATCH
CURRENT AMPLIFIER
DESIGN NOTE: Solder bridges are provided to isolate different fault signals, cut the trace and re-solder to reconnect.
DESIGN NOTE: RC low-pass filters are placed on each VSENSE input to reduce noise and minimise chatter. The filters have a cutoff frequency of: f_{c} = 1 / (2π * 1k * 10n) = 16 Hz. Positive feedback resistors provide hysteresis to again reduce chatter. Capacitor placement in accordance with 6.11 [3].
LAYOUT NOTE: Route ISENSE leads short from shunt to high-side current comparator.
DESIGN NOTE: All active-low fault signals (~{12V_FAULT}, ~{17V_FAULT}, and ~{OC_LATCH}) are combined using wired-AND logic enabled by the open-collector comparator outputs. A single pull-up resistor biases EN_OK high during normal operation. Assertion of any fault pulls EN_OK low, disabling the pas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
DESIGN NOTE: Load current is measured using an INA169 current-sense amplifier. With a transconductance of 1 mA/V, the output current produces a voltage across the load, with R_{SHUNT}=100m and I_{TRIP}=1A with a 2.5 V reference we pick ~25k for R_{L} (R511). This corresponds to V_SENSE=2.5 V at 1 A.
DESIGN NOTE: A second LM393 comparator monitors the V_ISENSE signal from the current-sense amplifier and compares it against the 2.5 V reference to detect over-current conditions. When the sensed current exceeds the programmed threshold, the comparator output asserts an active-low over-current faul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
DESIGN NOTE: LM393 dual comparators are used to implement under/over-voltage detection for the 12 V and 17 V supply thresholds. Each comparator compares a scaled VSENSE voltage against a 2.5 V precision reference (VREF_2V5) to generate active-low fault signals (~{12V_FAULT} and ~{17V_FAULT}). The L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
DESIGN NOTE: The spare LM393 comparator is configured as a latch. This prevents "hiccups". ~{OC_DETECT} is reverse bias diode-coupled into the latch input. Once an over-current condition occurs, the latch forces ~{OC_FAULT} low and maintains the fault state until power is removed.
[${#}] ${TITLE}

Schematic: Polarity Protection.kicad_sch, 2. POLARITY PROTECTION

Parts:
D201: D3Z10BF-7; D_SOD-323_HandSoldering; MPN D3Z10BF-7
Q201: MCU18P10Y-TP; DPAK_MCC; MPN MCU18P10Y-TP
R201, R202: 100k; R_1206_3216Metric_Pad1.30x1.75mm_HandSolder
TP201: VPROT; TestPoint_Pad_D1.0mm

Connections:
/ARCHITECTURE/1. INTERCONNECTS/VIN: Q201.2; also elsewhere on the board
/ARCHITECTURE/2. POLARITY PROTECTION/VPROT: D201.1 (K), Q201.3, R202.2, TP201.1; also elsewhere on the board
GND: R201.1; also elsewhere on the board
unnamed: D201.2 (A), Q201.1, R201.2, R202.1

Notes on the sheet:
[1] https://www.ti.com/lit/an/slvae57b/slvae57b.pdf?ts=1770319054914
DESIGN NOTE: This PMOS is acting as an ideal diode [1]. A 10 V zener from gate to source limits V_{GS} <= 10 V under all VIN and transient conditions to protect the PMOS. A 100k gate to source resistor stops the gate floating. A 100k gate pulldown resistor sets default state to OFF when no voltage 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
LAYOUT NOTE: Large traces for VPROT, with 1oz copper a track width of >0.8 mm is required to handle 2 A of current with a FoS = 2.
[${#}] ${TITLE}

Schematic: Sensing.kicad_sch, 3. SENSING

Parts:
R301: 100m; R_1206_3216Metric_Pad1.30x1.75mm_HandSolder; MPN KDV12FR100ET
R302: 39.2k; R_1206_3216Metric_Pad1.30x1.75mm_HandSolder
R303, R305: 10k; R_1206_3216Metric_Pad1.30x1.75mm_HandSolder
R304: 56.2k; R_1206_3216Metric_Pad1.30x1.75mm_HandSolder
TP301: GND; TestPoint_THTPad_1.5x1.5mm_Drill0.7mm
TP302: VSENSE_12V; TestPoint_Pad_D1.0mm
TP303: VSENSE_17V; TestPoint_Pad_D1.0mm

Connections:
/ARCHITECTURE/2. POLARITY PROTECTION/VPROT: R301.2; also elsewhere on the board
/ARCHITECTURE/3. SENSING/ISENSE_N: R301.1, R302.2, R304.2; also elsewhere on the board
/ARCHITECTURE/3. SENSING/VSENSE_12V: R302.1, R303.2, TP302.1; also elsewhere on the board
/ARCHITECTURE/3. SENSING/VSENSE_17V: R304.1, R305.2, TP303.1; also elsewhere on the board
GND: R303.1, R305.1, TP301.1; also elsewhere on the board

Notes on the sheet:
SHUNT
UV CONDITION
OV CONDITION
DESIGN NOTE: At VPROT = 17 V, the divider current is approximately I_{DIV} = VPROT / (R_{TOP} + R_{BOT}) = 17 V / 68k = 250 uA, Which is sufficient for the input bias of the comparators.
DESIGN NOTE: The over-current trip point is set to I_{TRIP} = 1 A. With a shunt resistor value of R_{SHUNT} = 100m, the differential shunt voltage at the trip point is: V_{SENSE} = I * R_{SHUNT} = 1 A * 100m = 100 mV.
DESIGN NOTE: R_{BOT} is chosen as 10k to provide a low-impedance sense node with reasonable divider current. Solving for R_{TOP} gives: R_{TOP} = R_{BOT} * (V_{TRIP} / VREF_2V5 − 1) With VREF_2V5 = 2.5 V and RBOT = 10k: For V_{TRIP} = 12 V: R_{TOP} = 10k * (12 / 2.5 − 1) = 38k For V_{TRIP} = 17 V: 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
DESIGN NOTE: The protected input voltage VPROT is scaled to sense voltage VSENSE using a divider for comparison against VREF_2V5. VSENSE = VPROT * R_{BOT} / (R_{TOP} + R_{BOT}) The comparator trips when VSENSE = VREF_2V5, giving a trip voltage of V_{TRIP} = VREF_2V5 * (R_{TOP} + R_{BOT}) / R_{BOT}.
[${#}] ${TITLE}

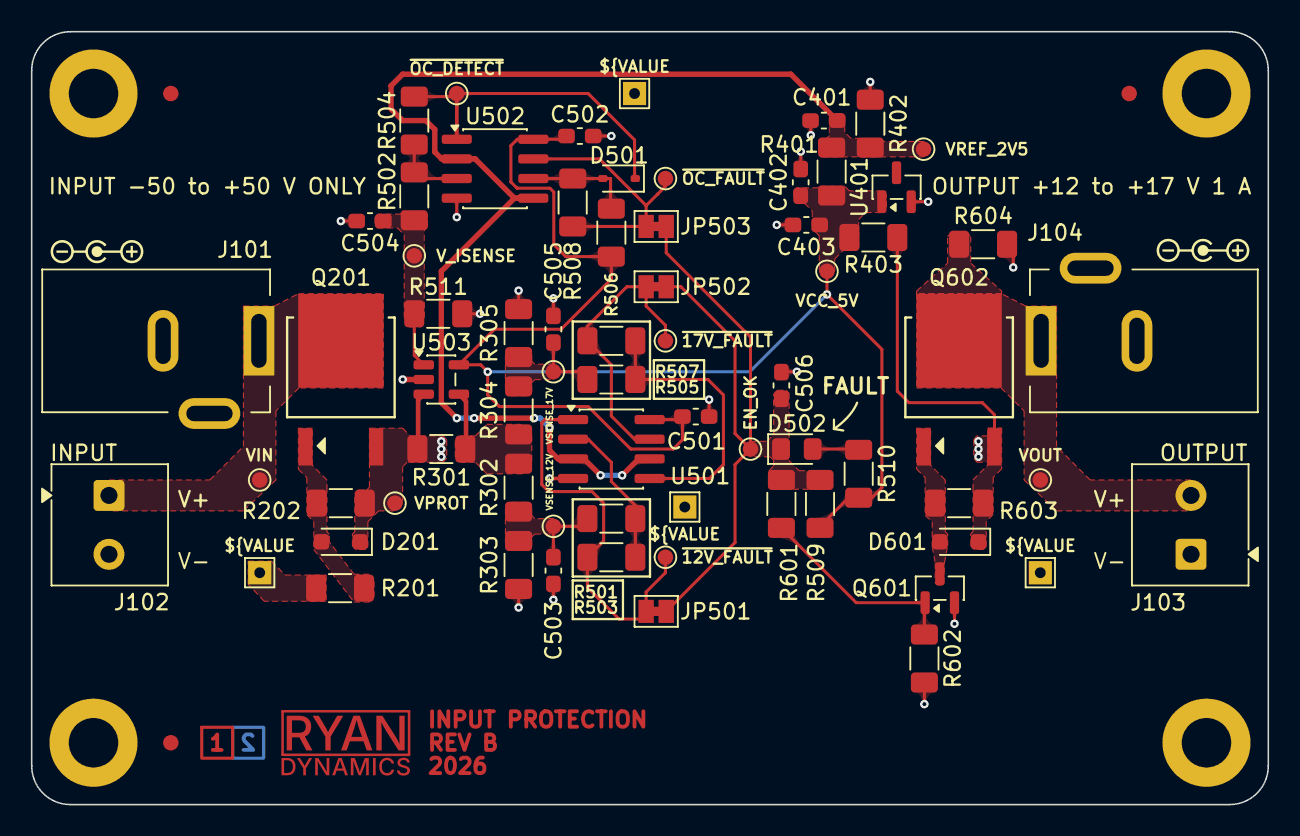
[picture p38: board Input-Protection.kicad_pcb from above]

Board: 2 copper layers, 80.0 x 50.0 mm, 77 parts (0 on the bottom side), 23 nets.

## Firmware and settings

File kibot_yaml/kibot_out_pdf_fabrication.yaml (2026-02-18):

# KiBot output for generating Fabrication Document in PDF format
# https://kibot.readthedocs.io/en/latest/configuration/outputs/pcb_print.html

kibot:
  version: 1

outputs:
- name: @NAME@
  comment: '@COMMENT@'
  type: pcb_print
  category: '@DIR@'
  dir: '@DIR@'
  options:
    colored_pads: false
    colored_vias: false
    color_theme: '@COLOR_THEME@'
    output: '%f-fabrication%I%v.%x'
    format: 'PDF'
    title: '@DOC_TITLE@ DOCUMENT'
    realistic_solder_mask: false
    dpi: 1200
    dnf_filter: _kibom_dnf_Config
    frame_plot_mechanism: 'internal' 
    sheet_reference_layout: '@SHEET_WKS@'
    drill:
      unify_pth_and_npth: '@PTH_NPTH@'
      group_slots_and_round_holes: @GROUP_ROUND_SLOTS@
    include_table:
      outputs:
        - name: '@NAME_TP_TOP@'
          text_alignment: 'left'
          invert_columns_order: false
          border_width: 0.4
          header_rule_width: 0.2
          horizontal_rule_width: 0
          vertical_rule_width: 0.2
          top_rule_width: 0.2
          bottom_rule_width: 0.2
          column_spacing: 2
          force_font_width: 1.27 # mm
        - name: '@NAME_TP_BOTTOM@'
          text_alignment: 'right'
          invert_columns_order: true
          border_width: 0.4
          header_rule_width: 0.2
          horizontal_rule_width: 0
          vertical_rule_width: 0.2
          top_rule_width: 0.2
          bottom_rule_width: 0.2
          column_spacing: 2
          force_font_width: 1.27 # mm
        - name: '@NAME_IMPEDANCE_TABLE@'
          text_alignment: 'left'
          invert_columns_order: false
          border_width: 0.4
          header_rule_width: 0.2
          horizontal_rule_width: 0
          vertical_rule_width: 0.2
          top_rule_width: 0.2
          bottom_rule_width: 0.2
          row_spacing: 3
          column_spacing: 2
          row_spacing: 3
        - name: '@NAME_DRILL_TABLE@'
          text_alignment: 'left'
          invert_columns_order: false
          border_width: 0.4
          header_rule_width: 0.2
          horizontal_rule_width: 0
          vertical_rule_width: 0.2
          top_rule_width: 0.2
          bottom_rule_width: 0.2
          row_spacing: 3
          column_spacing: 2
          force_font_width: 1 # mm

    pages:
      - scaling: @SCALING@
        title: '@DOC_TITLE@'
        sheet: 'TOP FABRICATION (SCALE @SCALING@:1)'
        layer_var: 'TOP FABRICATION (SCALE @SCALING@:1)'
        sheet_reference_color: '#000000'
        colored_holes: true
        holes_color: "#FFFFFF"
        layers:
          - layer: Edge.Cuts
            color: '#000000'
          - layer: F.Cu
            color: '#F2F2F2'
          - layer: F.Mask
            color: '#E2E2E2'
          - layer: F.Paste
            color: '#E2E2E2'
          - layer: F.Silkscreen
            color: '#DBDBDB'
          - layer: F.Fab
            plot_footprint_refs: false
            plot_footprint_values: false
            color: '#818181'
          - layer: F.Dimensions
            color: '#000000'

      - scaling: @SCALING@
        mirror: true
        mirror_pcb_text: false
        title: '@DOC_TITLE@'
        sheet: 'BOTTOM FABRICATION (SCALE @SCALING@:1)'
        layer_var: 'BOTTOM FABRICATION (SCALE @SCALING@:1)'
        sheet_reference_color: '#000000'
        colored_holes: true
        holes_color: "#FFFFFF"
        layers:
          - layer: Edge.Cuts
            color: '#000000'
          - layer: B.Cu
            color: '#F2F2F2'
          - layer: B.Mask
            color: '#E2E2E2'
          - layer: B.Paste
            color: '#E2E2E2'
          - layer: B.Silkscreen
            color: '#DBDBDB'
          - layer: B.Fab
            plot_footprint_refs: false
            plot_footprint_values: false
            color: '#818181'
          - layer: B.Dimensions
            color: '#000000'

      - scaling: @SCALING@
        title: '@DOC_TITLE@'
        sheet: 'DRILL DRAWING (%lp)'
        layer_var: 'DRILL DRAWING %lp (SCALE @SCALING@:1)'
        sheet_reference_color: '#000000'
        colored_holes: true
        holes_color: "#FFFFFF"
        repeat_for_layer: '@LAYER_DRILL_MAP@'
        repeat_layers: 'drill_pairs'
        layers:
          - layer: '@LAYER_DRILL_MAP@'
            color: '#000000'
          - layer: 'Edge.Cuts'
            color: '#000000'
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

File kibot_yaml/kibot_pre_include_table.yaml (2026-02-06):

# KiBot preflight for Include Table feature
# https://kibot.readthedocs.io/en/latest/configuration/preflights/include_table.html

kibot:
  version: 1

preflight:
  include_table:
    outputs:
      - name: '@NAME_TP_TOP@'
        text_alignment: 'left'
        invert_columns_order: false
        border_width: 0.2
        header_rule_width: 0.2
        horizontal_rule_width: 0
        vertical_rule_width: 0
        top_rule_width: 0
        bottom_rule_width: 0
        column_spacing: 1
        # force_font_width: 1.27 # mm
      - name: '@NAME_TP_BOTTOM@'
        text_alignment: 'right'
        invert_columns_order: true
        border_width: 0.2
        header_rule_width: 0.2
        horizontal_rule_width: 0
        vertical_rule_width: 0
        top_rule_width: 0
        bottom_rule_width: 0
        column_spacing: 1
        # force_font_width: 1.27 # mm
      - name: '@NAME_COMP_COUNT@'
        text_alignment: 'left'
        invert_columns_order: false
        border_width: 0.2
        header_rule_width: 0.2
        horizontal_rule_width: 0
        vertical_rule_width: 0
        top_rule_width: 0
        bottom_rule_width: 0
        row_spacing: 3
        column_spacing: 1
      - name: '@NAME_IMPEDANCE_TABLE@'
        text_alignment: 'left'
        invert_columns_order: false
        border_width: 0.2
        header_rule_width: 0.2
        vertical_rule_width: 0
        top_rule_width: 0
        bottom_rule_width: 0
        row_spacing: 3
        column_spacing: 1

...
definitions:
  NAME_TP_TOP: csv_testpoints_top
  NAME_TP_BOTTOM: csv_testpoints_bottom
  NAME_COMP_COUNT: csv_comp_count
  NAME_IMPEDANCE_TABLE: csv_impedance_table

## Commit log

2026-02-06 feat: schematic mvp
    [Block Diagram.kicad_sch, Input-Protection.kicad_pcb, Input-Protection.kicad_sch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]
2026-02-06 fix: reset pcb layout
    [Input-Protection.kicad_pcb]
2026-02-06 Update Outputs
    [Input-Protection-bom.csv]
2026-02-07 feat: Added some design notes, fixed some values in line with sim
    [Block Diagram.kicad_sch, Input-Protection.kicad_pcb, Project Architecture.kicad_sch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]
2026-02-07 fix: fix properties of actives with MPN
    [Input-Protection.kicad_sch, Project Architecture.kicad_sch, Schematic.kicad_sch]
2026-02-07 fix: template changes
    [Block Diagram.kicad_sch, Input-Protection.kicad_sch, Revision History.kicad_sch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]
2026-02-07 fix: test font change from TNR to KiCad
2026-02-09 feat: preliminary pcb layout
    [Comparator.kicad_sch, Input-Protection.kicad_pcb, Input-Protection.kicad_sch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]
2026-02-09 fix: template issue
    [Input-Protection.kicad_pcb]
2026-02-09 fix: test point changes
    [Comparator.kicad_sch, Input-Protection.kicad_pcb, Power.kicad_sch]
2026-02-09 fix: bom improvements & more notes
    [Comparator.kicad_sch, Input-Protection.kicad_pcb, Interconnects.kicad_sch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]
2026-02-09 feat: ERC/DRC checks
    [Comparator.kicad_sch, Input-Protection.kicad_pcb, Interconnects.kicad_sch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]
2026-02-10 feat!: added OC protection, redesigned board from near scratch, size increase
    [Comparator.kicad_sch, Input-Protection.kicad_pcb, Interconnects.kicad_sch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]
2026-02-10 fix: adjust keying for images
    [Input-Protection.kicad_pcb]
2026-02-10 fix: fab layer clean up and bom additions
    [Comparator.kicad_sch, Input-Protection.kicad_pcb, Interconnects.kicad_sch]
2026-02-11 feat: revision A release
    [Input-Protection.kicad_pcb, Revision History.kicad_sch, Sensing.kicad_sch]
2026-02-11 Update Outputs (release)
    [Input-Protection-B_Mask.gbr, Input-Protection-B_Paste.gbr, Input-Protection-B_Silkscreen.gbr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]
2026-02-18 feat: revision B release
    [Comparator.kicad_sch, Input-Protection.kicad_pcb, Input-Protection.kicad_sch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]
